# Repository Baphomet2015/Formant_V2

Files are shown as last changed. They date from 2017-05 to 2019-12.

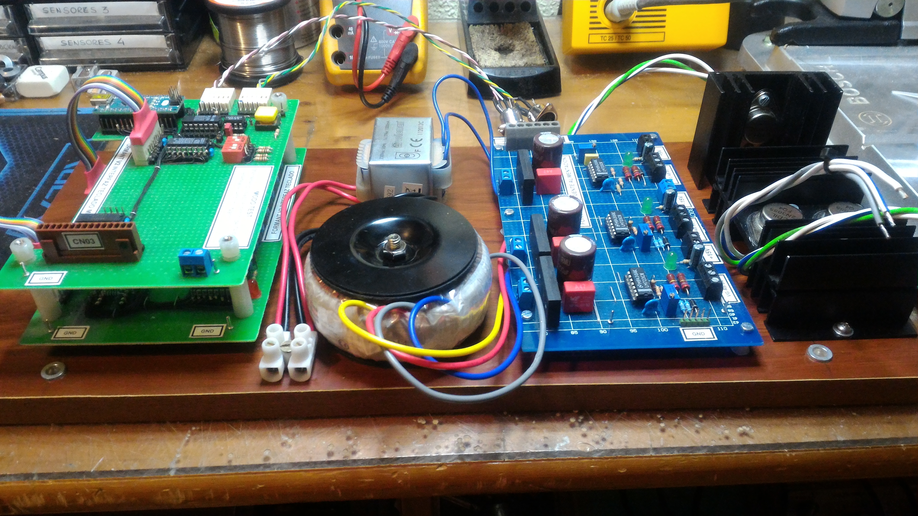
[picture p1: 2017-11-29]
Componentes_Mecanicos/Mueble_Racks/Fotos/P_20171127_214126.jpg

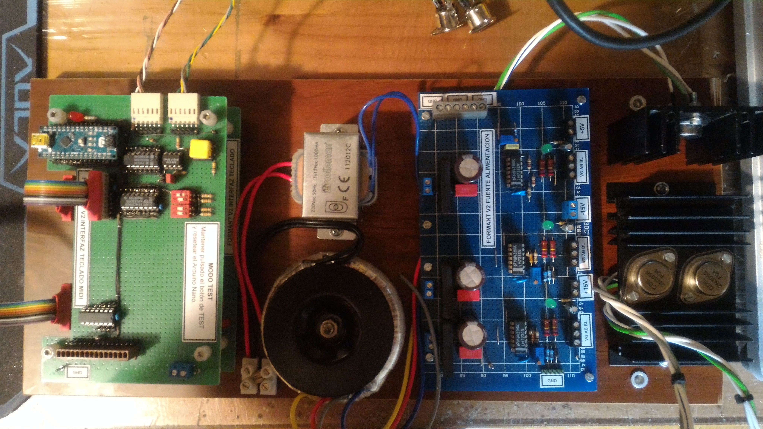
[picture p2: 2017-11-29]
Componentes_Mecanicos/Mueble_Racks/Fotos/P_20171127_214150.jpg

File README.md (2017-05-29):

# FORMANT V2.0
Proyecto de Sintetizador de música analógico.

En la edición de mayo de 1977 de la revista de electrónica **Elektor** se publicó el primero de una serie de artículos dedicados al Formant, un sofisticado sintetizador musical analógico modular con características y sonido profesionales.

En el presente proyecto se ha recopilado toda la documentación disponible en internet del Formant original, asi como de sus extensiones.

El objetivo de este proyecto, denominado **Formant 2.0** es:

 1. Mantener *esctríctamente* el diseño original del Formant de Elektor para obtener la calidad de sonido y prestaciones soportadas en el diseño original.
 
 2. Actualizar la documentación del diseño original del sintetizador Formant de Elektor para que sea posible su construcción hoy en día, con componentes actuales, sustituyendo los componentes obsoletos por otros disponibles actualmente en el mercado.
 
 3. Aportar en el nuevo diseño características de control digitales, basadas en microprocesador utilizando la plataforma **Arduino** y otros.

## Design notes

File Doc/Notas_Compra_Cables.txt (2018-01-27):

Sitio para comprar los cables de conexion entre modulos
https://www.modularsynthesizers.nl/c-2281945/patchcables-midi-cables/

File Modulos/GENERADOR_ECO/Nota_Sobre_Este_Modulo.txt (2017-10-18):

Para crear el generador de eco  se debe utilizar el Arduino DUE

http://www.frenki.net/2013/10/fast-analogread-with-arduino-due/
http://www.djerickson.com/arduino/due_adc.html

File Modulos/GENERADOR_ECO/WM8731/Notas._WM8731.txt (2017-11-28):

https://arduino.stackexchange.com/questions/12689/interfacing-wm8731-code-to-arduino-due

http://www.electan.com/codec-shield-p-4366.html

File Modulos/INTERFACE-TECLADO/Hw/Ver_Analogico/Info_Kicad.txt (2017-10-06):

Los ficheros de extensión,

 .pro
 .sch
 .lib
 .bak
 .kicad-pcb

Han sido realizados con el software Open Source de diseño de circuitos Kicad,

http://kicad-pcb.org/

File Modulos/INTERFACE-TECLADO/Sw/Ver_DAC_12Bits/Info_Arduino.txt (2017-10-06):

Los ficheros de extensión,

 .h
 .ino
 .lib

Ha sido realizados con el software Open Source de desarrollo Software/Hardware de la plataforma Arduino,

https://www.arduino.cc/

Se ha utilizado la versión 1.6.4

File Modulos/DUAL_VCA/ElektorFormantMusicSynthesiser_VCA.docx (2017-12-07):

070— FORMANT

chapter 10

voltage controlled amplifier (VCA)

This chapter continues the discussion of the tone-forming circuits with a description of the Dual VCA module, which can be used in conjunction with the envelope shaper for dynamic control signal amplitude, and
also for • riodic amplitude modulati • n of the signal waveform (tremolo

The voltag' controlled amplifier module is called • 'Dual VCA' because it contains t o cascaded, but independently con rolled, amplifiers. The gain of the first • mplifier is voltage controlled via an expo ential converter, and is used for envelop shaping. The second has a linear gain-c •ntrol input and is used for periodic mollulation of signal amplitude (tremolo). TI e VCA is provided with a modulation ndicator, which allows the best comp omise to be obtained between si nal-t

overload mar

Connection • f the VCA in the synthesiser slam

Figure 1 illustrates how the VCA fits into the synthesiser system. The VCA takes its input from the output of the VCF, which in turn takes its input signal from the VCOs.

The VCF and VCA can both be controlled by the ADS R envelope shapers, so allowing dynamic variation of tone colour and amplitude during the playing of a note. However, the VCF has a KOV input from the keyboard to allow it to function as a tracking filter, but the VCA lacks this, since there is no pitch related control of signal amplitude.

Using the VCA and the VC F

It may be interesting at this point to spend a little time comparing and contrasting the effects produced by the VCA and VCF, and discussing how they are used to complement one another in the synthesiser system. As an example, consider the case where the VCA and VCF are both controlled by the same waveform from the envelope shaper, consisting of a rapid attack and a relatively slow exponential decay, as shown in figure 2a, and are fed with a 440 Hz sawtooth waveform.

If the VCF is used alone in the lowpass
mode and the cutoff frequency of the

filter is initally set very low, the input signal will be completely suppressed. Yiviivem -wring Vitt Wank phase of the envelope control waveform the cutoff frequency of the filter vill rise very rapidly, and the amlitude and harmonic content of the note will both increase as first the fundamental, then the harmonics, are passed. During the slow decay phase the note will die away slowly as the cutoff frequency falls, starting with the higher harmonics, then the lower harmonics, anc finally the fundamental. The variatioi in turnover frequency of the filter is illustrated in figure 2b.

The tone thus produced .s not unlike that of a clavichord, or of a piano which has had drawing pins stuck into the hammers to produce a jaagly, honky-tonk effect.

If the same signal and control waveforms are fed to the VCA, the signal amplitude will rise rapidly as the gain increases during the attack phase, and will fall away slowly during the decay phase. However, the harmonic content of

signal will remain unaltered The sound thus produced is similar to that of percussion instruments stch as the piano and xylophone.

By varying the attack and decay times of the envelope shapers a vide variety of tone colour and amplitude dynamics can be produced using tin VCF and VCA in conjunction.

VCA design considerations

The dual VCA contains two amplifiers whose gains are independently voltage-controllable, and the design 3f the VCA poses certain problems, the principal one being that of obtaining adequate dynamic range, as is illustrated in figures 3a to 3d.

Figure 3a shows a control contour from the envelope shaper. At the peak of the control contour the VCA must have a finite maximum gain, which, for the purposes of the discussion, it will be assumed is unity, or 0 dB. At the beginning and end of the note the signal must be inaudible, which means that the gain of the amplifier should ideally be infinitesimally small at these moments in time. In practice, if the gain is around —70 dB•then this will be adequate.

What happens if the dynamic range is inadequate is shown in figure 3b. Suppose the gain of the amplifier can be varied by a range of only 40 dB or so, and is set to 0 dB on the peak of the control contour. At the start and end of the note the signal will only be 40 dB down, and if the note is being played fortissimo then this residual signal will still be quite audible.

Another fault of badly-designed VCAs is illustrated in figure 3c. In this example, the VCA cuts off completely below a certain level of control voltage, and so misses part of the attack and decay period of the note. This might be said to be the opposite fault to that of

figure 3b, though it is not directly related to dynamic range, but rather to extreme non-linearity of the control characteristic.

Returning to the example of the VCA with only 40 dB dynamic range, if the gain is adjusted so that the signal is inaudible at the beginning and end of the note (i.e. some 70 dB down), it will only be able to increase by 40 dB when the control voltage is applied, instead of the 70 dB required to reach the 0 dB level. The result is an amplitude plateau, as shown in figure 3d.

As mentioned briefly earlier, control of the envelope shaping section of the VCA is carried out exponentially. This is to compensate for the logarithmic loudness response of the human ear. On the other hand control of the periodic amplitude modulation section (tremolo) is linear, since this gives the 'softest' and `sweetest' sound to the tremolo effect.

Principle of the Formant VCA

The VCA in Formant uses the CA3080 OTA as the controllable amplifier, as in the VCF. The principle of the Formant VCA is illustrated in figure 4. The input voltage Ui is converted to a proportional output current Io = gm • 14 However, since we are interested in voltage amplification this output current must be converted into an output voltage, and this is done simply by feeding the current through a load resistor RL to produce an output voltage U0 = gm • Ui • RL.

The transconductance of the amplifier, gm, may of course be varied by a control current IABc, as explained in chapter 6, and the gain of the VCA may thus be controlled — although at this stage of course it is a CCA!

The output of the OTA may not drive any external load in addition to RL, as this would lower the load impedance and alter the gain, so the output of the OTA is connected to a voltage follower/buffer with a high input impedance.

Both sections of the VCA operate on the same principle. However, only the output of the second OTA is buffered, since it is this output that is connected to any external loads. As the output of the first OTA has no external connection it is simply connected to the input of the second OTA.

The OTA has one disadvantage that cannot be ignored. As mentioned in the previous chapter, its linearity is good only for small input signals (typically ± 10 mV) which is why a large degree of input signal attenuation is required. This means that the signal-to-noise ratio is not exceptionally good, and for this reason it is best to use the VCA with the largest possible input signal consistent with low distortion. A modulation indicator is provided, which allows the best compromise to be obtained between excessive noise, at low input levels, and distortion at high input levels.

FORMANT — 071

Figure 1. Block diagram illustrating how the
VCA fits into the Formant synthesiser system.

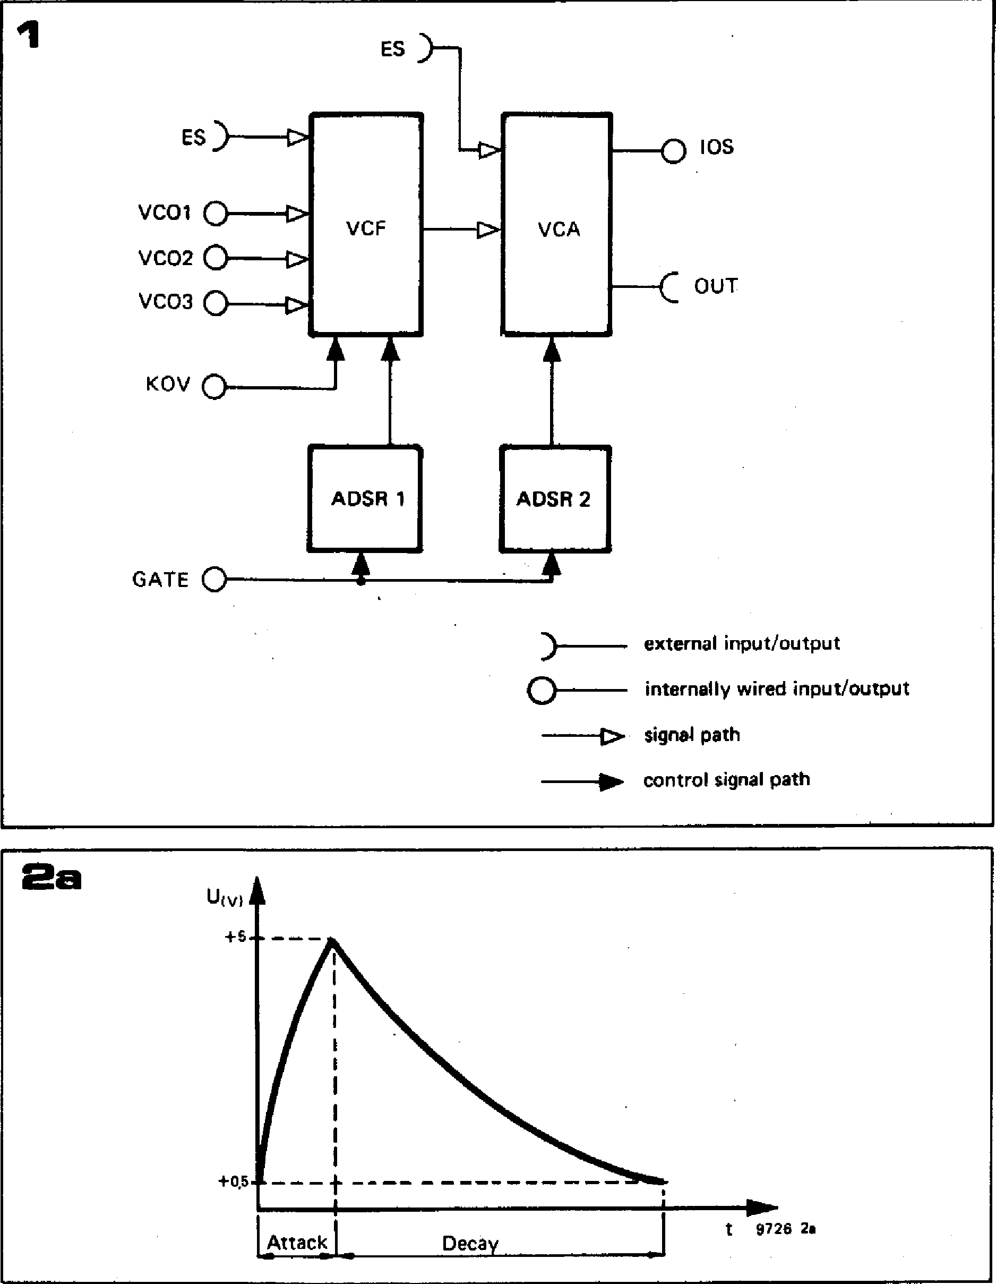
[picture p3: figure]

VCF

VCA

+5

ADSR 1

ADSR 2

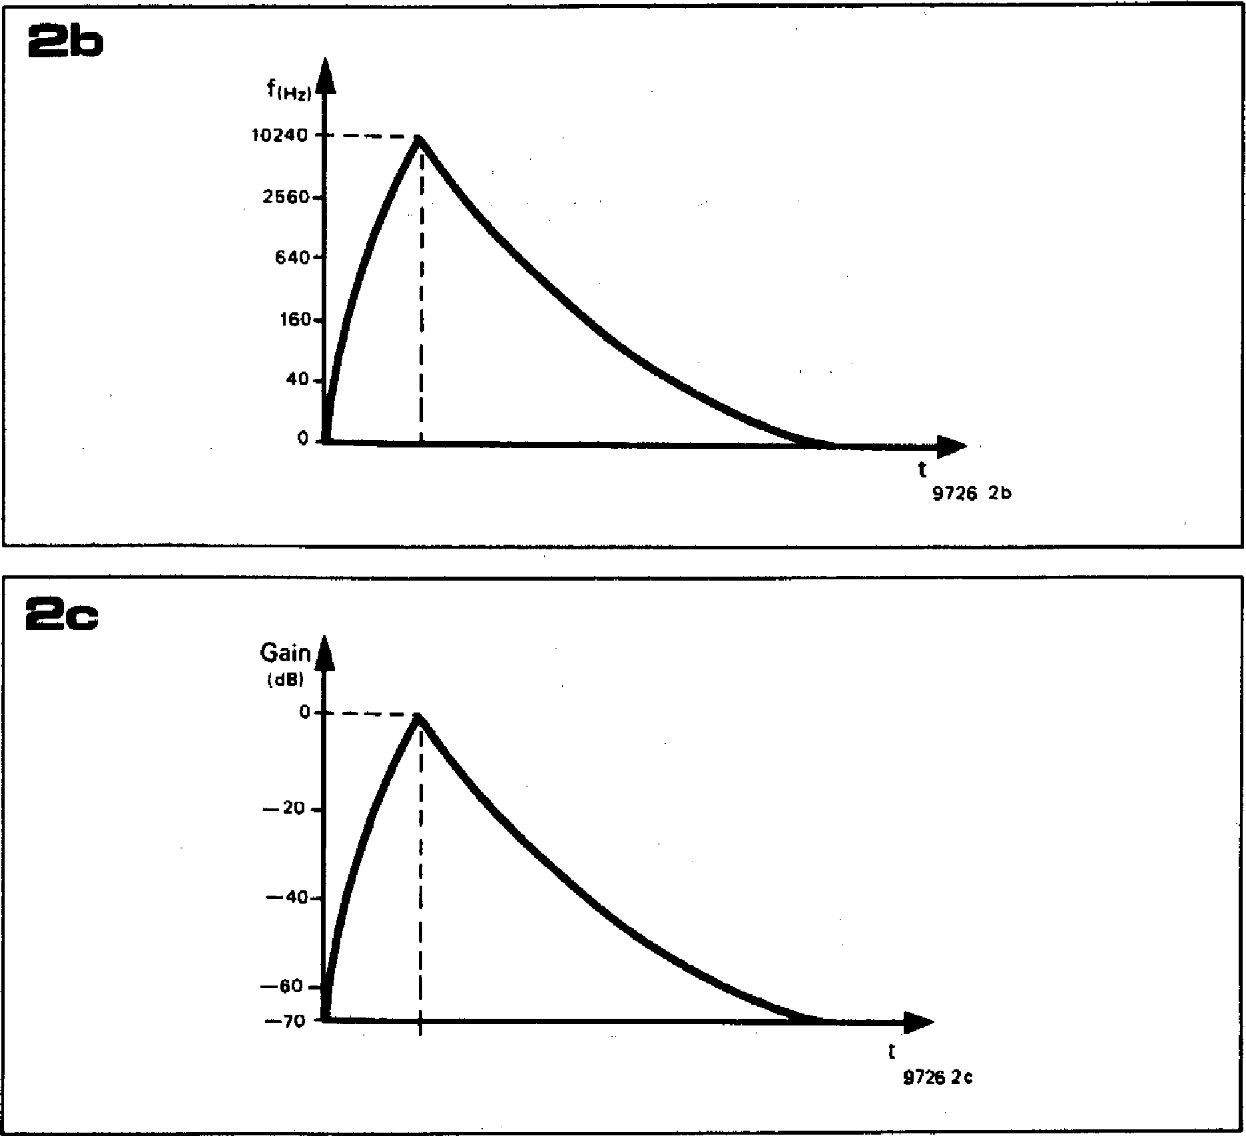
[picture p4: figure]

Figure 2. Envelope control of the VCF and VCA. The attack-decay contour of figure 2a, when applied to the VCF, varies the turnover frequency of the filter, which provides dynamic alteration in the tone colour of the sound (figure 2b). When applied to the VCA, the envelope contour alters the gain of the VCA, and thus the amplitude of the sound (figure 2c).

Circuit of the. VCA

The complete circuit of the VCA is given in figure 5. The exponential converter built around IC1 and 1C3 will immediately be recognised, since it is very similar to that used in the VCF. The input configuration, however, is much simpler, there being but one external input, ENV, from the envelope shaper. If required this can be switched out by setting Si in position 'a', in which case a fixed gain results.

The gain/control voltage characteristic of the VCF is roughly 12 dB/volt, but as the use of the word 'roughly' suggests, the accuracy of this characteristic is relatively unimportant, unlike the octave/volt characteristics of the VCO and VCF. The ear is much less critical of amplitude errors than it is of frequency errors. The dB/volt characteristic of the VCA may be adjusted by P2, whilst P1 is an offset trimmer. The output current of the exponential converter controls the gain of the first OTA, 106.

The linear voltage-current converter is constructed around IC2, which is connected as an inverting, summing amplifier. An input signal may be fed to P4 via the AM input socket, and a DC input voltage is available from P3 (`Gain'). Both these input voltages cause proportional currents to flow through R12 and R 13, and since these currents cannot flow into the inverting input of the op-amp they flow round the feedback loop through T 1, and into the control input of IC7.

The audio signal to the VCA comes either from the permanently wired internal signal input (IS) or from the external signal socket (ES) on the front panel of the VCA module. The amplitude of the external input signal is controlled by P5, whereas the amplitude of the internal signal is controlled at the IOS output of the VCF, by P6 of the VCF module.

IC4 functions as a summing amplifier with a gain of —1, and the signal level at the output of IC4 is monitored by the modulation indicator constructed around IC5. This is a non-inverting amplifier feeding a bridge rectifier D1 to D4, the output of which drives the modulation indicator LED D5. Once the

072 — FORMANT

peak signal level at the output of 105 exceeds the combined knee voltages of 131 plus D5 plus D4 (or D3 plus D5 plus D2) then the LED will start to glow and will glow brighter as the signal level increases. P6 is used to adjust the gain of 105 so that D5 starts to glow at the signal level where overmodulation begins to occur.

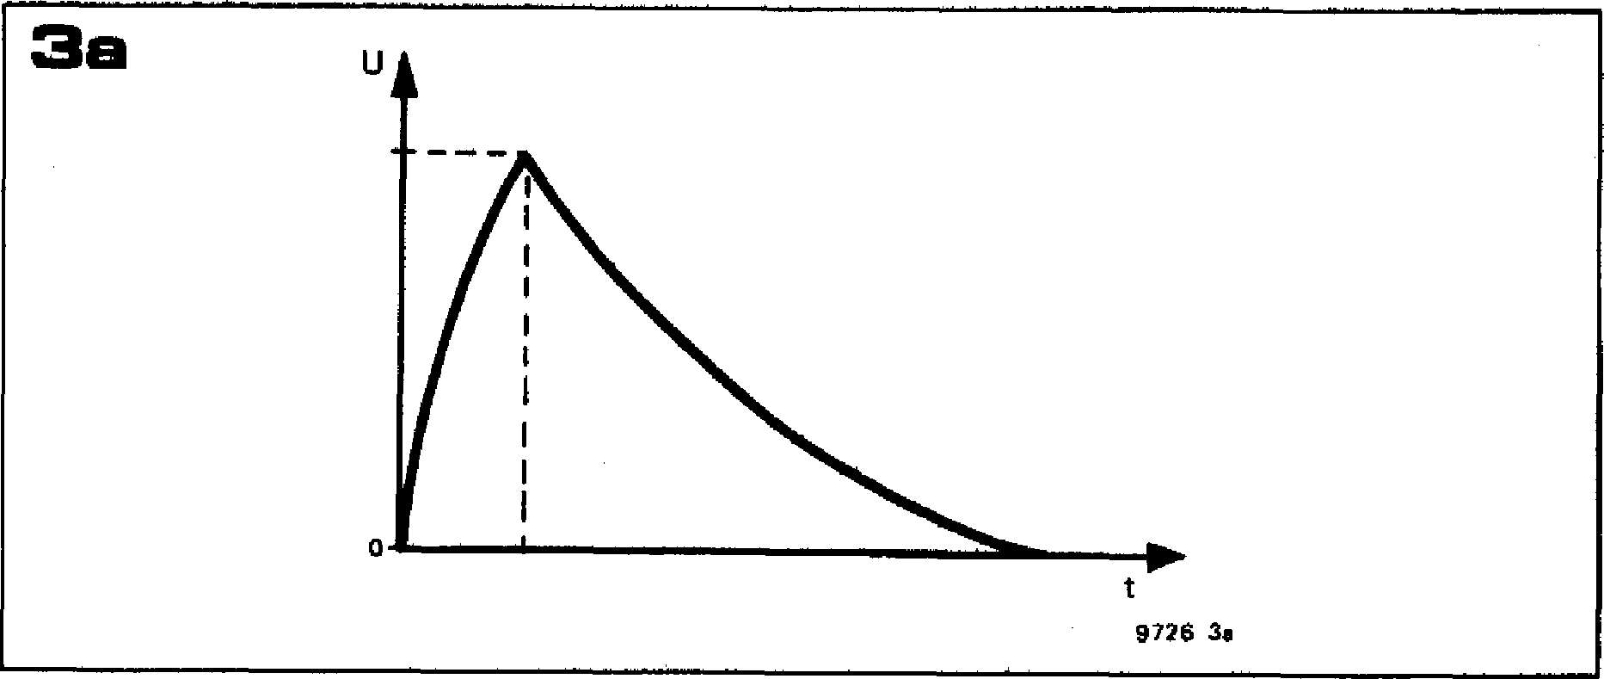
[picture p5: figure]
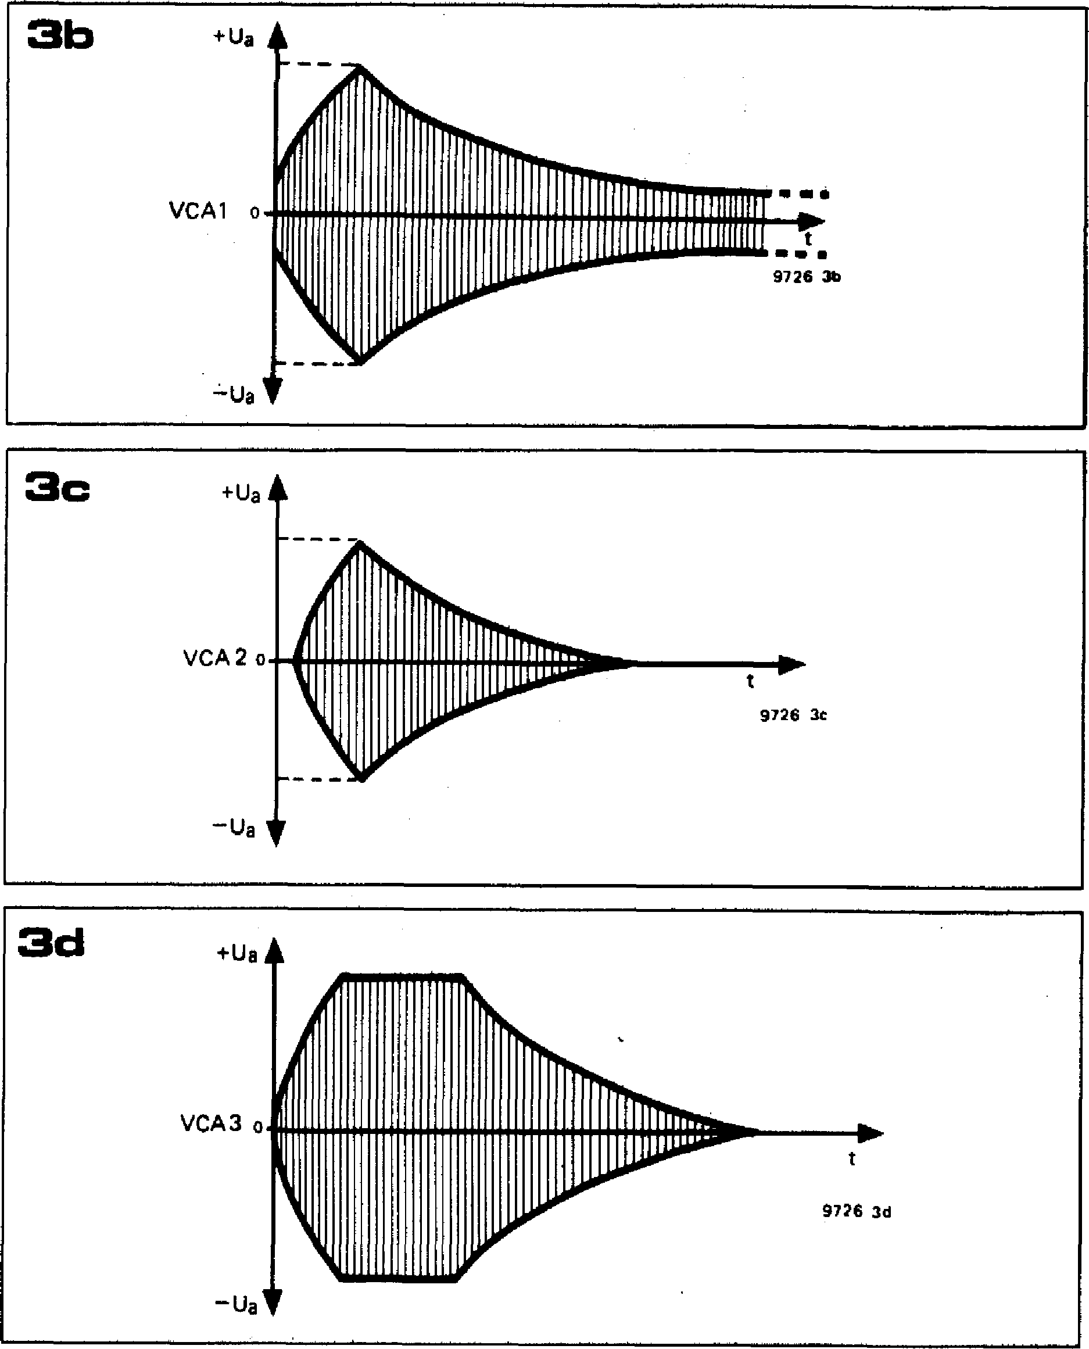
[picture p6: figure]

3b

9726 3e

+Ua

3d

a

9726 3d

VCA 3 0

l• •

3c +ua

VCA 2 0

a

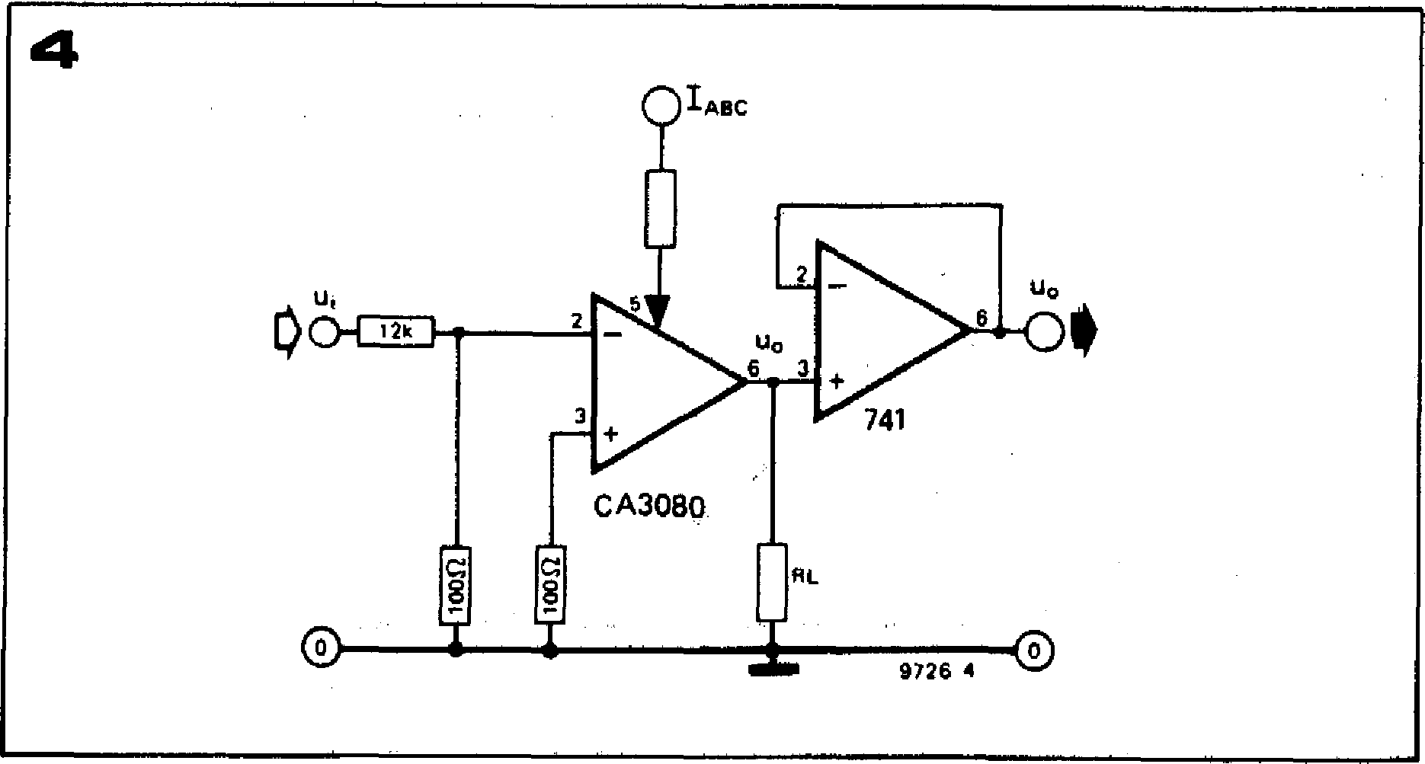
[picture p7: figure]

The output signal from 1C4 is attenuated by R19 and R20 down to a level which the OTA, 106, can handle. The output of the exponentially controlled OTA, 106, is fed via a second attenuator R25/R26, to the input of the linearly-controlled OTA, 1C7. The output of 1C7 is buffered by voltage-follower 1C8 and two outputs from the VCA are provided, an internally wired output, 10S, and an output to a front panel socket, EOS. Potentiometers P7 and P8 are provided for trimming the offset voltages of IC6 and IC7.

Construction

The comments with regard to component quality that have been made in previous chapters apply equally to the construction of the VCA, and will not be repeated. A printed circuit board and component layout for the VCA are

Figures 3a to 3d. Some typical faults of badly-designed or badly-adjusted VCAs are illustrated here. None of the amplitude envelopes in figures 3b to 3d follows the control contour of figure 3a.

In figure 3b there is feedthrough of the signal after the control contour finishes; in figure 3c the signal is still cut off for some time after the control contour starts, and cuts off again before it finishes:. in figure 3d the VCA has insufficent headroom and limits causing a 'plateau' on top of the envelope curve.

Figure 4. The principle of the Formant VCA is illustrated here. The OTA produces an output current proportional to the product of the Input voltage and the control current !Ag• This causes a voltage drop across the load resistor R L, and the output is buffered by an op-amp voltage follower. The input attenuator is necessary to avoid overloading the OTA.

Figure 5. Complete circuit of the Formant Dual VCA. This contains two, cascaded, voltage-controlled amplifiers with independent control inputs; exponential control for envelope shaping and linear control for amplitude modulation (tremolo).

FORMANT — 073

given in figure 6, and a front panel layout is given in figure 7.

Testing and adjustment

For optimum performance the VCA must be matched to a particular envelope shaper, and thereafter the VCA and envelope shaper should be used as a pair. This is not necessary in the case of the VCF, which may be used with any envelope shaper.

To test and adjust the VCA, the completed keyboard and interface receiver must be available, together with VCOs, VCF and the envelope shaper to which the VCA is to be matched. The IOS output of the VCO is connected to one of the VCO inputs of the VCF, and the IOS output of the VCF is connected to the IS input of the VCA. The GATE output of the interface receiver is connected to the GATE input of the envelope shaper and output ENV of the envelope shaper is connected to input ENV of the VCA.

For the initial test, the sawtooth output of the VCO is selected and the output level is set to maximum. The VCF is set to the lowpass mode, but the turnover frequency is set to maximum by turning the octaves control fully clockwise. The

Q control is set to minimum, the KOV input is switched off and the output level is set to maximum.

- At the IOS output of the VCF, the sawtooth signal from the VCO should now be available in phase with, and at the same amplitude as, the VCO output (about 2.5 V p-p).
- At the output of IC4 of the VCA, the signal should be available at the same level, but inverted.
- With S1. of the VCA in position 'a' (ENV input switched off) and P7 and P8 in mid-position, the sawtooth signal should be available at the output of IC6 in phase with the VCO output, and the amplitude should be adjustable by Pl.
- At the output of IC7 the signal should again be in phase, and both PI and P3 should vary the amplitude.
- Finally, the signal should be available at outputs IOS and EOS.

This concludes the basic functional check of the VCA, and the adjustment procedure can now be carried out.

Modulation indicator

Using the same input signal, P6 is adjusted until the modulation indicator D5 just begins to glow. Increase the signal amplitude by switching in the

second and third VCOs, when the LED should glow brighter.

After this test, the second and third VCOs should be switched off again.

Offset adjustment

Turn the output level of the VCF to zero and short the IS input of the VCA to ground. Set SI of the envelope shaper to 'AD' and the A, D, S and R controls to minimum (shortest attack and decay, and 0% sustain). Turn P5 of the VCA fully anticlockwise, set Si of the VCA to position 'b' (ENV) and observe the DC output voltage of IC6 on an oscilloscope.

When a key is depressed, a step output voltage will be observed at the output of IC6. This is the offset voltage of the IC, which is amplified as the gain of IC6 increases under the influence of the envelope control voltage; if it is not nulled out then it will break through to the output as 'cracks' or 'plops'. P7 is adjusted until the step voltage is as small as possible on the most sensitive range of the oscilloscope.

The offset nulling procedure must then be repeated for IC7. Si is switched to the `off position, P3 is turned fully anti-clockwise and the external output of the envelope shaper is connected to

5

R7 2k2

10

ICI

15V

0

T

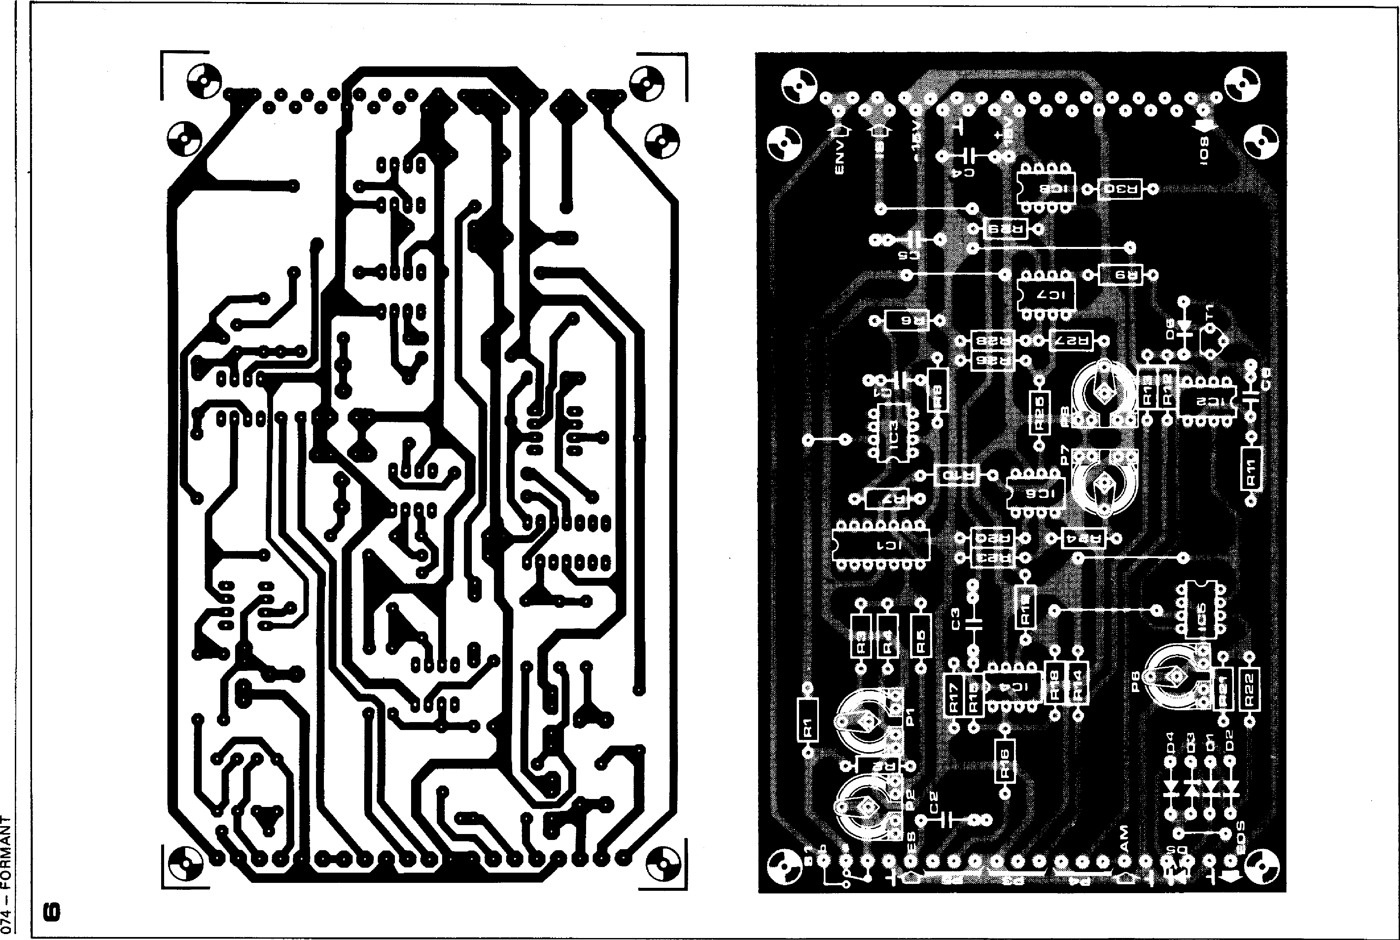
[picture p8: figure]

074 -- FOIRMANT

FORMANT — 075

Parts list for figures 5 and 6 Resistors:

R1 = 6k8

R2 = 3k3 R3,R15,R16,R18 = 100 k

R4 = 4k7

R5 = 47 k R6,R8,R24,R27 = 330 k

R7,R11,R14 = 2k2

R9,R10 = 27 k

R12,R13,R19,R25 = 12 k

R17 = 33 k R20,R23,R26,R28 = 100 St

R21 = 3k9 R22,R30 = 470 St

R29 = 15 k (nominal value,

see text)

Potentiometers:

P1,P2,P7,P8 = 100 k preset

P3 = 1 k lin.

P4 = 10 k lin.

P5 = 100 k log.

P6 = 4k7 (5 k) preset

Capacitors:

C1,C6 = 1 n

C2,C3,C4,C5 = 680 n

Semiconductors:

1C1 = CA 3084 (DI L package)

1C2,1C3,IC4,IC5, IC8 = AA 741C,

MC 1741 CP1 (Mini DIP) IC6,1C7 = CA 3080 (A)

T1 = BC 177B, BC 178C, BC 179C,

BC 5578, BC 558C, BC 559C D1 ... D4 = DUG (0A91,

AA118, AA119)

D5 = LED (TIL 209 or similar)

D6 = 1N4148

Miscellaneous:

31-way Euro connector

(DIN 41617)

S1 = SPST miniature toggle.

switch

3 off, 3.5 mm jack socket

3 off, 13-15 mm collet knobs with pointer

Figure 6 Printed circuit board and component layout for the VCA (EPS 97261 ).

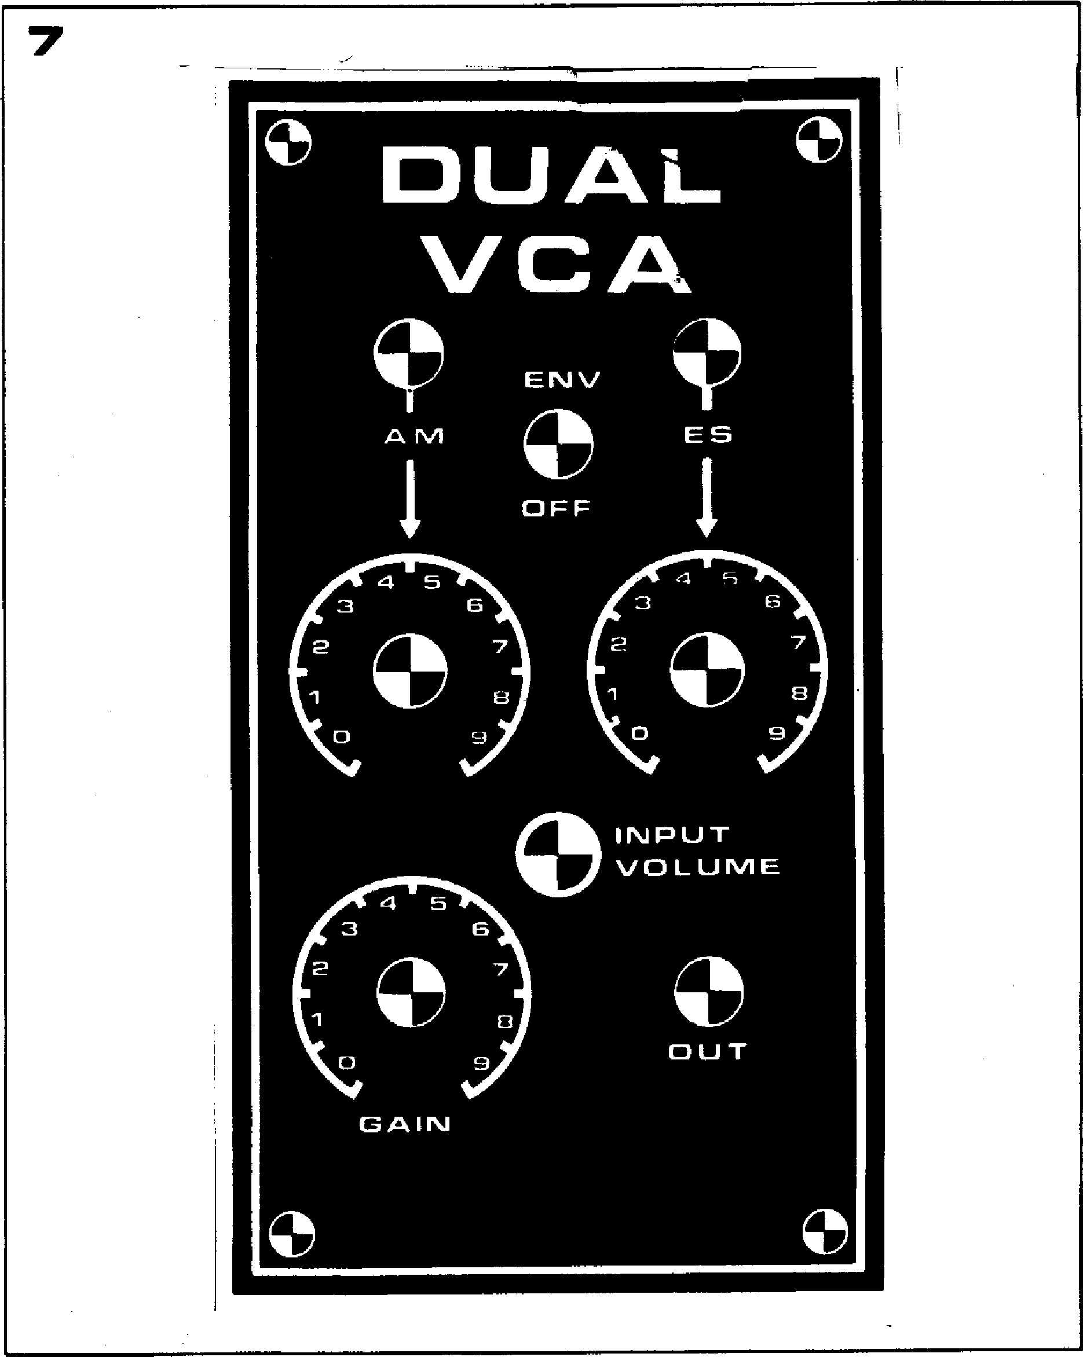
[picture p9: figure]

Figure 7 Front panel layout of the VCA. is located between the AM and ES input sockets. Immediately below these sockets are the respective input level controls: P4 sets the AM modulation depth and P5 is the external input level control Below these again are the modulation indicator (D5), the manual gain control (P3) and the output socket (EOS).

the AM input of the VCA. The IOS output of the VCA is monitored on the oscilloscope and the offset nulling procedure is repeated, this time using P8.

Adjustment of exponential gain control

The exponential converter must be adjusted so that the required gain control range of IC6 is obtained from the +0.5 V to +5 V range of the envelope shaper.

Si of the envelope shaper is set to the `AD' position and fairly short attack and decay times are selected. The short circuit across the VCA input is removed, the VCF level control is turned to maximum and a signal is fed in from one of the VCOs. P2 on the VCA board is initially set to its mid-position.

The output of 106 is now monitored with an oscilloscope and a key is repeatedly depressed, when AD envelope curves should be seen. P1 is then adjusted for minimum feed through when the key is not depressed, less than one or two millivolts will be acceptable. The Y sensitivity of the oscilloscope is now adjusted so that the entire envelope curve can be seen when a key is depressed. P2 should then be adjusted until a good attack/decay curve without limiting (seen as a flat top or plateau as

shown in figure 3d) is just obtained. Since P1 and P2 interact to some extent, it may be necessary to repeat the adjustment procedure several times to obtain the best results.

Adjustment of overall gain

The overall gain of the VCA should be

dB (unity) at maximum modulation of IC6 and 1C7. To achieve this it may be necessary to alter the value of R29, which is nominally 15 k. Set the gain control P3 to maximum, and the envelope shaper to the 'ADSR' mode with 100% sustain. A key is now depressed and held down, and the output level of the VCA (at IOS or EOS) is compared with the input level at IS. These levels should be the same; if the output level is too low, then R29 must be increased in value, and if the output level is too high then R29 must be reduced. A 3 dB difference (x 0.707 or x 1.414) between the input and output levels is acceptable.

This completes the adjustment of the VCA.

Use of the VCA

The input signal level to the internal
input of the VCA is controlled by the
output potentiometer of the VCF. In

076 — FORMANT

normal use this control should be adjusted so that the LED just begins to glow, which occurs at a nominal level of 2.5 V p-p with one VCO input signal, less if more than one VCO is connected. If the LED glows brightly, then the VCA is being overmodulated and distortion may occur. This is not to say that this should never be allowed to happen, since the deliberate introduction of distortion can be used to produce `fuzz' effects. If the LED does not glow, then this indicates under-modulation and the possibility of a poor signal-to-noise ratio.

Tremolo

To produce tremolo effects a low-frequency oscillator signal (LFO) can be fed into the AM input socket. The Formant LFOs, described later in the series, have an output voltage swing of ± 2.5 V, and if the GAIN potentiometer P3 is set in its mid-position this will give a modulation depth of 100%. Reducing the LFO input signal by means of the AM potentiometer P4 allows the modulation depth to be varied down to 0%.

Expression Pedal

An expression pedal may also be connected to the AM input. This can be a pedal fitted with a logarithmic potentiometer and battery, wh varied from zero to about +5 V with the, pedal fully deressed.

Tuning

The ENV /OFF switch SI is Orly useful when tuning JOW⁻ thasiser,
since it allows sign* to coati „ontinuously through the ift A, unaffected by the envelope shaper when in the

position.

Outputs

The external output of the VCA has an impedance of about 500 SZ, and this output may be fed to other equipment such as tape decks and external amplifiers, or to high impedance headphones for monitoring.

The internal output signal (I0S) is taken to the Formant amplifier module, which will be described later, This is fitted with tone and volume controls and a small power amplifier for monitoring purposes. It will drive low impedance headphones and loudspeakers, and can also be used to drive spring line reverberation units or other external equipment.

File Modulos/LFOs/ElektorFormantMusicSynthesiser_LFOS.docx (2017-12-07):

076 — FORMANT

LFOs and noise module

The low frequency oscillators and noise generator are invaluable components in a synthesiser system. The LFOs allow amplitude and frequency modulation of the VCO outputs to provide tremolo, vibrato and other effects. The noise sources can be used for random modulation of the VCO signals, and in addition can be used as signal sources themselves.

Mambos he* already been made of the figt that conventional instruments exhibit more 'life' and variation in tonal emaingir than ntectrosic instruments due hi the way in -which they are played. For example, sal lio instruments and woodwind insteps/lets can exhibit marked .tremolo Tit vibrato due to variations in the *who or blowing. The keyboard of a mgothosiser provides a• relatively inflexile sad expressionless means of playing' that does not allow these nuances to he introduced into the sound, and in order to make the sound more 'lively' ampillaide and frequency modulation must be introduced using the LFOs and noise 110111fCe.

The noise source AID provides the basic material to produce a whole spectrum of sounds that do not have a defined pitch. White no* can be used to produce sounds such as wind, rain and surf. 'Coloured' mein, which is white noise with the low frequency components boosted, is used for sounds having a strong b content, such as the rumbling of thunder.

In addition to modulating the VCO signals, noise can 116P0 be added to these signals to simulate wind noise in organ pipes and woodwind instruments.

The. FO_ „

frequency function produce three diff Each LEO module con tw

basically low

enerators that

nt waveforms.

s three LFOs,

al and produce

square, triangle and sawtooth

waveforms. The third LFO produces a triangular waveform and two sawtooth waveforms in antiphase with each other, i.e. one with a positive-going ramp and the other with a negative-going ramp.

The circuit of LFO1 is shown in figure la; LFO2 is identical. The basic oscillator circuit consists of two op-amps IC1 and A3 connected respectively as an integrator and a Schmitt trigger. When the output of A3 is positive a potential of about +2.5 V (depending on the position of the wiper of P3) is applied to R9. The full positive output voltage of A3 is applied to Pl, so a current (dependent on the wiper position of P1) flows into the integrator through RI . The output of IC1 ramps negative until it reaches about —2.5 V, when the voltage on the non-inverting input of A3 will fall below the voltage on the inverting input (zero volts) and the output of A3 will swing negative. The voltage applied to R9 is now —2.5 V, and the full negative output voltage of A3 is applied to P1. Current will flow out of the integrator through RI, and the integrator output will ramp positive until it reaches about +2.5 V, when the voltage on the non-inverting input of A3 will rise above zero and the output of A3 will swing positive. The whole cycle then repeats.

The output from IC1 is thus a triangular waveform with a peak-to-peak voltage of about 5 V, while at the wiper of P3 a squarewave of the same amplitude and frequency is available. P3 presets the trigger threshold of A3 and hence the signal amplitude. P1 is used to adjust the frequency of the LFO by varying the voltage applied to the integrator input, which alters the integrator input current and hence the rate at which the integrator ramps positive or negative. The triangular wave output is taken direct from IC1 via R13, whilst the squarewave output is buffered by voltage follower A4. The sawtooth waveform is derived from the triangle by A2. When the output of A3 is positive and the triangle output is on its negative-going slope, T1 is turned on, grounding the'non-inverting input of A2. A2 thus functions as a unity-gain inverting amplifier, producing a positive-going ramp. When the output of A3 is negative and the output of IC1 is positive going, Ti is turned off and A2 functions as a unity-gain non-inverting amplifier (voltage follower), again producing a positive-going ramp. The positive- and negative-going ramps of the triangular waveform are thus converted into a series of positive-going ramps. Since every half-cycle of the triangle is converted into a full cycle of the sawtooth, the frequency of the sawtooth is twice that of the triangle and square waveforms, as illustrated in figure 2.

To indicate that the LFO is functioning a LED indicator, constructed around Al , is connected to the triangle output.

FORMANT — 077

Figure la. Circuit of LFO 1, which is identical to LFO 2 and produces triangle, sawtooth and square waveforms.

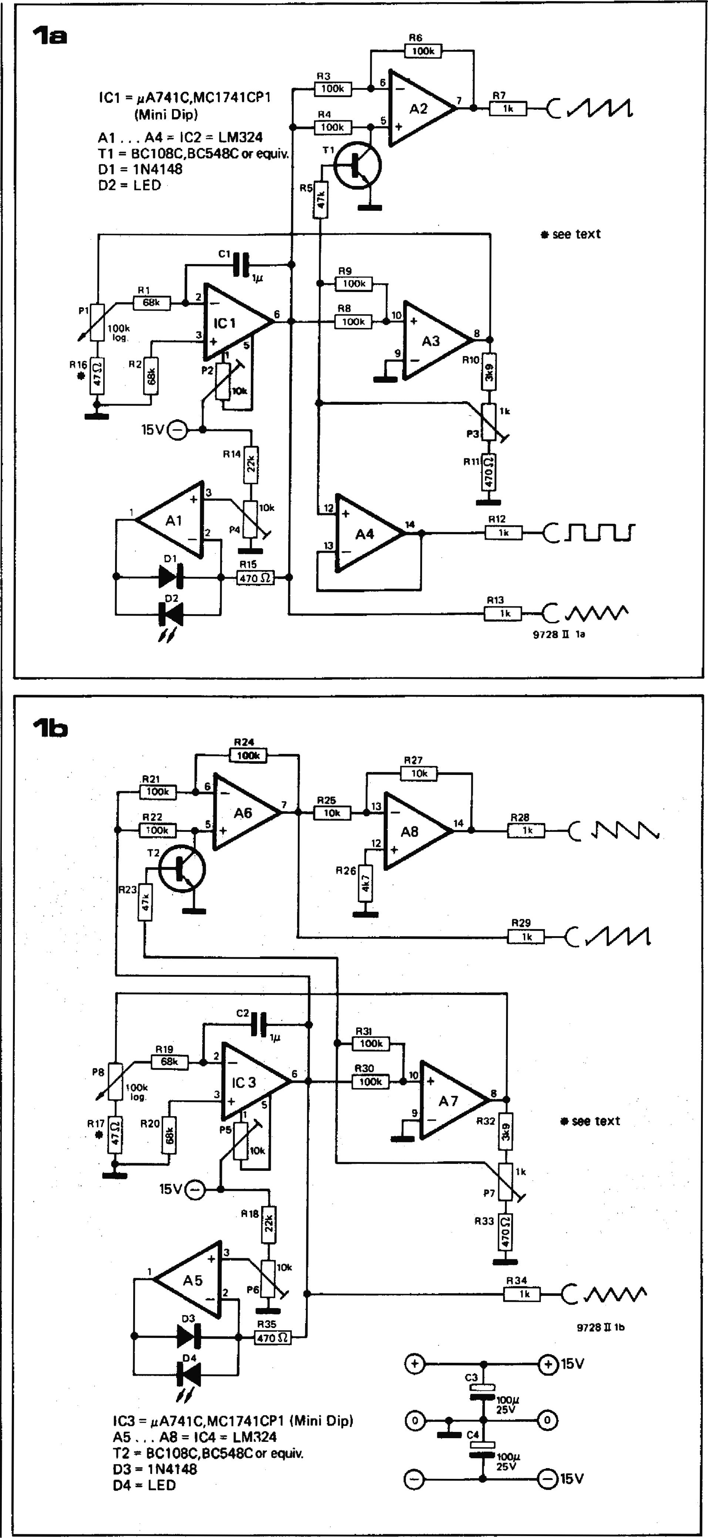
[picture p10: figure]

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
015V

lb

R33

P6

R34

Figure lb. LFO 3 also produces three waveforms, but instead of a squarewave output a negative-going sawtooth is provided.

The third LFO circuit, shown in figure lb, is similar to the first circuit, with two exceptions. Firstly, no squarewave output is provided; secondly, a sawtooth with negative-going slope is provided by A8, which inverts the positive-going sawtooth from A6.

Construction of the LFO module Figure 3 shows the printed circuit board and component layout of the LFO module, which of course contains three LFOs. The components for LFO2 are identical to those for LFO1, being distinguished on the board and in the components list by an apostrophe ('). The board layout is fairly cramped, and care should be taken when soldering components to avoid solder bridges. A front panel layout is given in figure 4.

Adjustment of the LFOs

Each LEO requires four adjustments:
P3, P3' and P7 set the signal amplitude.

- P2, P2' and P5 null the offset of the integrators.
- R16, R16' and R17 must be selected to set the lowest frequency of the LFO.
- P4, P4' and P6 adjust the LED indicators.

The adjustment procedure, which is identical for all three LFOs, will be described for LFO1.

Amplitude adjustment

1. Monitor the triangle output on an oscilloscope; set P2 to its mid-position and P1 for maximum frequency.
2. Adjust P3 to give a peak-to-peak output of 5 V.
3. Check the amplitude and waveform of the other outputs.

Offset adjustment

1. Disconnect RI from the wiper of PI and ground it.
2. Monitor the output voltage of IC1 with a multimeter. It will probably exhibit a tendency to drift positive or negative, and the voltage will settle at +15 V or —15 V. Reset the

0711— FORMANT

output voltage to zero by discharging Cl through a 1 k resistor. Adjust P2 until the voltage remains stable at zero volts for a period of several seconds (without the discharge resistor in circuit). Repeat this adjustment, progressively switching the multimeter to more sensitive ranges until the drift is only a few hundred millivolts in several seconds.

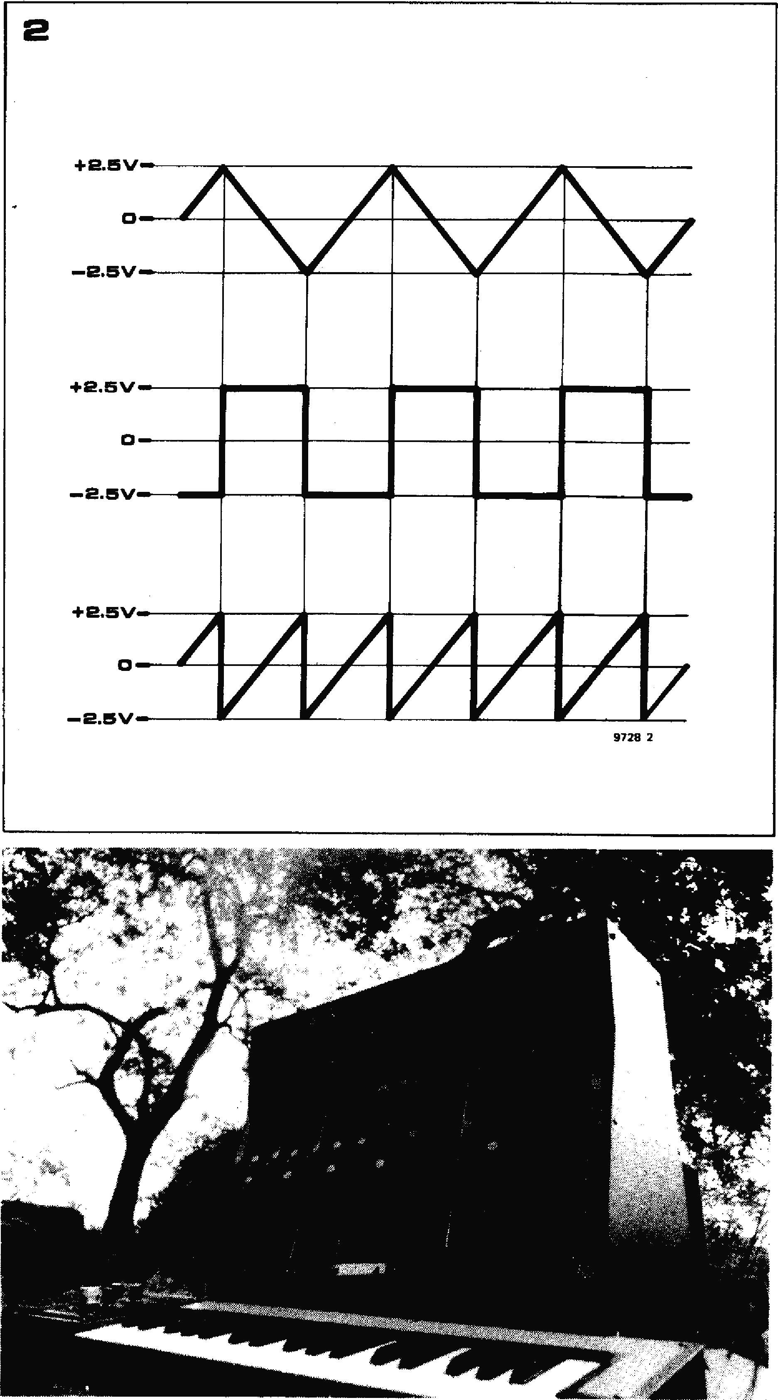
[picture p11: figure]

Careful adjustment of the offset is vital,
as it determines the minimum fre-
quency at which the LFO will operate

reliably and the symmetry. of the waveforms at low frequencies.

Selection of R16

The value of R16 determines the minimum integrator input voltage that can be set by Pl, and hence the minimum frequency of the LFO. The value of R16 must not be chosen too high or the minimum LFO frequency will be too great. On the other hand it should not be chosen too low, or the integrator input current at the minimum

Figure 2. Showing the phase relationship of the triangle, square and sawtooth waveforms. Since the sawtooth is derived by inverting alternate half-cycles of the triangle waveform, its frequency is twice that of the other waveforms.

Figure 3. Printed circuit board and

component layout for the LFO module (EPS 9727-11.

setting of PI will be comparable with the input currents of ICI. This will result in unreliable operation of the oscillator at low frequencies.

R16 should be chosen so that the minimum frequency of the LFO is about one cycle every three minutes, but the value of R16 should not be less than 10 S2. If it is not possible to obtain this low frequency then the input currents of IC1 may be too high, or Cl may be leaky.

The maximum LFO frequency is about 20 Hz.

FORMANT — 079

R10,R10',R32 = 3k9

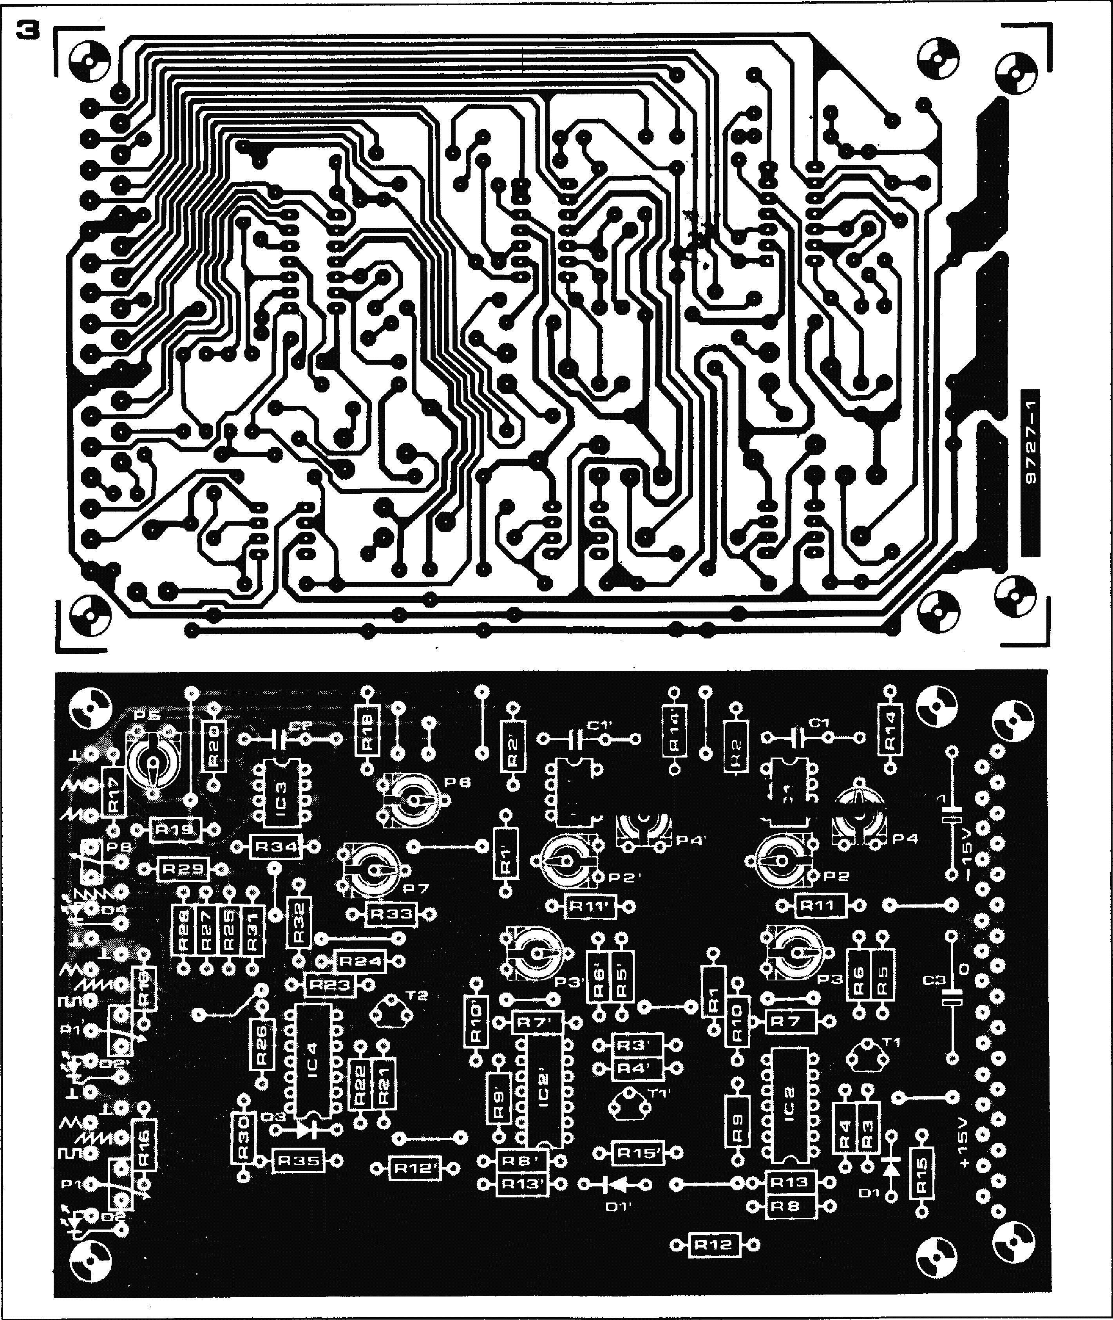
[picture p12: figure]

Parts list for LFO module | R11,R11',R15,R15',R33, R35 = 470 n | Semiconductors: 1C1,IC1',IC3 =ALA 741C, | Capacitors: C1,C1',C2 = 1 g (polyester or
Resistors: | R14,R14',R18 = 22 k | MC 1741CP1 (Mini DIP) | polycarbonate)
R1,R1',R2,R2',R19,R20 = 68 k | R16,R16',R17 = 47 St (see text) | 1C2,1C2',IC4 = LM 324 (DIP) | C3,C4 = 100 )2/25 V
R3,R3',R4,R4',R6,R6',R8,R8', R9,R9',R21,R22,R24,R30, | R26 = 4k7 | T1,T1',T2 = BC 108C, BC 548C or equivalent | Miscellaneous:
R31 = 100 k | Potentiometers: | D1,D1',D3 = 1N4148, 1N914 | 31-way connector (DIN 41617)
R5,R5',R23 = 47 k | P1,P1',P8 = 100 k log | D2,D2',D4 = LED (e.g. TI L209) | 9 x 3.5 mm jack
R7,R7',R12,R12',R13,R13',R28, R29,R34 = 1 k | P2,P2',P4,P4',P5,P6 = 10 k preset P3,P3',P7 = 1 k preset | | 3 x 13 ... 15 mm knobs

080 — FORMANT

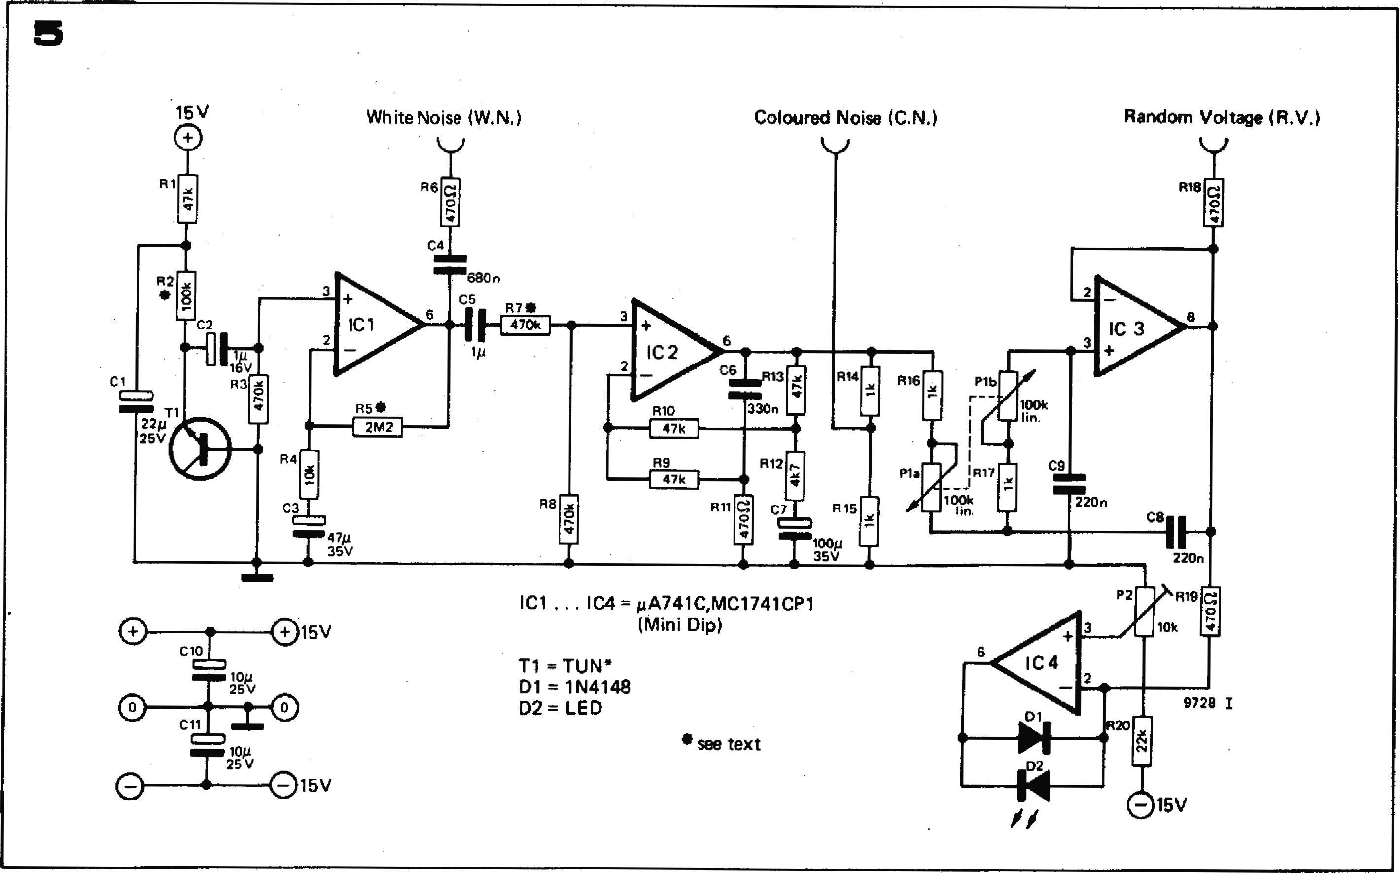
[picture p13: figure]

R8

15V

2

RO

R18

15V

R20

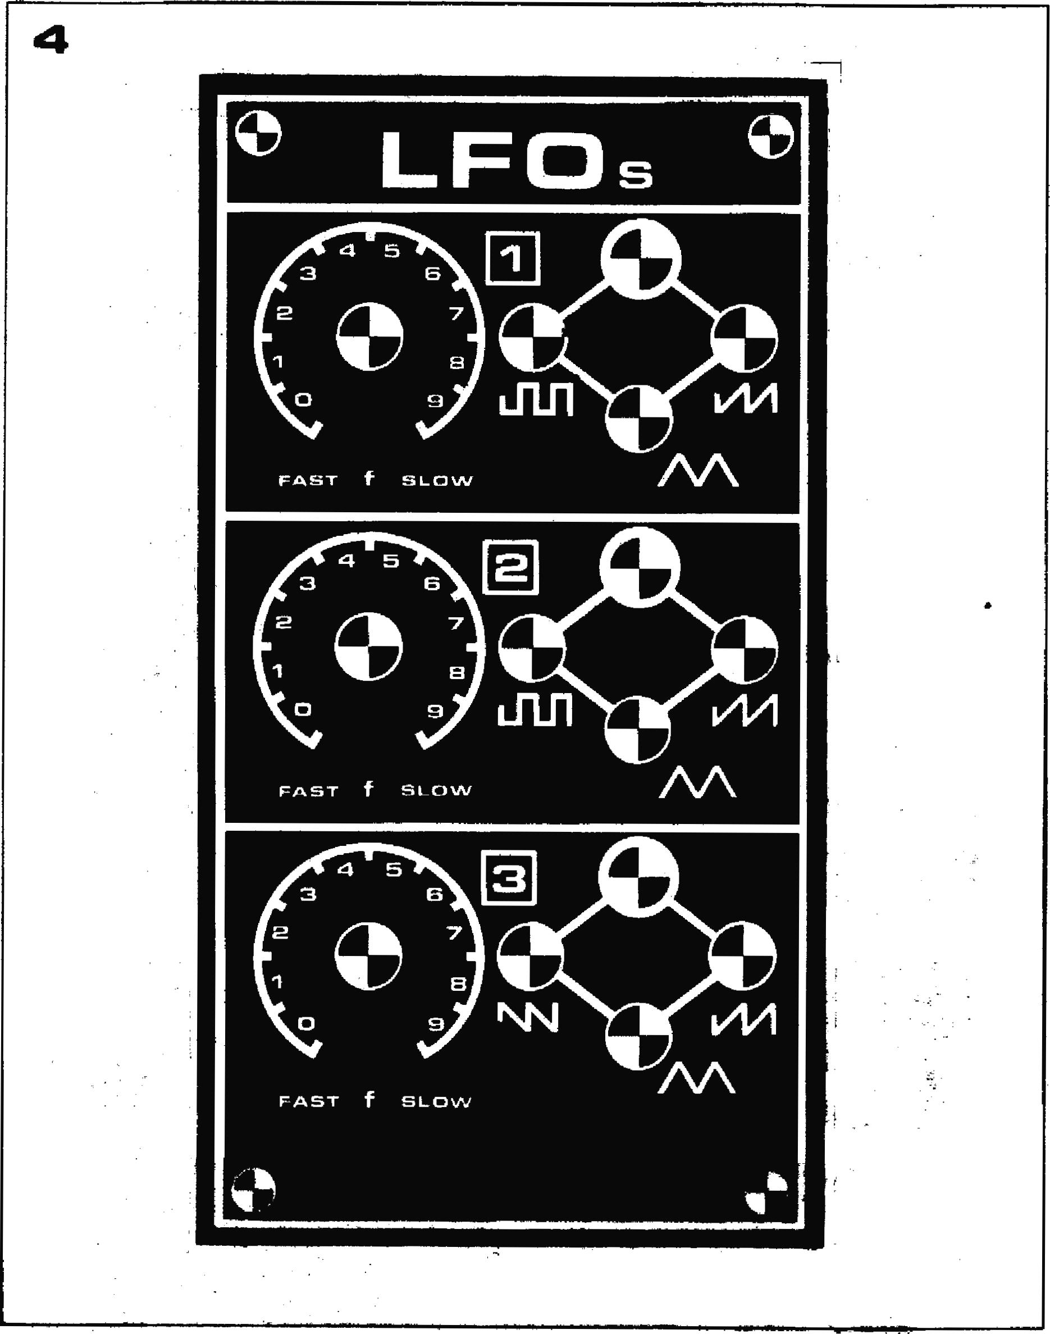
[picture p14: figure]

| Figure 4. Front panel layout of She LFO module. Figure 5. Circuit of the noise module. Figure 6. Printed circuit board and component layout for the noise module (EPS 9728.1).

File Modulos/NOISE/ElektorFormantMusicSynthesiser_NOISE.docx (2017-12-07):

080 — FORMANT

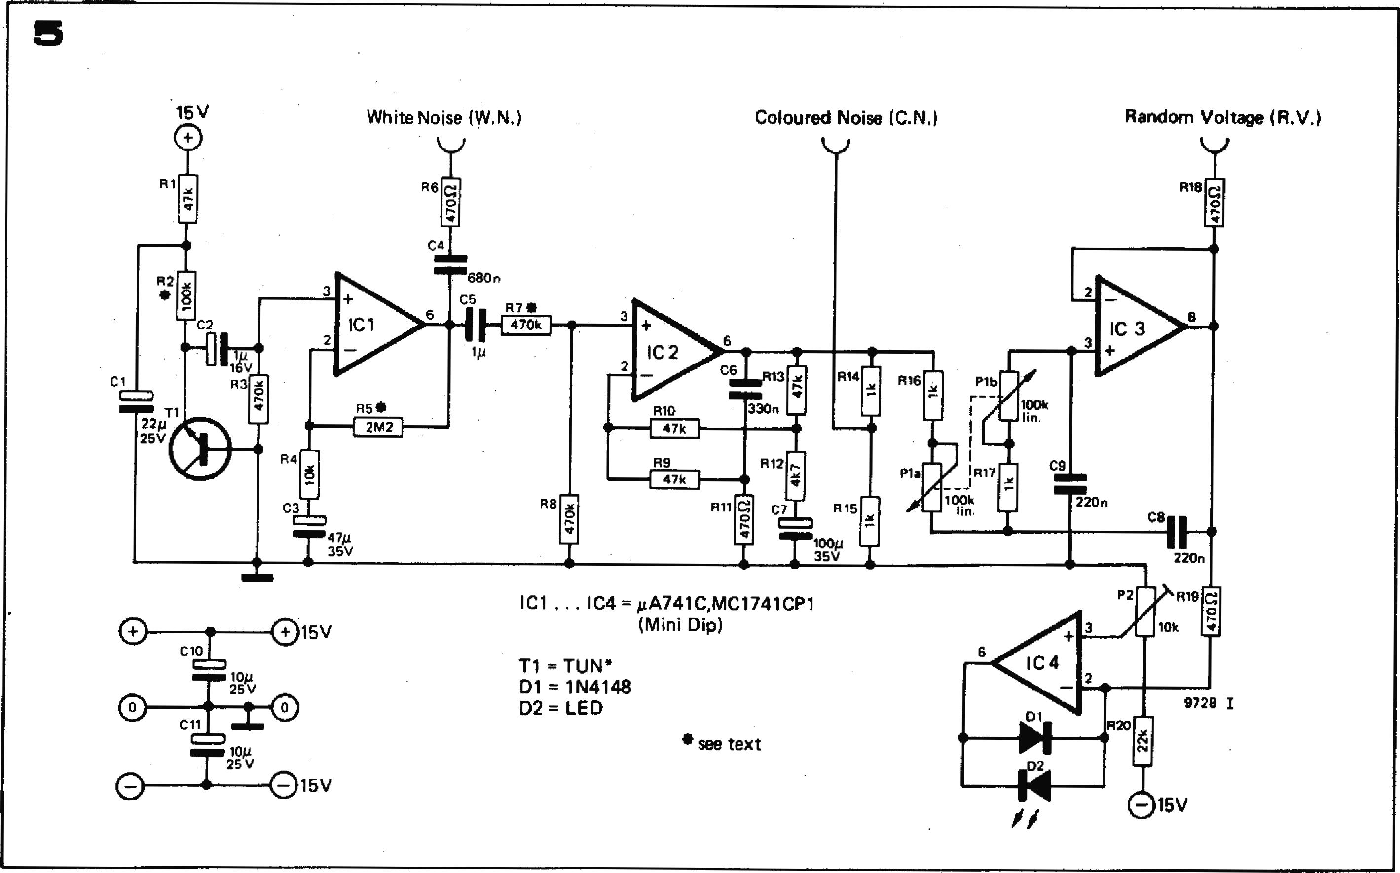
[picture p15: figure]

6

IC 2

1

R8

2

IC 3

100k

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
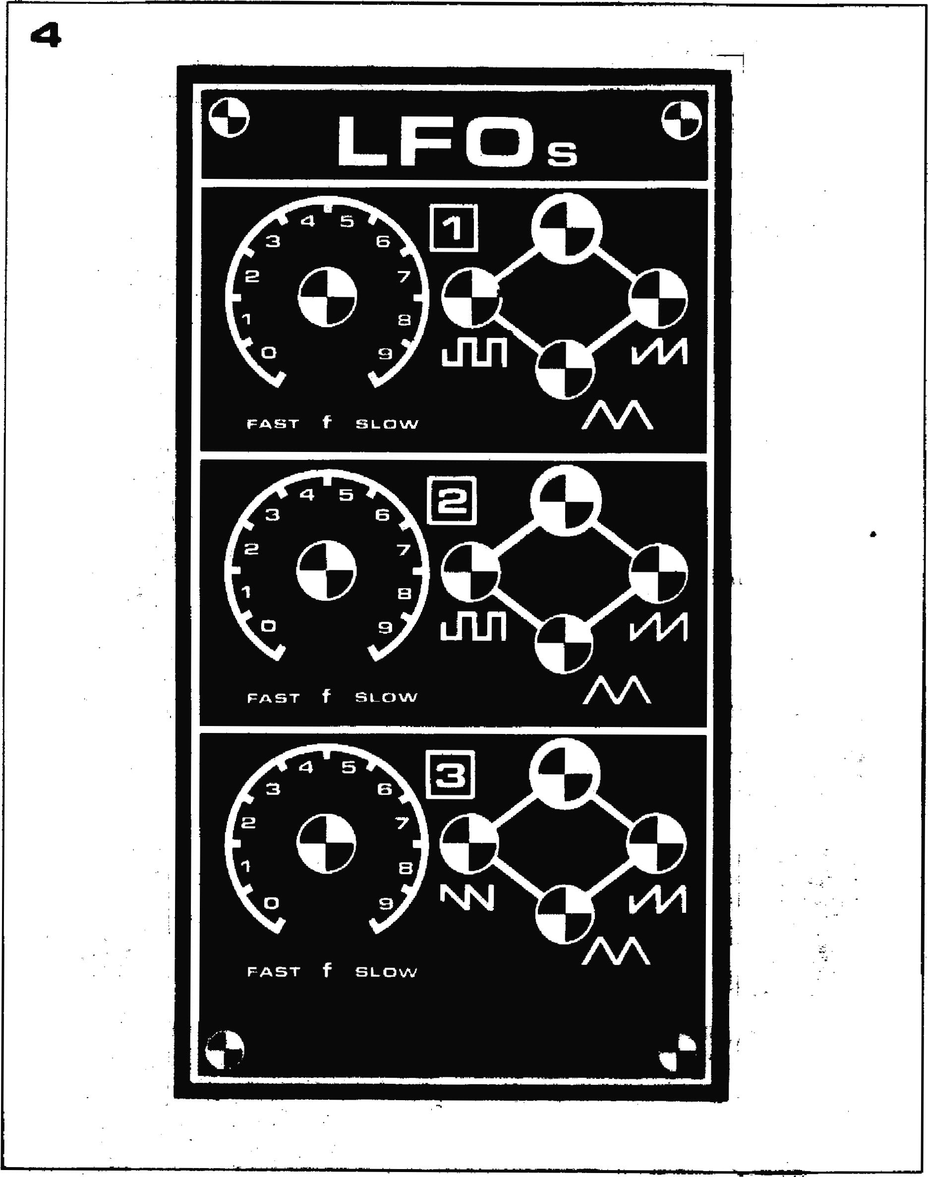
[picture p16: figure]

| Figure 4. Front panel layout of She LFO module. Figure 5. Circuit of the noise module. Figure 6. Printed circuit board and component layout for the noise module (EPS 9728.1).

FORMANT — 081

Ill.t.cl ⁰o0

00

-15k/o0

o

cj 0

o v 0

0

0o

0

00

+⁻isv

0 0o Oa

4!!!

4t1

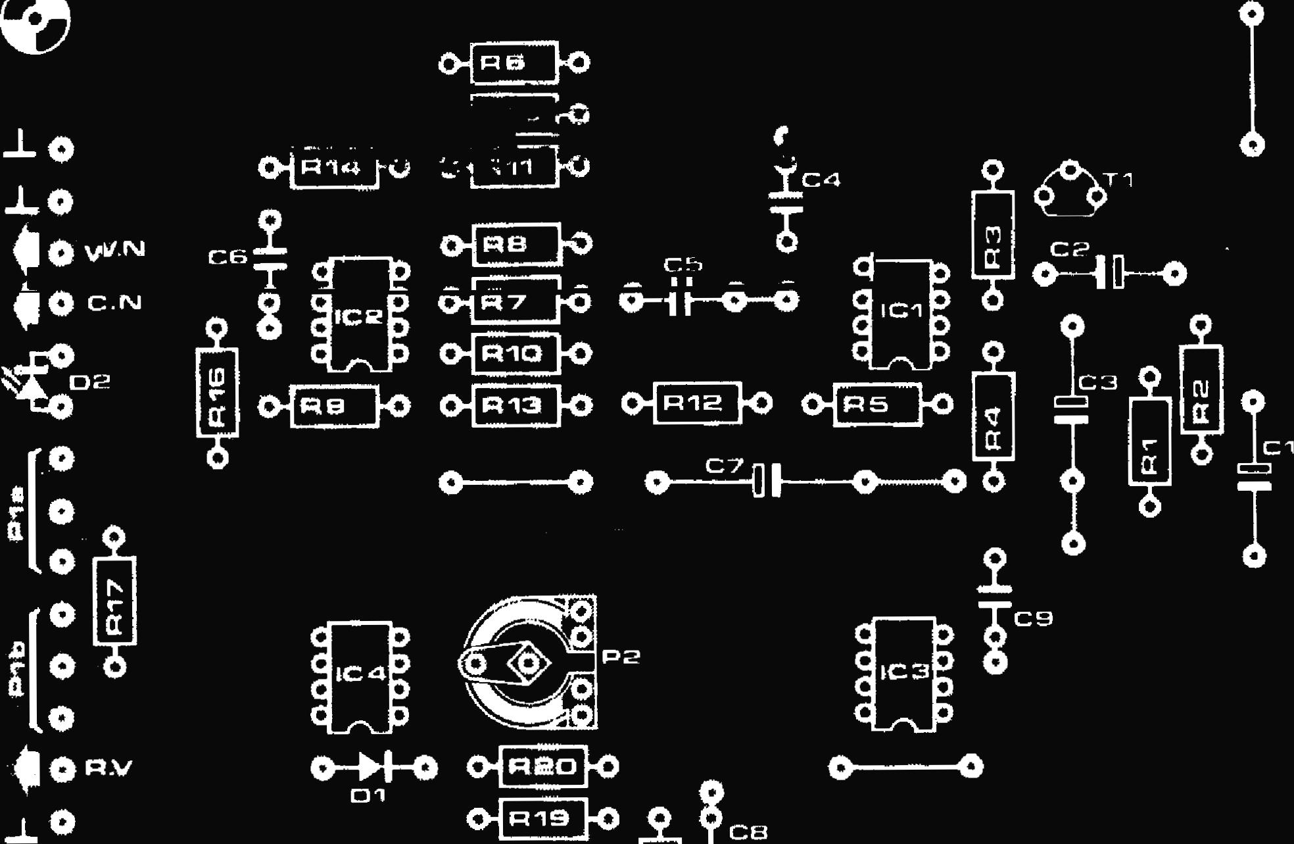
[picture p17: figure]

a

C

C

C

C

1C3

O------O

0-1pri 9 10

C

0⁻01⁻0 04R²⁰

c3-1

P2

iF a

R8

Ft' 11:1 0⁻1

Ft10 •

1.0 Of R13 I-0 0-11R12. 10 0.185 f

0⁻⁵²⁻0 I 0—*0

15 JO

- ri4

AryO i x i

I

C1

I

C D

C IC 4 D

D

Ei

r

a

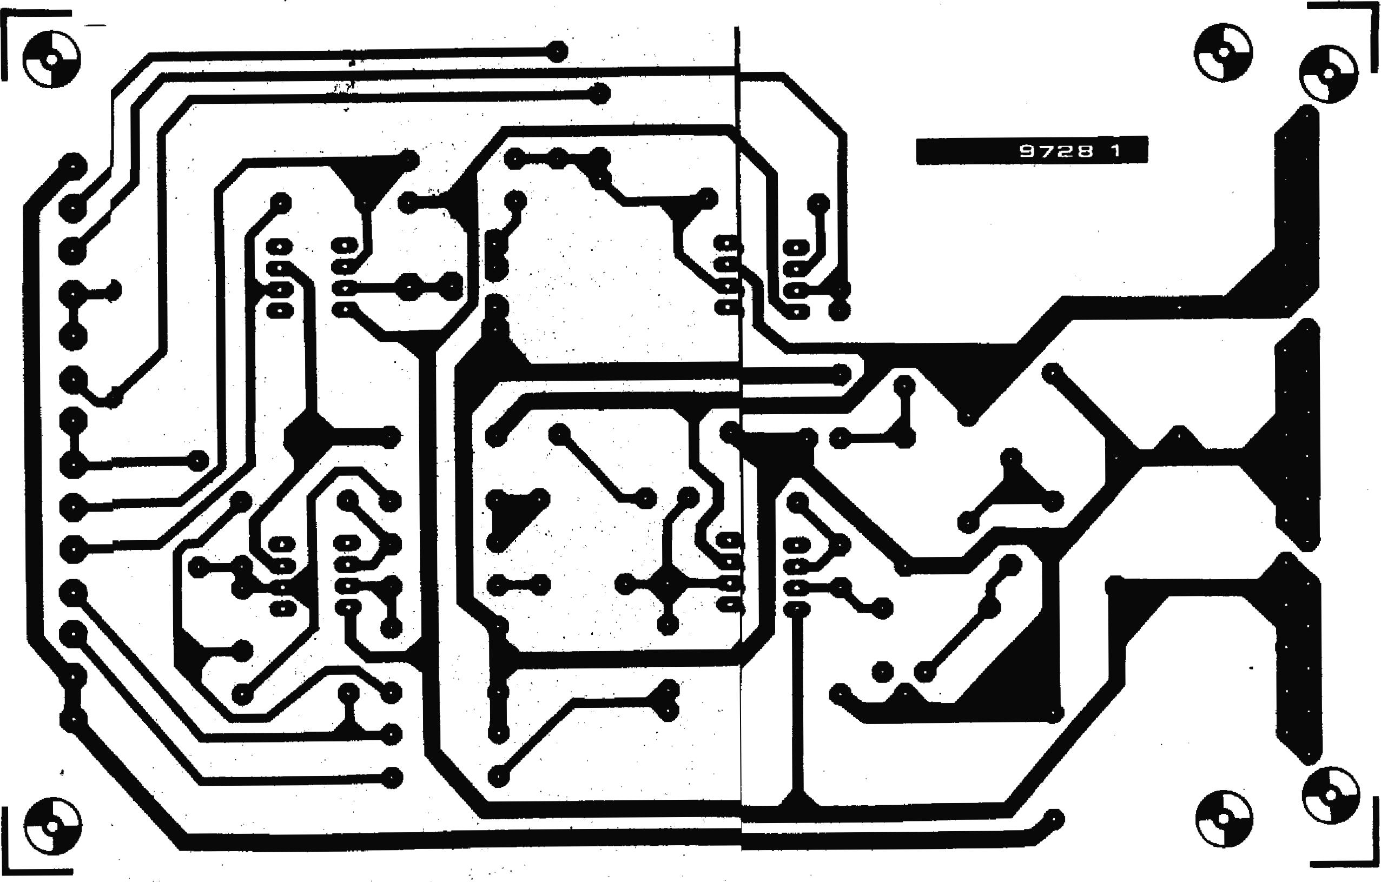
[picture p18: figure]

Parts list for noise module | Capacitors: | Semiconductors: | Potentiometers:
Resistors: | C1 = 2214/25 V C2 = 1 g/16 V | IC1,1C2,1C3,1C4, =14A 741C, MC 1741CP1 (Mini DIP) | P1 = 100 k lin. ganged potentiometer
R1,R9,R10,R13 = 47 k | C3 = 4714/35 V | T1 = TUN (selected) | P2 = 100 k preset
R2 = 100 k (see text) | C4 = 680 n | = 1N4148, 1N914
R3,R7,R8 = 470 k | C5 = 1 1.4 (polyester or | D2 = LED (e.g. TIL 209) | Miscellaneous:
R4 = 10 k | polycarbonate) | | 1 x transistor socket
R5 = 2M2 (see text) | C6 = 330 n | | 1 x 31-way connector (DIN
R6,R11,R18,R19 =470 sz | C7 = 10014/35 V | | 41617)
1312 4k7 | C8,C9 = 220 n | | 3 x 3.5 mm jack sockets
R14,R15,R16,R17 = 1 k | C10,C11 = 1014/25 V | | 1 x 13 ... 15 mm knob
R20 = 22 k

082 — FQRMANT

Adjustment of the LED indicator

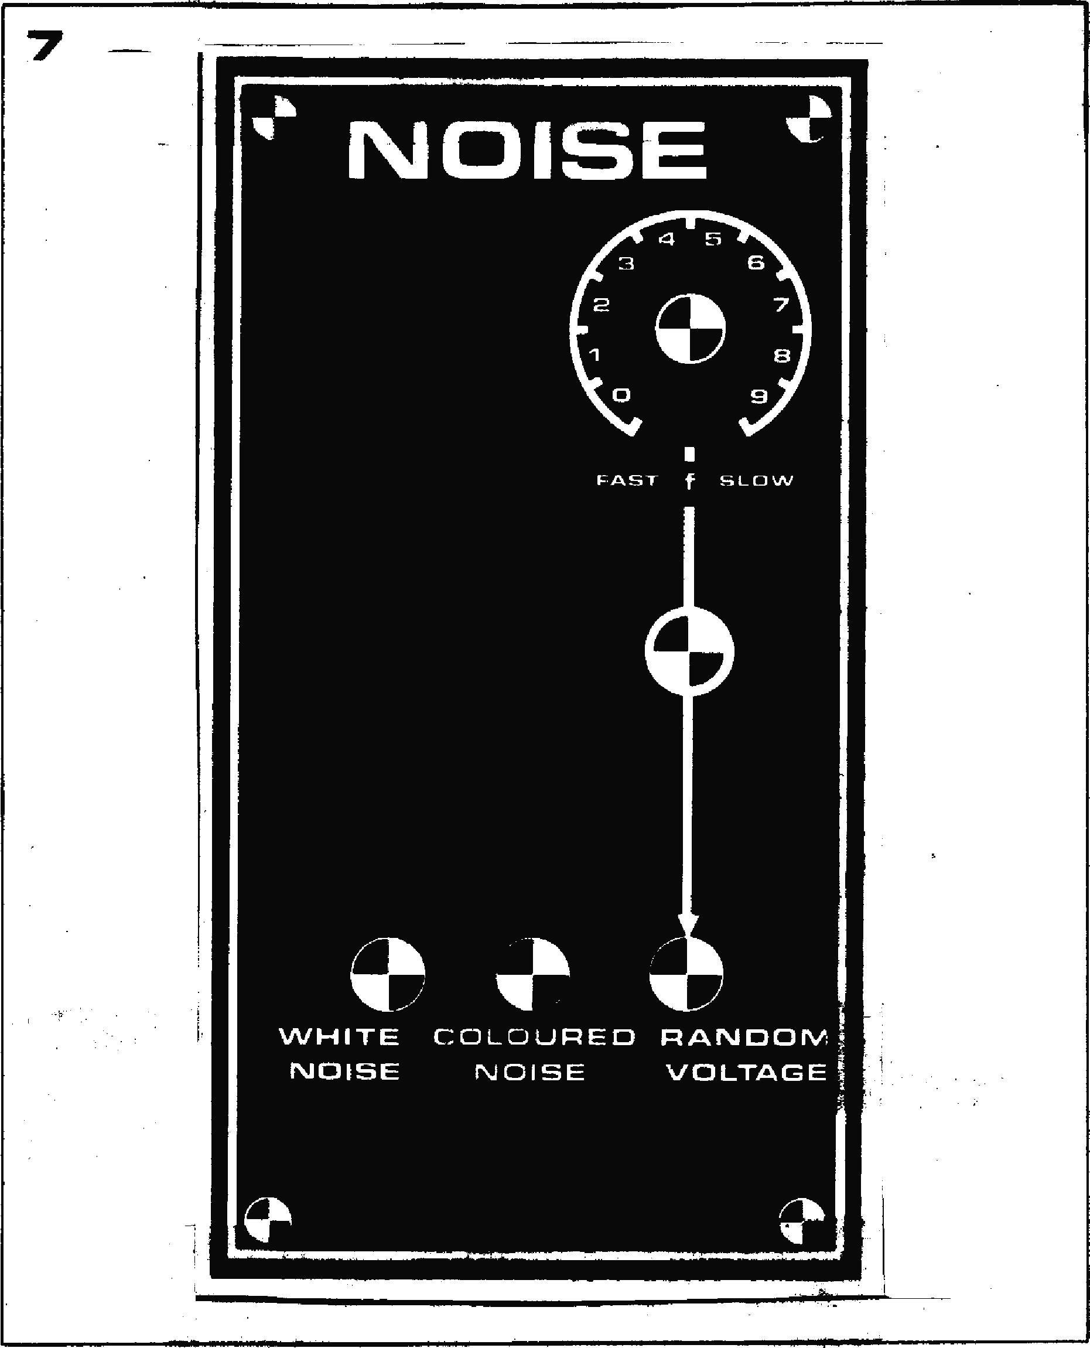
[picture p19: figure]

WHITE COLOURED RANDOM NOISE NOISE VOLTAGE

Figure 7. Front IMAM "Went of Ike min module.

P4 should be adjusted so that the brightness of the LED follows the amplitude of the triangle output, i.e. the LED should be at minimum brightness when the triangle voltage is at its most negative, and at maximum brightness when the triangle is at its most positive. P4 should adjusted so that the LED . brightness does not reach maximum before the peak of the triangle, but on the other hand it should not extinguish completely before the trough of the triangle.

The noise module

The complete circuit of the noise module is shown in figure 5. The noise is produced by the base-emitter junction of an NPN transistor T I, which is reverse-biased. The noise is amplified to a level of about 2.5 V peak-to-peak. This white noise output is fed out via C4 and R6.

The white noise is also fed into a filter constructed around 1C2, which has two frequency dependent elements in the feedback path. These two elements interact as follows. On its own, the feedback network comprising R10, R12, R13 and C7 would produce a 6 dB/octave rise in the gain of 1C2, from 0 dB at zero Hz via 3 dB at 9 Hz to approximately 20 dB at 90 Hz. The feedback network R9, R11, C6, on its own would produce a 6 dB/octave fall in gain from 0 Hz to 1 kHz, above which the gain would remain constant at 0 dB.

The combined effect of these feedback networks is that below 90 Hz the 6 dB/octave rise and 6 dB/octave fall cancel out, giving a gain of 20 dB. Above 90 Hz the gain falls at 6 dB/octave to 0 dB at 1 kHz, above which it remains constant. The reset is that the bass end of the noise spectrum is boosted, and 'coloured' noise is available at the output of IC2. The coloured noise output is taken from the junction of R14 and R15.

The coloured noise output is also fed to a second filter built around IC3. This is a 12 dB/octave lowpass filter with variable turnover frequency, which passes only the very low frequency components to produce an extremely low frequency 'random voltage'. The fluctuation rate of this random voltage is adjusted by means of P1, which varies the turnover frequency of the filter. Fluctuations of the random voltage are displayed on a LED indicator, which is identical to those used in the LFOs.

Construction and adjustment of the noise module

A printed circuit board and component layout for the noise module are given in figure 6, and the front panel layout is given in figure 7.

As not all transistors are suitable noise
generators, a socket should be fitted in

the TI position on the board so that different transistors may be tried. Measuring with a multimeter on a suitable AC voltage range at the white -noise output,----a—voltage of 0.5 V to 0.8 V should be present. Alternatively, if an oscilloscope is used to monitor the output, a noise signal of about 2 V to 2.8 V peak-to-peak should be obtained. It may be necessary to try several transistors before a suitable one is found. Varying the value of R2 between 33 k and 150 k may also help.

If the transistor produces too high a noise level this can be reduced by making R5 smaller, thus reducing the gain of IC1.

The amplitude of the coloured noise output should also lie in the same range as the amplitude of the white noise output. If it is too small then R7 should be reduped and if it is too large R7 should be increased.

The random voltage output should vary between about +2.5 V and —2.5 V with P1 in the 'fast' position.

The final adjustment to the noise module is to set P2 so that the LED brightness indicates the amplitude of the random voltage output in a linear manner. This adjustment is carried out in exactly the same way as the adjustment of the LFO indicators.

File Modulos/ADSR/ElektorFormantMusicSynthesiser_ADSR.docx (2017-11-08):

064 — FORMANT

chapter 9

ADSR

The ADSR (Attack-Decay-SustainRelease) shaper is used to control the VCF and VCA modules and thereby determine the dynamic harmonic structure and dynamic amplitude characteristic of the VCO signals.

It is often not realised, even by musicians, how much the character of an instrument is determined by the dynamic amplitude and harmonic behaviour, rather than by the steady-state harmonic content of the instrument. If the attack and decay periods of a note are artificially modified, then the whole character of the sound is altered. An interesting and amusing experiment is to record the sounds of several musical instruments, but to remove the attack and decay periods by bringing up the recording level after the note starts and fading it down before the note ends. Then ask some musical friends to identify the instruments. They will no doubt be amazed how characterless the sound of an instrument becomes when robbed of its particular amplitude envelope.

On the other hand, starting with a single basic waveform such as the triangle output of the Formant VCO, a whole range of instrument sounds can be produced simply by varying the amplitude envelope, ranging from 'soft' sounds such as flute and some organ voices, to 'hard', percussive sounds such as piano and xylophone.

Envelope control of the harmonic content using the VCF allows even greater variation in the character of the sound.

Types of envelope curves

The envelope shaper of the synthesiser must be able to simulate the envelope contour of conventional musical instruments when the synthesiser is used in an imitative capacity, and also to produce envelopes that are purely synthetic in character (i.e. not found in sounds produced by normal acoustic methods). Fortunately, there are relatively few types of envelope contour that are musically important, and these are all fairly easy to generate electronically.

1. Attadc/decay contour

The simplest type of envelope curve is that consisting only of attack and decay periods. The envelope contour rises to a peak when the note is played, and begins to decay immediately the peak is

passed (see figure 1). By varying the attack and decay times a wide variety of sounds can be produced.

For example, if a rapid attack and slow decay is applied to the VCA control, then a percussive sound like a piano results. Applied to the VCF in the low-pass mode, the same envelope contour can produce very bright, metallic sounds, depending on the input waveform.

If the attack period is made long and the decay period short, then applying this to the VCA will produce completely synthetic 'fantasy' sounds similar to those obtained by playing a recording backwards. Applying this type of envelope contour to the VCF can produce sounds similar to those of a brass instrument played staccato.

However, the main use of this type of envelope curve is for the production of percussive sounds such as xylophone, marimba, glockenspiel, bells and gongs, cymbals, and struck or plucked strings such as guitar, banjo, harp, other string instruments played pizzicato, harpsichord, and of course, piano.

2. Attack-sustain-release contour

The attack/decay characteristic previously described is typical of instruments where the sound is initiated by a short pulse of energy (e.g. by striking or plucking a string), after which the sound dies away since there is no further excitation to sustain it. The envelope contour shown in figure 2 is typical of instruments in which a note is sounded and sustained, such as a pipe organ, woodwind instruments, and bowed string instruments. In a pipe organ the note builds up fairly rapidly after a key is depressed as standing wave modes are established in the pipe, and the note is sustained by virtue of the fact that air is continuously blown into the pipe. When the supply of air stops on releasing the key the note terminates more or less rapidly.

The same basic contour applies to woodwind instruments and to string instruments played with a bow, since the note is here again sustained by blowing or bowing. However, with such instruments much greater expression can be obtained by modulation of the

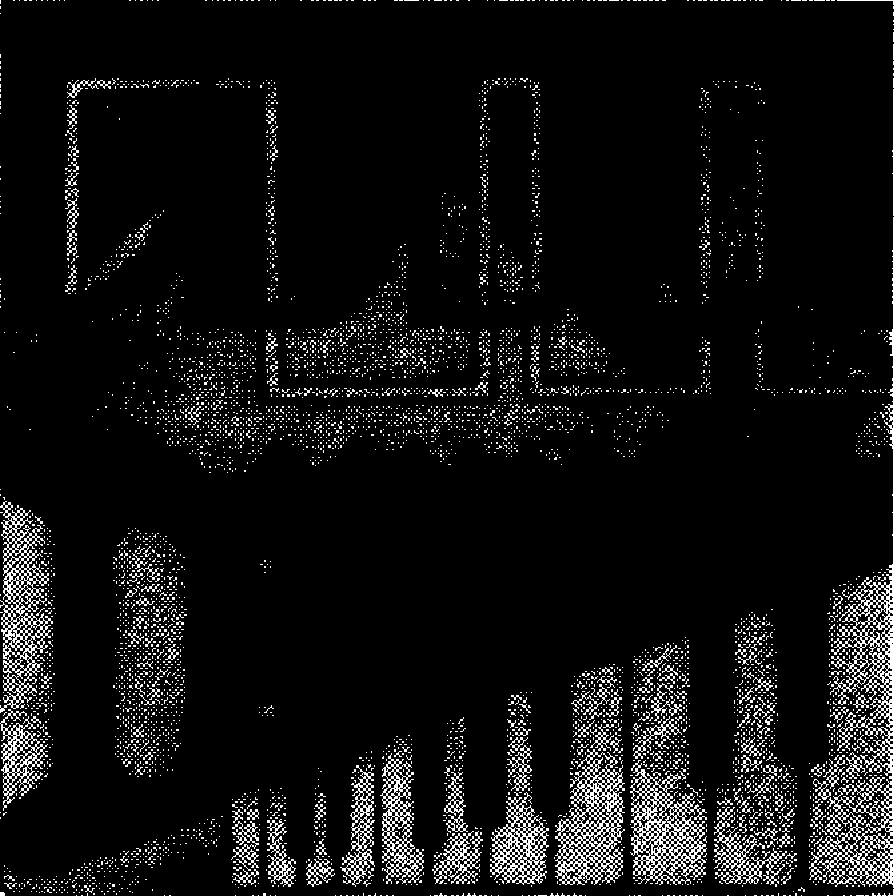
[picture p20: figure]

FORMANT — 065

steady-state level, since this is determined by the player, and not by a mechanical blower as is the case with a pipe organ.

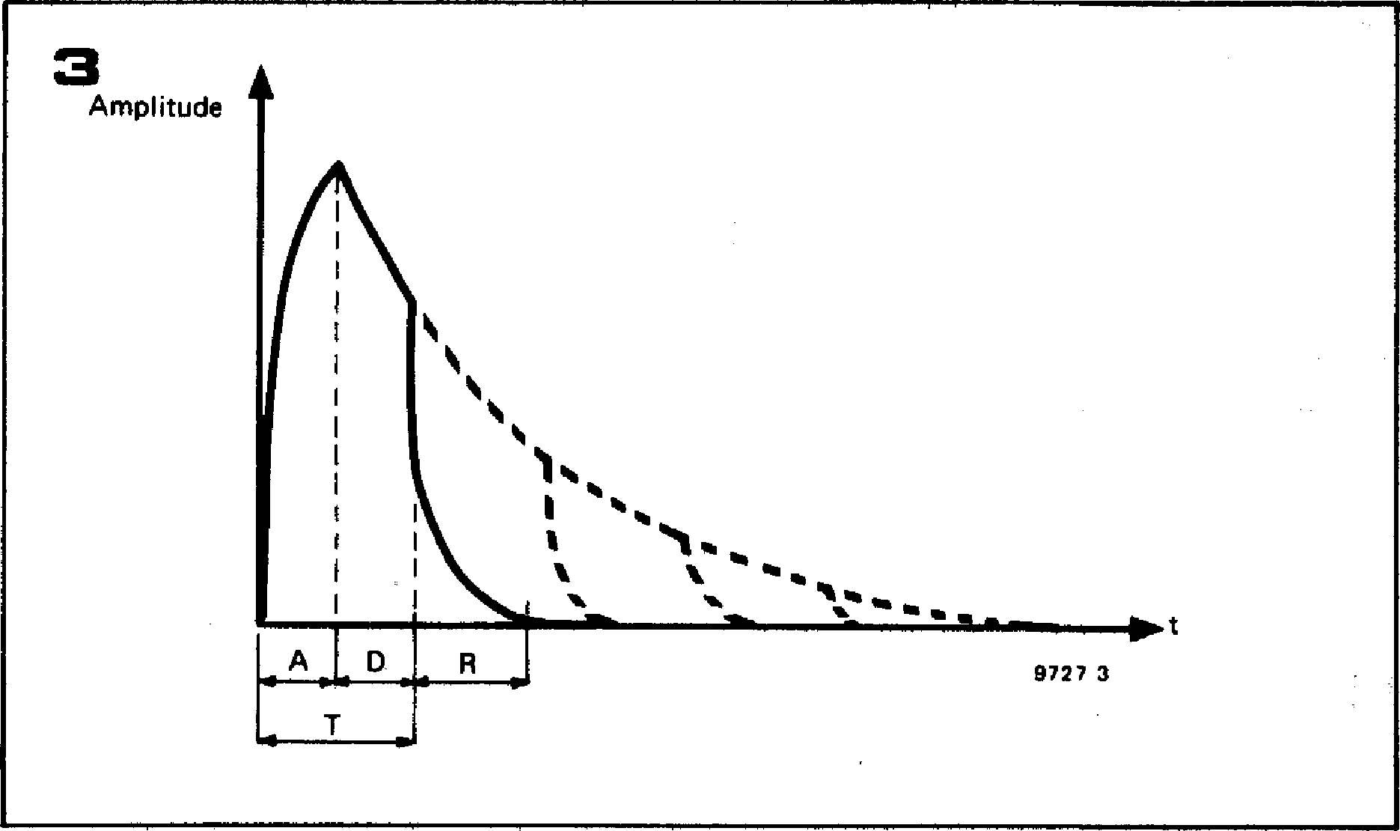
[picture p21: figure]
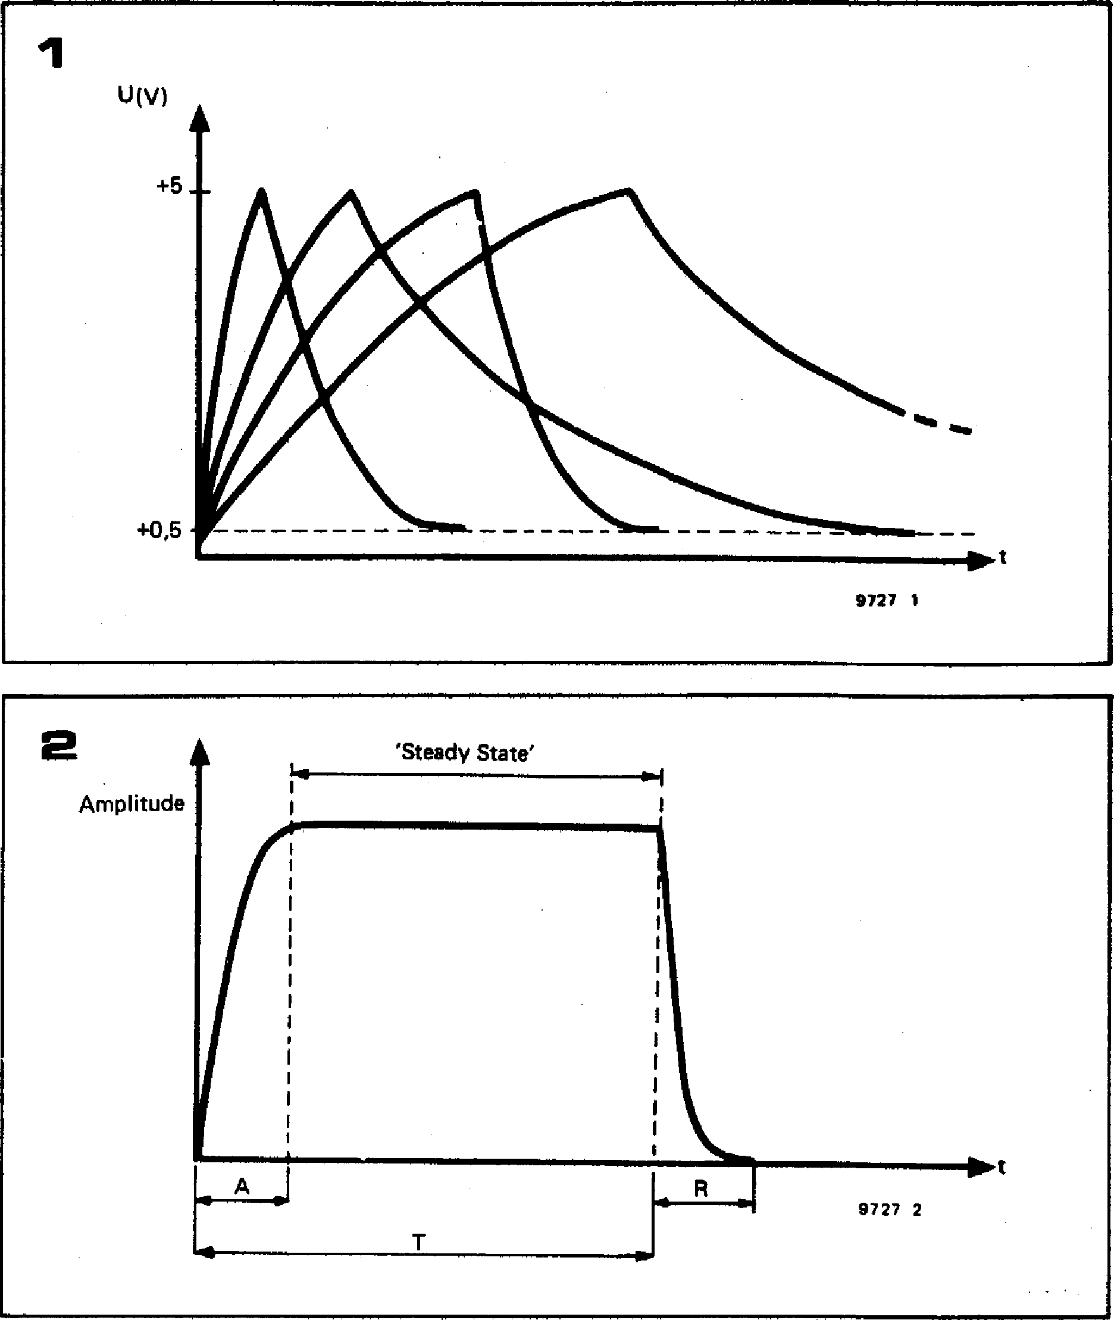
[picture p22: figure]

With a synthesiser, a degree of expression can be obtained by modulating the VCA using the low-frequency oscillators or noise source.

3. Attack-decay-release contour

A variation on the attack-decay contour
is shown in figure 3. Here the slow

Figure 1. The attack-decay envelope contour is the simplest contour found in music.

Figure 2. The attack-sustain-release contour is used to simulate instruments where the note can be sustained at a constant level, such as organ, woodwind, and bowed string instruments.

Figure 3. Instruments such as the piano can be simulated using the attack-decay-release contour. As long as the key remains depressed the decay path is followed, but once the key is released the note is ended more abruptly, following the release contour.

decay is allowed to continue for only a certain time, and the note is then terminated by a more rapid release. The most common example of this type of contour is provided by our old friend, the piano. When a note is sounded and the key remains depressed, then the damper is held off the string and the note decays over a period of a few seconds. If, however, the key is released after playing a note, the felt damper contacts the string and the note terminates after about 500 ms.

4. Attack-decay-sustain-release contour

Most of the examples given so far relate to envelope control of the VCA, since the amplitude contour of a sound is somewhat easier to visualise than its dynamic tone colour behaviour. However, the most complex envelope contour, shown in figure 4, is a good illustration of envelope control of the VCF.

Many brass instruments, such as the trumpet, are characterised by a rapid build-up of harmonics during the attack period of the note, which gives the instrument a very strident sound. Once the note is established, however, the harmonics die away somewhat, and the tone is much more mellow during the steady state period. Finally, during the release period at the end of the note, the note dies away fairly rapidly.

This type of characteristic can be obtained by using the VCF in the low-pass mode and controlling it with an envelope contour similar to that shown in figure 4. As the control voltage rises during the attack period, so the turnover frequency of the VCF increases, passing more harmonics. During the decay period the VCF turnover frequency falls until the steady-state value is reached, and finally, during the release period the VCF turnover frequency drops very rapidly.

Envelope shaper requirements

It is apparent from figure 5 that the envelope contours shown in figures I to 3 are merely special cases of the more general attack-decay-sustain-release contour illustrated in figure 4. Any of the four contours can be generated by an envelope shaper having the following four functions:

- variable attack time (A)
- variable decay time (D)
- variable sustain level (S)
- variable release time (R)

These four parameters can be preset manually using the ADSR controls of the envelope shaper. The envelope shaper is controlled by the gate pulse output of the keyboard. When a key is depressed the gate output goes high and this initiates the attack-decay sequence. The output of the envelope shaper then remains at the sustain level until the key is released, when the release period begins.

066 — FORMANT

Block diagram

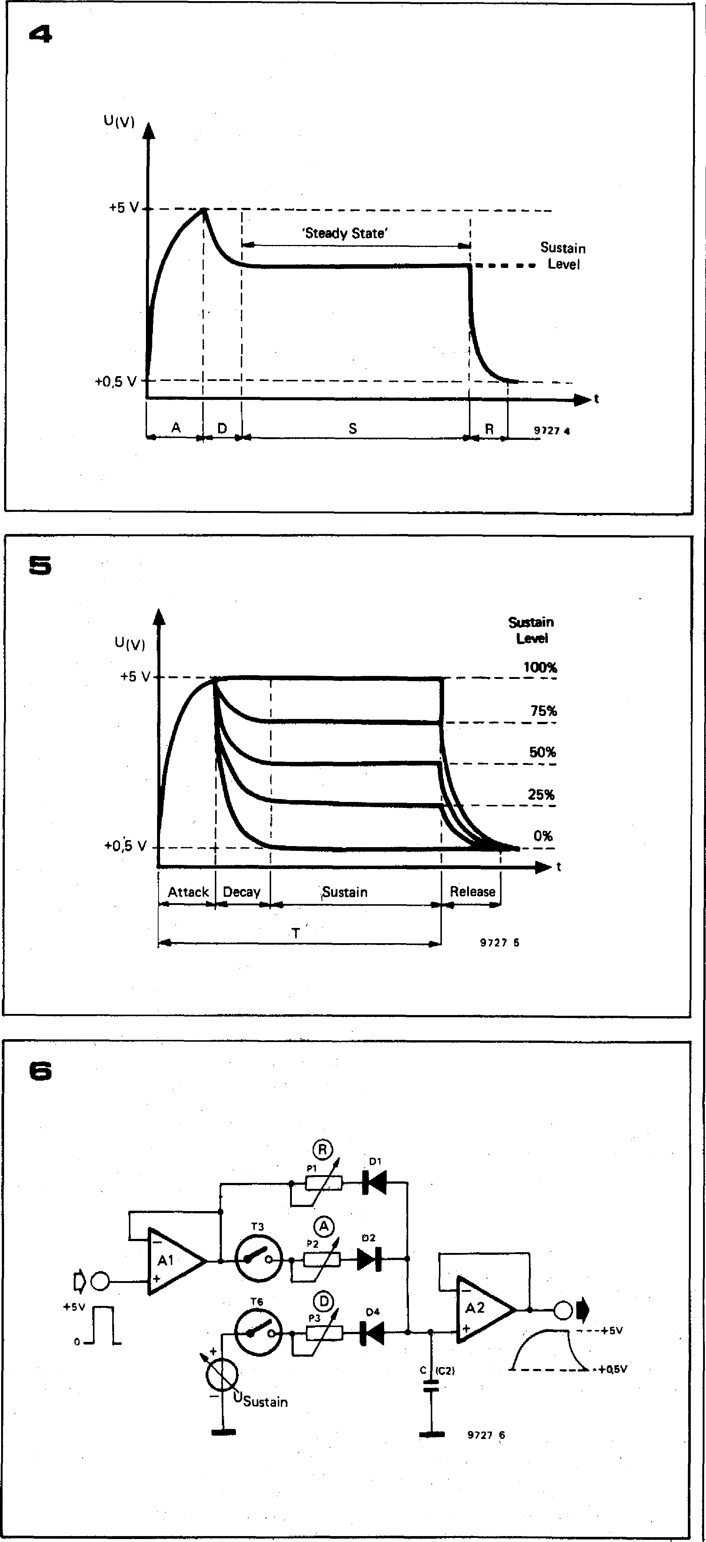
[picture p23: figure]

The required exponential attack, decay and release characteristics are easily obtained by charging and discharging a capacitor through resistors, and the sustain level by clamping the capacitor voltage to a preset D.C. level during the sustain period. The basic principle of the envelope shaper is illustrated in figure 6. The gate pulse is fed to a voltage follower Al , and when the gate pulse is high C charges exponentially through P2 and D2 (and T3).

At the end of the Attack period, `switch' T3 is opened and T6 is closed. Capacitor C now discharges through D4 and P3 (Decay), until the Sustain level is reached. This level is maintained until the gate pulse finishes, either when the key is released or when a preset time has elapsed.

When the gate pulse finishes, the output of Al goes to zero volts, and C discharges through DI and P1 (Release). The capacitor cannot discharge fully,

ADSR adjustment ranges:

Attack period (Al 10 ms...20s

Decay period (D) 10ms...20s

Sustain level IS ) 0.5 V . .. 5V

Release period (R) 10ms...20s

since DI ceases to conduct once the voltage on C has fallen to about 0.5 V, but this is not important as it merely constitutes a D.C. offset which can be compensated for. The attack, decay and release times may be adjusted by means of P2, P3 and Pl.

Complete circuit

The complete circuit, which is shown in figure 7, is, of course, more complicated. The envelope shaper has two modes of operation, ADSR and AD, which are selected by means of Si,With S 1 in position 'b' (ADSR) the circuit operates as follows:

When a key is depressed the gate pulse output goes to +5 V. ICI has a gain slightly greater than unity, so about +6 V appears at its output.

The leading edge of the gate pulse also
triggers moaostable TI /T2, which pro-

FORMANT — 067

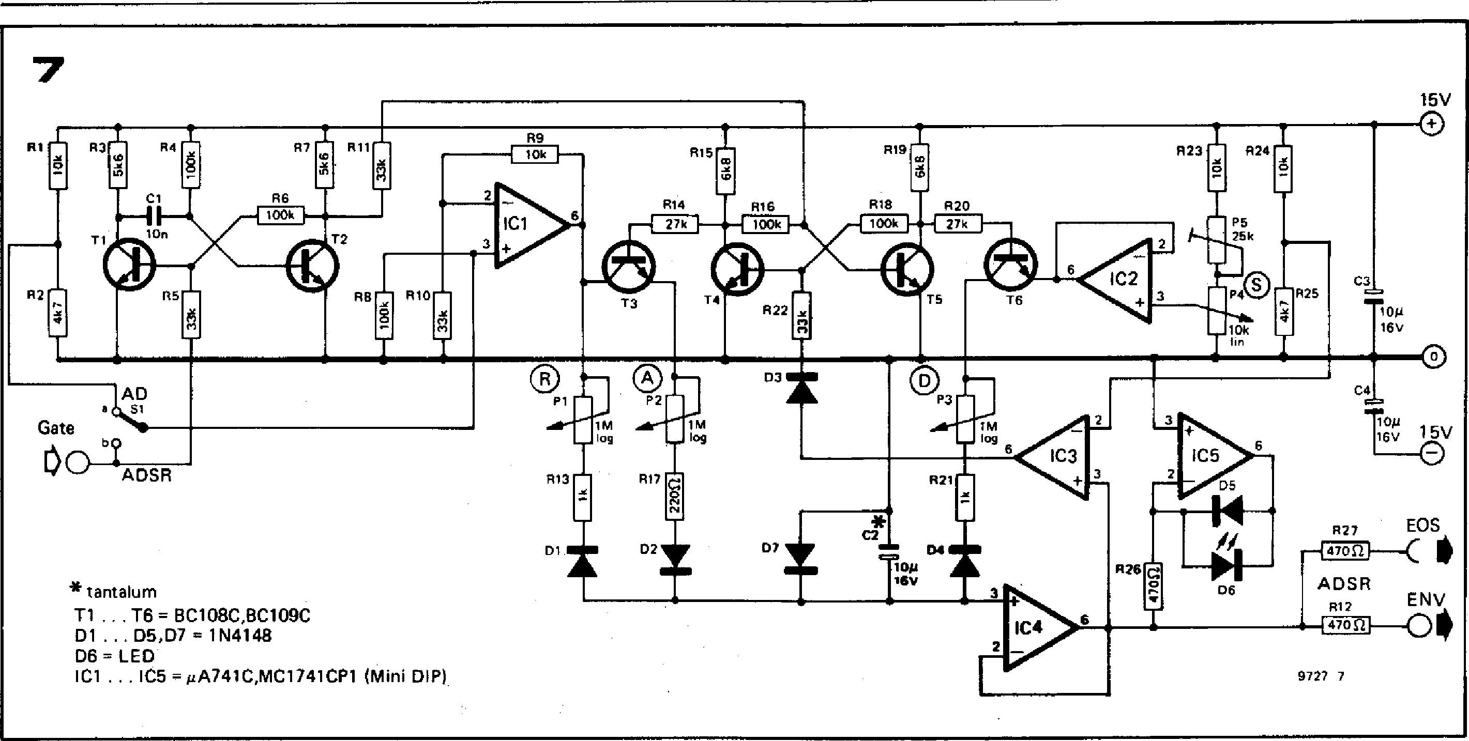
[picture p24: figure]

duces a short pulse to set flip-flop T4/ 15 (T5 turned on and T4 turned off). The collector voltage of T4 thus rises, turning on T3 and allowing C2 to charge from the output of IC I through T3, P2, R17 and D2. This is the attack period.

The voltage on C2 is fed to voltage-follower buffer IC4, which is connected to the outputs EOS and ENV and also to the non-inverting input of IC3. This IC functions as a comparator, with its inverting input held at about 4.7 V by R24 and R25. When the voltage on C2, and hence at the output of IC4, exceeds this value, the output of IC3 swings positive, resetting flip-flop T4/T5, turning off T3 and terminating the attack period. T6 is turned on, initiating the decay period when C2 discharges through D4, R21, P3 and T6 into the output of IC2 until the sustain level, set at the output of voltage follower IC2 by P4, is reached.

The output of the envelope shaper then remains at the sustain level until the key is released, when the output of ICI goes to zero volts and C2 discharges through DI , R13 and PI (release period).

Diode D7 protects C2 in the event of the output of ICI going negative for any reason, when the voltage across C2 is clamped to a maximum of —0.7 V.

A LED indicator constructed around IC5 allows visual monitoring of the envelope contour. The brightness of the LED follows the envelope voltage.

Two outputs are provided from the envelope shaper; an external output to a front panel socket (EOS), and an internally wired output (ENV).

The full ADSR envelope contour is, of course, produced only if the key is depressed for a period longer than the attack plus decay time, and if the sustain level is greater than 0%. If the key is released before the sustain level is reached then the release period is initiated prematurely, and either AR or ADR curves may be produced. If the

Figure 4. The attack-decay-sustain-relesse contour is the most complex envelope ships provided by the Formant envelope shaper. When applied to the VCF it is useful for imitating brass instruments, where the harmonic content of the note rises initially to a large value, then reduces to a tower level during the steady-state part of the note.

Figure 5. By varying the sustain level the envelope contour can be changed from an AD contour at 0% sustain, through various ADSR contours to an ASR contour at 100% sustain. T is the time for which the key remains depressed.

Figure 6. This simplified diagram illustrates the basic principle of the envelope shaper. C charges through D2 and P2 during the attack period. It then discharges through. D4 and P3 to the (adjustable) sustain level; finally, it discharges through D1 and P1 during the release period. P1, P2 and P3 can be used to vary the release, attack and decay times.

Figure 7. Complete circuit of the Formant envelope shaper.

sustain level is 0% then only AD or ADR curves may be produced, depending on when the key is released. If the sustain level is 100% then, of course, only AR or ASR curves may be produced, depending on when the key is released, since the decay period is inhibited.

Triggered AD mode

It is sometimes useful to be able to produce AD envelope contours that are unaffected be releasing the key, that is to say, once the key is depressed, a fixed attack-decay sequence is initiated, which is completed whether the key is released or not. This triggered AD contour is obtained by setting Si to position 'a' and selecting 0% sustain level. The input of IC1 is now connected to the junction of RI and R2, so its output is permanently at about +6 V, irrespective of the gate input.

When a key is depressed, the gate signal triggers the monostable, setting the flip-flop and turning on. T3. At the end of the attack period, comparator IC3 resets the flip-flop, turning on T6 and initiating the decay period. C2 will now discharge through D4, R21, P3 and T6 to the 0% level (sustain is set at 0%). Even if the key is released before this sequence is complete, the release period is inhibited since the output of IC1 is permanently at +6 V, so C2 cannot discharge through D1, R13 and Pl.

Construction

There are no special requirements with regard to resistor tolerances in the envelope shaper circuit, and ordinary, good-quality 5% carbon film components are quite adequate; C2 should be a tantalum electrolytic capacitor for low leakage, and C 1 the usual

068 - FORMANT

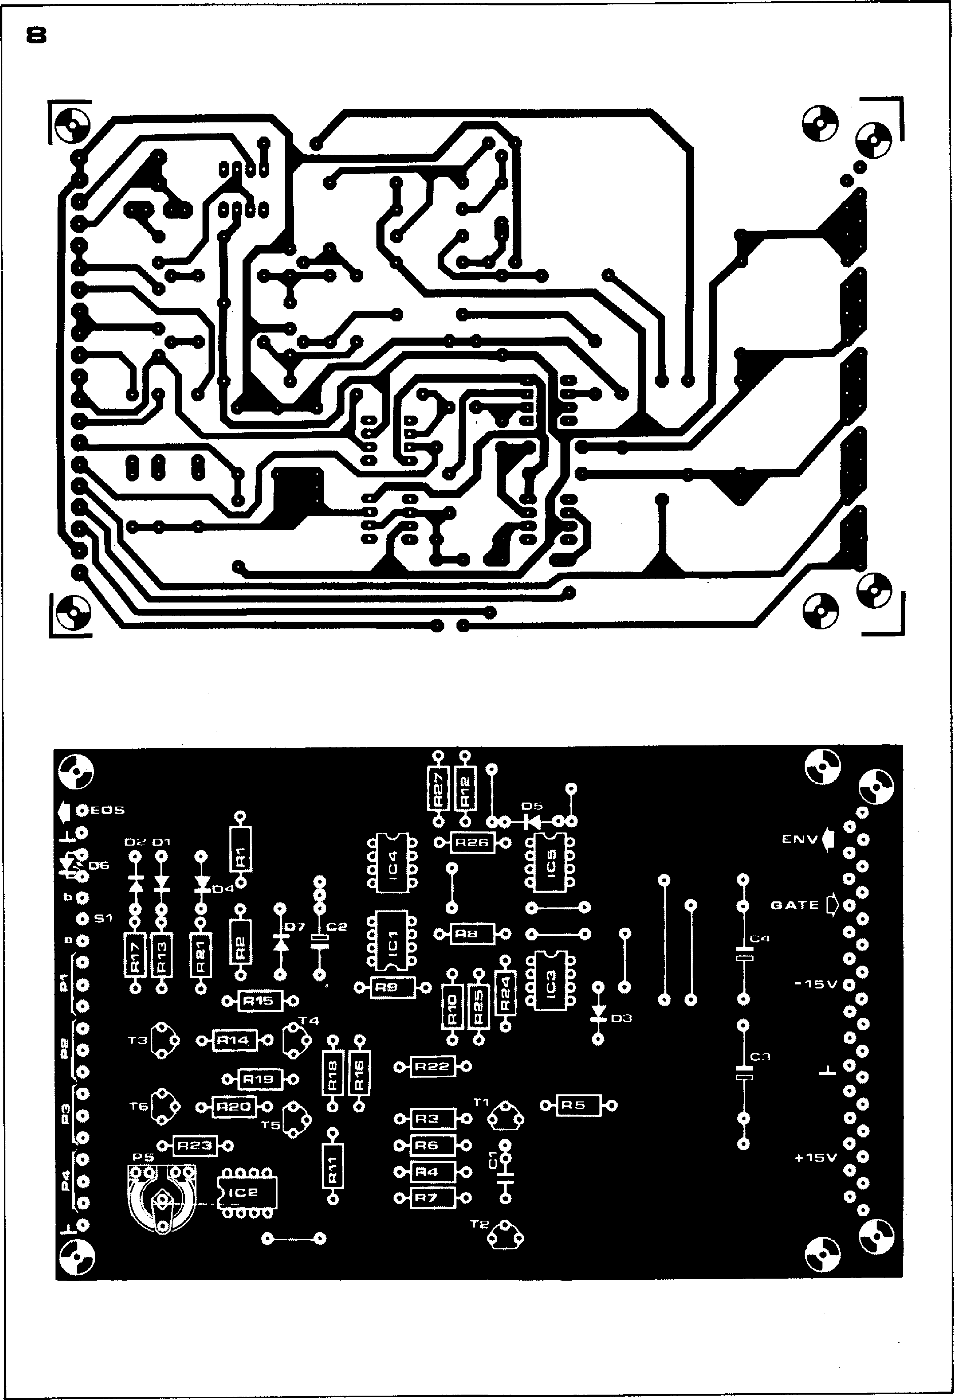
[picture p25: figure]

FORMANT — 069

E N V
INDICATOR

OUT

Parts list for figures 7 and 8

Resistors:

R1,R9,R23 = 10 k

R2,R25 = 4k7 R3,R7 = 5k6

R4,R6,R8,R16,R18 = 10.0 k R5,R10,R11,1122 = 33 k R12,R26,R27 = 470 1 R13,R21 = 1 k

R14,R20 = 27 k R15,R19 = 6k8 R17 = 220 11

Potentiometers:

P1,P2,P3 = 1 M log.

P4 = 10 k lin.

P5 = 25 k preset

Semiconductors:

T1 .. T6 = BC 108C, BC 109C or
equivalent

D1 D5,D7 = 1N4148, 1 N914

D6 = LED (TI L 209 or similar) IC1 . IC5 = AA 741C, MC 1741

CP1 (MINI DIP)

Capacitors:

Cl = 10 n

C2 = 10 i/16 V tantalum C3,C4 = 10 A/16 V

Miscellaneous:

31-way Euro connector

( D IN 41617)

1 x 3.5 mm jack socket

4 x 13 15 mm collet knobs

with pointer

polyester or polycarbonate type. It is a good idea to test T3 and T6 for leakage, using the method detailed in chapter 5. A printed circuit board and component layout for the envelope shaper are given in figure 8, and a front panel layout is shown in figure 9. Connections to the front panel are fairly simple, the only front panel-mounted components being the four potentiometers for attack time, decay time, release time and sustain level, switch S 1, the external output socket and the envelope indicator LED.

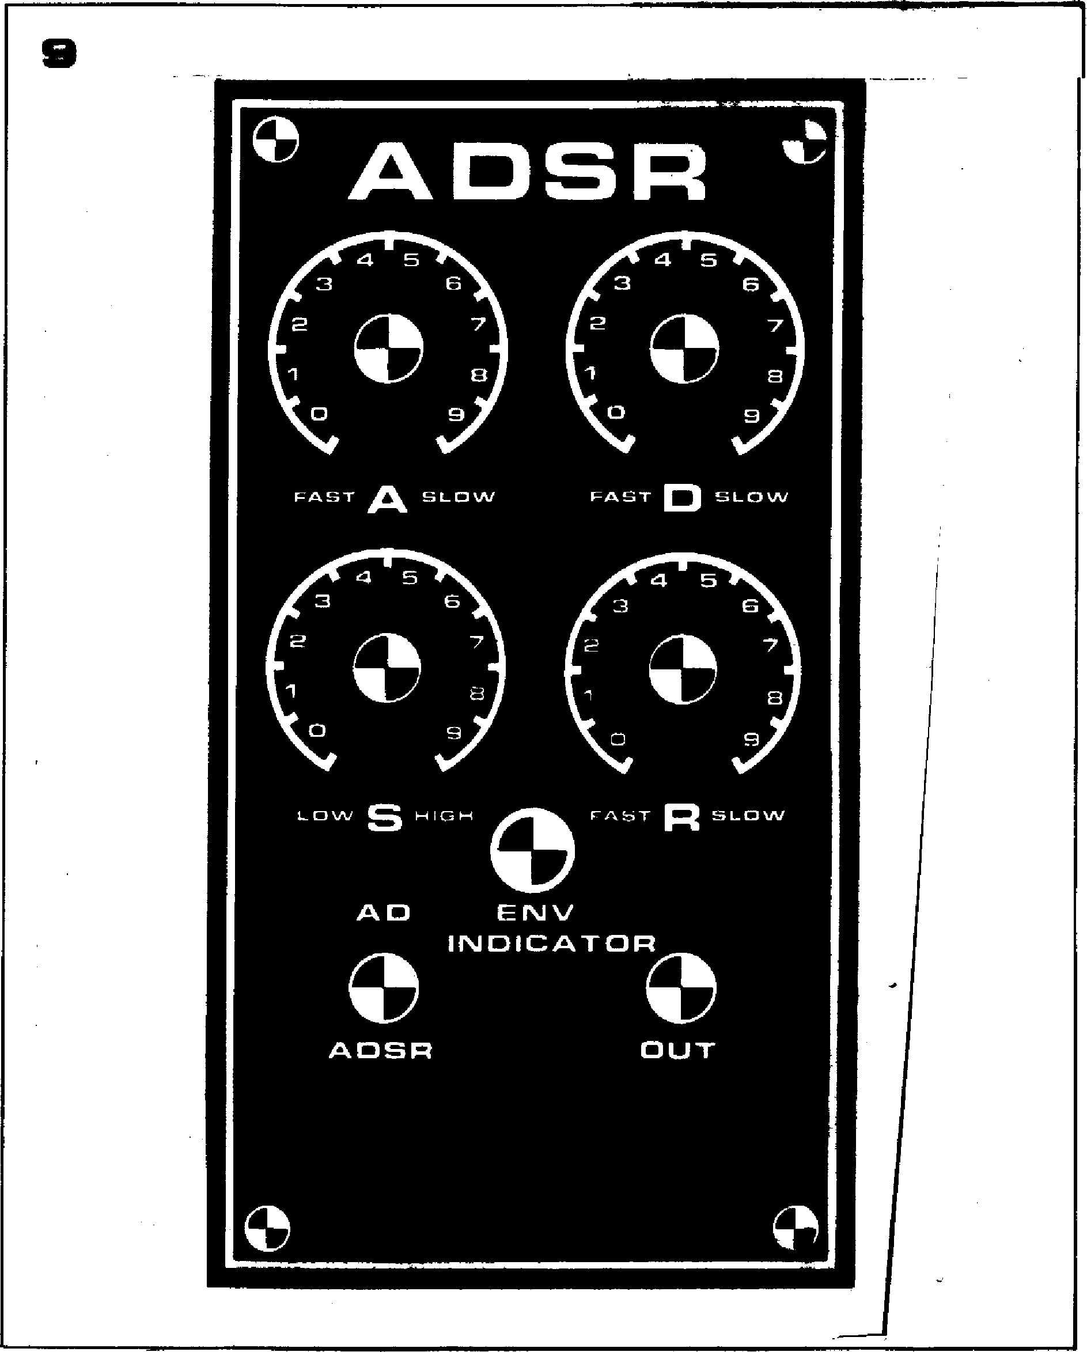
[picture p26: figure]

Figure 8. Printed cheek bawd and otOMponent layout for the eneekspe shaper (EPS 9725-1).

Figure 9. Front panel layout for the envelope shaper module.

Testing and adjustment

To test the envelope shaper a gate pulse must be available from the 'GATE' output of the interface receiver board. The EOS output of the envelope shaper is monitored on an oscilloscope with the Y sensitivity set to about 1 V/div and the timebase set to about 10 ms/div. For the first test, the sustain level is set to zero, SI is set to the `AD' position and the attack and decay potentiometers are set to `fast'. The release potentiometer has no effect during this test. If a key is depressed at short intervals then a short AD envelope curve will be seen, which rises and falls between about 0.5 V and 5 V. The out-

put of IC3 can also be monitored, to check that it swings briefly between —15 V and +15 V when the peak of the attack curve is reached.

The only adjustment required to the envelope shaper is to set the 100% sustain level, using P5, to correspond with the voltage on C2 at the end of the attack period. If it is too low, then there will always be a decay, even at 100% sustain level; if it is too high then the calibration of P4 will be inaccurate, since 100% sustain will be reached before maximum rotation of the potentiometer.

To make the adjustment, the sustain level is set to 100% and medium attack and decay times are selected. Preset P5 is then adjusted until there is just no decay after the attack period (i.e. the attack period blends into the sustain level with no dip). The adjustment can be checked by turning P4 slightly to the left, when a slight dip after the peak of the attack period should be noted. As P4 is turned further anticlockwise then the decay down to the sustain level will become greater and greater, until finally, at 0% sustain level, pure AD curves will be produced. The envelope shaper is now ready for use.

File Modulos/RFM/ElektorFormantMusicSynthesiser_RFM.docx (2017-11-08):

058— FORMANT

procedure given in the previous chapter. The offset and octaves per volt adjustments can also be carried out using the procedure given there. During the offset adjustment P4 should be set to minimum and S3 should be set to the 24 dB position. During the octaves/volt adjustment of P8 the Q control, P4, should be set to maximum, as with the 12 dB VCF.


Using the 24 dB VCF

As can be seen from figure 12, the 24 dB VCF is connected between the 12 dB VCF and the VCA, so that the IOS output of the 12 dB VCF goes to the IC input of the 24 dB VCF instead of to the VCA, whilst the VCA receives its input from the IOS output of the 24 dB VCF. The 24 dB VCF also has inputs from the three VCOs.

In addition to the signal connections the 24 dB VCF must also be provided with supply to the VCF module in accordance with the standard practice for Formant. Provision of control voltage inputs from the ADSR envelope shapers will be discussed later.

For satisfactory operation of the 24 dB VCF the correct setting of the input level is important, even more than in the case of the 12 dB VCF. On the one hand, the input level should not be so large that distortion occurs, but on the other hand it should not be so small that the signal-to-noise ratio is degraded. The 24 dB VCF is designed so that the optimum input level is obtained using three VCOs set to maximum output, with one waveform selected per VCO. If more than three VCOs are in use or more than one output waveform is selected from each VCO then the VCO output levels must be reduced. On the other hand, if only one VCO is used then the signal level may be too low. In

this case it is best to patch the EOS socket of the VCO to the ES input of the VCF, since this input has approximately three times the sensitivity of the hardwired VCO inputs.

The 24 dB VCF is capable of the same basic functions as the 12 dB VCF; driven by the KOV control voltage it will operate as a tracking filter, whilst the ENV and TM inputs allow dynamic modulation of the harmonic content of the VCF output. Due to the greater slope of the 24 dB VCF the setting of the ENV level control is more critical than with the 12 dB VCF, but if correctly adjusted then subtle nuances in the tonal character of the output signal are possible.

The question arises as to which ADSR envelope shaper should be used to control the 24 dB VCF, since only two are built into the basic Formant system, and control the VCA and 12 dB VCF respectively. Because of the modular construction of Formant it is, of course, perfectly feasible to build a third envelope shaper, which is the most versatile arrangement. The alternatives are to patch one of the other ADSR outputs to the TM input of the 24 dB VCF, or to hardwire the ENV input of the 24 dB VCF to the output of the envelope shaper that controls the 12 dB VCF. This latter arrangement is probably preferable, as it allows the ADSR signal to be fed to one or both VCFs by suitable adjustment of their ENV controls and also allows the possibility of patching the output of the other envelope shaper into the TM input of either VCF.

Figure 13. Test circuit for the selection of. OTAs.

OTA selection procedure

Although not absolutely essential, it is well worth selecting OTAs with closely matched transconductance characteristics to ensure that the four filter sections track accurately.

A test circuit for the OTAs is given in figure 13. This should be fed with a sinewave signal of about 2 V peak-topeak (or 0.7 V measured on an AC voltmeter) from a signal generator or from one of the VCOs. The output should be monitored on a 'scope or AC voltmeter. With a control current of 100 ,uA, measured on the multimeter in series with R5, the output voltage should be between 0.7 V and 1.3 V peak-to-peak. Without changing the input level or control current the OTAs to be tested should be plugged into the circuit one at a time and the output level for each OTA noted. The four OTAs whose output levels are most similar should be used in the VCF. The circuit can also be used to check the linearity of the transconductance v. control current characteristic of the OTAs, e.g. doubling the control current should double the output of the test circuit and halving the control current should halve the output.

chapter 8

resonance filter module

In addition to an almost limitless variety of non-natural, wholly 'electronic' sounds, the Formant music synthesiser can, of course, be used to imitate the voicing of conventional (mechanical) musical instruments. The filter module described in this article is designed to allow more realistic simulation of natural musical instruments by providing the fixed bandpass resonances which are an important determining factor in the timbre of mechanical tone generators.

Although music synthesisers are capable of producing the most `wierd and wonderful' electronic effects, it is a fact that they are frequently employed to imitate the sound of traditional acoustic instruments. Many commercially available synthesisers, for example, are provided with preset facilities for various common instrumental voices, whilst special units such as `string-synthesisers', which are designed solely to reproduce the sound of a string section, are becoming increasingly popular.

FORMANT — 059

As has already been explained, basic factors influencing the characteristics of a muscial note are pitch, dynamic amplitude, and dynamic harmonic content. As the reader will be aware, pitch and dynamic amplitude characteristics are controlled by the VCO (Voltage Controlled Oscillator) and VCA + ADSR (Voltage Controlled Amplifier and Attack - Decay - Sustain -Release) modules in the Formant synthesiser, whilst the VCF (Voltage Controlled Filter) is used to vary the harmonic content of the signal.

However, in the case of mechanical tone generators, for example brass and woodwind instruments, an additional consideration is the existence of resonant areas in the instrument which possess free vibration periods of their own. These resonances, which are known as formants (whence the name for the Elektor music synthesiser!) are determined by the shape and mechanical construction of the particular instrument (the wooden back and belly of a violin, the pipes of an organ etc.). Unlike the variable pitch of, say, a violin string, they tend to reinforce the same harmonics, whatever the pitch of the note being played. The nature of the formants in an instrument is in fact one of the factors which govern its quality. It should thus be apparent that, in order

to realistically simulate the tonal characteristics of traditional instruments, one must be able to tailor the static harmonic content of the note accordingly. What is required is a number of resonant filters with independently variable centre frequency, gain and Q-factor. These features are present already in the state variable VCF of the Formant; however, that is only one filter, and more to the point, in this particular application there is no need for the filters to be voltage-controlled, since the filter parameters will be preset to suit whatever musical instrument is being imitated. This explains the reason for the separate manually-controlled resonance filter module described in this article.

Figure 1. The fundamental frequency range of a number of traditional musical instruments, with reference to that of a grand piano. (From: Elektronik Taschenbuch, Band 1 Ferd. Thimmlers Verlag, Bonn; with kind permission from the publishers.)

The uses of resonance filters

The effect of resonance filters can best be heard on 'bright' sharp VCO waveforms which have a high proportion of fairly intense upper harmonics. The effect on vocal sounds can be illustrated by taking a suitable signal with a frequency of around 200 Hz, setting the Q of the filter to a mid-value, and varying the centre frequency from minimum to maximum. At first 'dark' sounding tones, largely devoid of higher harmonics will be obtained; as the centre frequency is increased however, one by one the various vowel sounds can be distinguished until, at high centre frequencies, reedy flute-like sounds are produced. The higher the Q of the filter, the more pronounced the above effects — and vice versa.

All bandpass resonances of musical importance lie between roughly 100 and 2000 Hz. Table 1 lists the main fixed resonances of a number of common musical instruments and also indicates which VCO waveform is best suited to imitate the instrument in question. This table is, of course, merely intended as a rough guide, in the final instance the decision should rest with one's own ears. Unless otherwise indicated, the Q-control should be set to the mid-position. As a further aid, figure 1 shows the fundamental frequency ranges of vari-

percussion | | | I.-- kettle drum
| | | —.--.04 I
plucked string instruments | | | I 1•II
| | | 1 guitar 1 la : ' ¹
| | | bass guitar i i
woodwind instruments | | | 1 I piccolo
| | | I I 1 I nuts
| | | I I 1 I I I I S soprano saxophone
| | | I e I 1 I I clarinet
| | | I I . i I I 0 ¹ 1 1
| | | bass saxophone hone M I I 1
| | | 1¹ 1 bassoon : 1 1 t
brass instruments | | | I 1 i trumpet 1 I
| | | I ¹ I 1 it I i . , I
| | | 1 It horn firt I i ' I+ trombone
| | | I i i i 1 ' I le 1. tuba I -1
| | | 1 I . I I I
bowed string instruments | | | 1 I I I I
| | | violin r • I i I I i I i iri violin cello
| | | I 1 i , 1 . 1 : i i double bass ' i
| | | 1.1 Is! i I I 1 i . . I
vocal | | | ¹ I I ¹ I I I I I a: I
| | | soprano 1 1 i I i I 1 I! 1
| | | I 1 1 i alto ri i 1 1 11 1 I I I I I I 1 I I I
| | | 14-1--r—,— i tenor ---1.--••••11.1 I i I 1 ¹1 I I I 1 I

bass —1-¹¹,-1----Isi

1 I 11 r4-1-1---1 . o ¹ i , II 1 I i

1 I I .
| | | | 1 1 t | II ! | ..I II 1-¹! | iliii | I! Ill III | 111 | 111 | ll I! Ill | 111 111 | lli _ | 111 | MI | II! | 11111 !

I c1 A2 27.5 Hz | Al 55.0 Hz | A 110.0 Hz | C1 dl f1 g1b1 c2 d2 a 220.0 Hz F.-- octave _1440.0 Hz | C³ a2 880.0 Hz | I c4 a³ 1760 Hz | c^s 84 3520 Hz

9951 -1


060— FORMANT

IS

nSi

ICI = LF 356 MINI DIP

Al . A4 = IC2 = TL 074, TL 084 A5 .. AS = IC3 = TL 074, TL 084 A9 . Al2 = 1C4 = TL 074, TL 084 IC5 = LF 357 MINI DIP

C10 C19 100 n P111,113?2,P4a,P46, P5,P7a,P713,P8,P10 =

47 k 50 ki log. P3s,P3b,P6a,P6b,P9a,P9b =

10 k log.

106.

SOS

9561 4


(I.P1ab) A II I :P4ob)

(111:P7861

(1.1¹2) 0 (11:P51

IIII:P81

.s----- to

I I :P3ab) (II:P6ab) (111:P9ab)

9951 - 3

[dB]

20 log (1 + —1

Flo


(IC51

EOS

a'

'OS

9951 - 2

(IC1)

)

IS

0

1IC2,R3 R16,C2,C3,P1 ... P3)

I

R

lily

ON

1IC3,R18 , 1131,C4,C5,P4. P6)

¹ SI

BYPASS/.

11C4,R33 R46,C6,C7,P7 ... P9)

LIM

2

ES

Figure 2. Block diagram of the resonant filter module. As can be seen, it possesses three independently variable filter sections.

instrument main resonance at

flute approx. 800 Hz

clarinet 1 . . 2 kHz*

oboe 1300 1700 Hz*

trumpet approx. 1500 Hz

bugle approx. 1000 Hz*

trombone approx. 600 Hz

French horn approx. 400 Hz*

tuba approx. 250 Hz

violin approx. 4000 Hz**

cello approx. 200 Hz**

double bass approx. 100 Hz**

NB:

VCO signal

fairly asym. squarewave sym. squarewave

heavily asym. squarewave (pulse)

heavily asym. squarewave (pulse)

'spaced' sawtooth sawtooth

'spaced' sawtooth sawtooth

sawtooth

'spaced' sawtooth, sawtooth or heavily asym. squarewave (pulse)

bassoon approx. 440 Hz*

* with, increased Q

** if possible, use several resonant filters (or a comb filter)

Figure 3. The frequency response of one of the three filter sections contained in the resonant filter module. The figure illustrates how the filter parameters can be independently varied by means of the control potentiometers.

Figure 4. Detailed circuit diagram of the filter module.

Figure 5. Track pattern and component layout of the filter module p.c.b. (EPS 99511 ).


FORMANT - 061

062 — FORMANT


Parts list to figure 4 and 5. Resistors: R1,R2,R48,R49,R51,R52 = 100 k R3,R8,R12,R15,R18,R23, R27,R30,R38,R42,R45 = 10 k R4,R6,R17,R19,R21, R32,R34,R36,R47 = 22 k R5, R9,1110,R20,R24, R25,R35,R39,R40 = 15 k R7,R22,R37 = 1 k (see text) R11,R14,R26,R29, R41, R44 = 220 S2 (see text) R13,816,R28,R31,R43,R46 = 12 k R50 = 470 sz, Potentiometers: P1,P4,P7 = 47 k (50 k) logarithmic, stereo, dia 4 mm P2,P5,P8,P10 = 47 k (50 k) logarithmic; dia 4 mm P3,P6,P9 = 10 k logarithmic, stereo; dia 4 mm
Capacitors (all Siemens MKM, MKH or other polycarbonate/polyester type) Cl = 680 n C2,C3,C4,C5,C6,C7 = 6n8 (see text) C8,C9 = 10.L C10 ... C19 = 100n Semiconductors: IC1 = LF 356 (National Semiconductors), Mini DIP 1C2,1C3,IC4 TL 084, TL 074 (Texas Instruments) IC5 = LF 357 (National Semiconductors) Mini DIP Miscellaneous: 31-way DIN 41617 edge connector or terminal pins Si = miniature SPDT 2 miniature sockets 3.5 mm dia. 10 x 10 mm collet knobs (with pointer) 1 front panel

ous traditional instruments, with reference to a piano keyboard.

Circuit

The basic requirements of the filter circuit are, independently variable centre frequency, Q and gain. Since the function of the filter is essentially to enhance a particular band of frequencies (corresponding to the formants of the instrument in question), the circuit is of the boost-only type, i.e. provides selective gain. Without the need to provide a selective cut (below the 0 dB line) the circuit design is considerably simplified. A total of three resonant filters forms an acceptable compromise between the number of settings required for reasonEbly realistic imitation and the constraints of space and economy. Of course, it is quite possible to double the rang of control facilities by connecting a second filter module in cascade with the first.
Block diagram The block diagram of the resonant filter module is shown in figure 2. The figures

FORMANT — 063

in brackets indicate which components in the final circuit are associated with the different sections of the circuit. Signals can be fed in via the panel-mounted socket (ES) or via the hardwired input (IS). A portion of the signal is fed direct to the output summing amplifier via R (R51 in the complete circuit) and the input signal is also fed to three bandpass filters whose gain, centre-frequency and Q can all be varied. The outputs of these filters are also summed in 105 via resistors Ro. The output of the filter module will thus consist of a portion of the original input signal plus signals boosted around the centre frequencies of the three filter stages. Two outputs are provided from the filter module, an internal hardwired output (I0S) and an output to a front panel socket (EOS). A bypass switch is provided, which allows the three filter sections to be switched out, in which case only the original signal appears at the output, and the gain is frequency independent, being unity.

EOS ES

ES

P10

BYPASS

7

"rimy =

1 t:m1

..... .iii."1•119.11 ,,,

1

41 c..:mir

111111EM

0 .....‘

LIZ INN - Ai :LIMN

El 4:

Mr

:;11 ■

ve fs

cosb

71¹. Win MO =mei 11 41 Aim | | | b

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

- =3•
- =
- = •
- =I •

•

= = •

- •

•

= •

- =I •
- = •
- Mal
- =I •

D.

1:13 •

I:=1 •

- =11 •

P1 | 9951.7

Figure 6. Because of the large number of controls, the front-panel for the resonant filter module is clearly different from the other Formant front-panels (EPS 9951-2).

Figure 7. Wiring diagram for the components mounted on the front-panel.

The amount of boost that can be provided by a filter section relative to the gain obtained in the 'bypass' condition is determined by the gain of the filter sections and the ratio R/Ro. If it is assumed that the filter gain can be varied between zero and one then the maximum amount of boost (in dB) is 20 log (1 + RE—).

The frequency response of a filter section is shown in figure 3. The figures in parentheses indicate which controls in the complete circuit vary the different parameters of the filter.

The complete circuit of the • filter module is shown in figure 4. IC1 sums and inverts the two input signals, whilst the three filter sections are of the state-variable type. The resonant gain of the filters is set by means of P1, P4 and P7 respectively. One gang of the pots is connected at the input, the other at the output of the filter. This has the effect of improving the dynamic range, since it means reduced noise and less chance of overloading. Finally, there is the inverting summing amplifier round IC5, which also cancels the phase shift introduced by ICI.

With the values for R and Ro given in the circuit diagram, the maximum gain of the filter is approx. +15 dB. The quality factor, Q, can be varied by P2 (P5, P8) between roughly 0.8 and 5. The centre frequency can be varied between approx. 50 and 2300 Hz, which is more than sufficient for normal use. The frequency range can, however, be modified by altering the value of a number of components; the necessary changes are detailed in the appendix. Maximum Q is obtained for the minimum resistance of the Q-potentiometer. The maximum Q can therefore be increased by reducing the value of R7 (R22, R37); in this way a Q of between 20 and 30 can easily be obtained. A high Q is useful when processing waveforms such as squarewaves, which have

very steep edges. These tend to set the filters 'ringing' at their resonant frequencies, and produce percussive effects. For R7 (R22, R37) = 470

a Q of 11.3 is obtained; R7 = 330 n gives a Q of 15.8, and R7 = 220 12 a Q of 23.4. The higher the Q, the more pronounced the percussive effect.

Construction

The printed circuit board for the resonant filter module is shown in figure S.

As far as the selection of components is concerned, the usual criteria apply. The only difference is that in view of the large number of front-panel controls (10 potentiometers) it is strongly recommended that miniature components (miniature pots with 4 mm diameter spindles) be used. In this way the controls can be arranged in functional groups of three to a row.

The front panel for the filter module is shown in figure 6, and the details of the wiring for the front-panel controls are illustrated in figure 7. In contrast to the

064 — FORMANT

other Formant modules, the resonant filter module requires no calibration or adjustment procedure. The operation of the circuit can be checked by feeding in a white noise input from the noise module. Varying the three filter parameters should produce clearly audible changes in the resulting sound. It will also be apparent that rapid variation of the Q- and fo controls produces effects similar to phasing, thus the filter module can be used to provide manual phasing.

The scale on each of the fo potentiometers on the front panel is calibrated with five nominal frequencies. The three middle settings in particular should be viewed as rough guidelines, since the resistance curve of logarithmic potentiometers can exhibit fairly wide tolerances.

The filter module should be placed between the COM-module and the power amp. However, if one wishes to use the headphone output on the COMmodule, the resonant filter module can be connected directly before the latter. Appendix

With the component values given in the circuit diagram, the centre frequency of the filters can be varied between roughly 50 and 2300 Hz. To calculate the correct values for higher frequencies than this, the procedure is as follows:

Firstly, the desired maximum frequency of fo can be used to calculate the value of C2 = C3 = C4 = C5 = C6 = C7 = C from the following equation:

16

C —

fo max

where C is in nanofarads and fo in kHz. Secondly the value of resistor R (see figure 2) can be determined on the basis of the desired minimum centre frequency fo

16

R — C • fo min

where C is in nanofarads, R is in kR, and fo in kHz

The value of Ro = R11 = R14 = R26 = R29 = R41 = R44 can be calculated from:

10

Ro —

R— 2

where R and Ro are in kfl. These equations can be used to check the values of figure 4.

chapter 9

ADSR

The ADSR (Attack-Decay-SustainRelease) shaper is used to control the VCF and VCA modules and thereby determine the dynamic harmonic structure and dynamic amplitude characteristic of the VCO signals.

It is often not realised, even by musicians, how much the character of an instrument is determined by the dynamic amplitude and harmonic behaviour, rather than by the steady-state harmonic content of the instrument. If the attack and decay periods of a note are artificially modified, then the whole character of the sound is altered. An interesting and amusing experiment is to record the sounds of several musical instruments, but to remove the attack and decay periods by bringing up the recording level after the note starts and fading it down before the note ends. Then ask some musical friends to identify the instruments. They will no doubt be amazed how characterless the sound of an instrument becomes when robbed of its particular amplitude envelope.

On the other hand, starting with a single basic waveform such as the triangle output of the Formant VCO, a whole range of instrument sounds can be produced simply by varying the amplitude envelope, ranging from 'soft' sounds such as flute and some organ voices, to 'hard', percussive sounds such as piano and xylophone.

Envelope control of the harmonic content using the VCF allows even greater variation in the character of the sound.

Types of envelope curves

The envelope shaper of the synthesiser must be able to simulate the envelope contour of conventional musical instruments when the synthesiser is used in an imitative capacity, and also to produce envelopes that are purely synthetic in character (i.e. not found in sounds produced by normal acoustic methods). Fortunately, there are relatively few types of envelope contour that are musically important, and these are all fairly easy to generate electronically.

1. Attadchlecay contour

The simplest type of envelope curve is that consisting only of attack and decay periods. The envelope contour rises to a peak when the note is played, and begins to decay immediately the peak is

passed (see figure 1). By varying the attack and decay times a wide variety of sounds can be produced.

For example, if a rapid attack and slow decay is applied to the VCA control, then a percussive sound like a piano results. Applied to the VCF in the low-pass mode, the same envelope contour can produce very bright, metallic sounds, depending on the input waveform.

If the attack period is made long and the decay period short, then applying this to the VCA will produce completely synthetic 'fantasy' sounds similar to those obtained by playing a recording backwards. Applying this type of envelope contour to the VCF can produce sounds similar to those of a brass instrument played staccato.

However, the main use of this type of envelope curve is for the production of percussive sounds such as xylophone, marimba, glockenspiel, bells and gongs, cymbals, and struck or plucked strings such as guitar, banjo, harp, other string instruments played pizzicato, harpsichord, and of course, piano.

2. Attack-sustain-release contour

The attack/decay characteristic previously described is typical of instruments where the sound is initiated by a short pulse of energy (e.g. by striking or plucking a string), after which the sound dies away since there is no further excitation to sustain it. The envelope contour shown in figure 2 is typical of instruments in which a note is sounded and sustained, such as a pipe organ, woodwind instruments, and bowed string instruments. In a pipe organ the note builds up fairly rapidly after a key is depressed as standing wave modes are established in the pipe, and the note is sustained by virtue of the fact that air is continuously blown into the pipe. When the supply of air stops on releasing the key the note terminates more or less rapidly.

The same basic contour applies to woodwind instruments and to string instruments played with a bow, since the note is here again sustained by blowing or bowing. However, with such instruments much greater expression can be obtained by modulation of the


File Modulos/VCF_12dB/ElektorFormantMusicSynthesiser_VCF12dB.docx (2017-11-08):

044 — FORMANT

chapter 6

12 dB VCF

This chapter introduces the first of the tone-shaping modules which process the 'raw' output of the VCOs to provide a wide variety of different tone colours and amplitude dynamics. The module presented here is a 12 dB per octave voltage-controlled filter (VCF) which is used to tailor the frequency spectrum of the VCO signal.

Before looking at the VCF circuit in detail, it is worth examining the ways in which the VCF is used. Four filter functions are available. A lowpass filter with a rolloff of —12 dB per octave above the turnover point, a highpass filter with a rolloff of —12 dB per octave below the turnover point, a band-pass filter with variable Q and minimum slope of —60 dB per octave on either side of the centre frequency, and a notch filter. The turnover point — or centre frequency in the case of the band filters — is the same for all four filter functions, and can be varied by the application of a control voltage.

Lowpass filter

The simplest use of the VCF is what might be called static tailoring of a VCO output using the KOV output of the keyboard to control the VCF. Suppose (to give a simple example), it is required to filter out a large proportion of the harmonics of the squarewave signal to produce a flutelike tone. The lowpass function of the VCF would be used and the turnover point would be set so that when a particular key was depressed the desired tone colour was obtained. If a higher note is depressed then the VCO pitch will increase. However, since the KQV output is also applied to the VCF the turnover point of the VCF will increase with the VCO frequency, so that it always remains in the same octave relationship to the VCO frequency. The same harmonic structure of the output waveform is thus maintained, — i.e. the VCF is being used as a tracking filter.

If the VCF is used simply as a tracking filter then the harmonic content of the output remains fixed for the duration of each note. However, dynamic variation of harmonic content during a note is also possible by controlling the VCF from the envelope shaper.

For example, to provide a good imitation of a trombone sound the note should initially start off with only a weak harmonic content. As the loudness of the note builds up the harmonic

content also increases, i.e. the note becomes 'brighter'. Similarly, at the end of the note it is the harmonics which die away first.

This is achieved by using the VCF in the lowpass mode as a tracking filter with ADSR control, i.e. with inputs from KOV and from the envelope shaper. When a key is depressed the turnover point is initially determined by the KOV input, and is set so that the harmonics are filtered out. As the envelope shaper output voltage rises (attack) the turnover frequency of the VCF is increased to pass more of the harmonic content. At the end of the note (decay) the envelope shaper output falls and the turnover frequency of the VCF is reduced to filter out the harmonics once more.

These two simple examples relate to the imitative capability of the synthesiser, since most people will have a `feel' for the sound of conventional musical instruments. However, it must once again be stressed that the synthesiser is not limited merely to an imitative role. It can also produce sounds that are unique to itself, that do not occur naturally and are totally `electronic'.

Highpass filter

So far only the use of the lowpass filter has been discussed. The highpass filter has the opposite effect to the lowpass filter, i.e. itcan be used to attenuate the fundamentals of notes while retaining the harmonics. This is obviously useful for sounds which have only a weakly developed fundamental or a bright tonal character, such as harpsichord and spinet type sounds, and certain string and brass instruments. When controlled by the envelope shaper the highpass filter can also give an 'ethereal' character to a sound.

Bandpass filter

In addition to the fundamental and harmonic series produced when a particular note of the instrument is sounded, brass and many woodwind instruments exhibit a number of fixed bandpass resonances, which are determined by the particular mechanical construction of the instrument. Use of the VCF as a bandpass filter with fixed centre frequency (KOV input switched off), together with a second VCF as lowpass tracking filter, allows these instruments to be more accurately imitated.

Pedal controlled Wa-Wa

Using the VCF in the bandpass mode with a fairly high Q-factor, A Wa-Wa effect can be obtained by controlling the VCF with a 0 to 5 V DC supply from a pedal-controlled potentiometer (such Wa-Wa pedals are available commercially or are easily home-made).

Notch filter

By sweeping the centre frequency of the

notch filter up and down the spectrum, either manually using a potentiometer or automatically using a low-frequency oscillator, phaser-type sounds can be produced. If this is done using a white noise input instead of a VCO then interesting `jet-aircraft' noises can be obtained.

Design of the VCF

As far back as 1965, R.A. Moog designed 24 dB/octave lowpass and highpass filters, and no satisfactory alternative to these was found for several years, although they were periodically 'reinvented' by others. It was not until the introduction of a specific type of integrated circuit, the operational trans-conductance amplifier (OTA), that a viable alternative became possible.

The Formant VCF is developed from the two-integrator loop shown in figure L Although a complete mathematical analysis of this circuit is beyond the scope of this book (those interested are referred to the bibliography), the basic concept is fairly simple to grasp.

The two-integrator loop can be considered as an analogue computer for the solution of a second-order differential equation. If the input resistor R1 and potentiometer PQ are removed, it can be seen that the circuit bears a remarkable resemblance to a quadrature oscillator. In fact, if the loop gain of the circuit is sufficient then it will function as an oscillator — at the frequency for which the differential equation solution holds.

PQ provides damping so that the circuit does not oscillate, but merely acts as a filter. Highpass, bandpass, and lowpass filter functions are available simultaneously at outputs (1), (2) and (3) respectively. At the turnover or centre frequency of the filters there is 90° phase shift between the integrator inputs and outputs. Thus between point (1) and point (3) there is 180° phase shift in all. By combining outputs (1) and (3) using a voltage follower A4 a notch function can be obtained. Since the two inputs are 180° out of phase at the centre frequency there is a null at the junction of the voltage follower's two input resistors at this frequency. Of course the centre/turnover of this filter is not voltage-controlled, but is fixed by the integrator constants R and C, so to achieve voltage control one of these elements must itself be voltage-controlled. Voltage control of capacitance is impractical in this application. Voltage controlled resistors are possible in the form of LED/LDR combinations or FETs, but unfortunately both these methods suffer from disadvantages such as unpredictable performance due to wide tolerances, small control range, poor linearity, and breakthrough of the control signal.

An alternative solution can be found by
re-thinking the basic integrator design.
The classic op-amp integrator consists

FORMANT — 045

Figure 1. The two-integrator loop used in the Formant VCF provides 12dB/octave highpass, bandpass and with the addition of A4, a notch filter.


Hardwired inputs:

KOV = Keyboard Output Voltage (from interface receiver).

ENV = Envelope shaper control voltage (from ADSR unit).

VCO 1, 2, 3 = From VCOs 1, 2 and 3.

Front-panel inputs:

ECV = External Control Voltage.

TM = Tone colour ('Timbre') Modulation input.

ES = External Signal, e.g. noise, input.

Outputs:

VCF/IOS = Internal Output Signal from VCF, (will be hardwired to a VCA).

EOS = External Output Signal from VCF (front panel output).

Front-panel controls:

OCTAVES ENV

TM ES

OUT ECV/KOV HP

BP LP N

= P1, coarse frequency adjustment.
= P2, sets envelope shaper control voltage.
= P3, sets tone colour modulation level.
= P4, sets external signal level.
= P5, 0-factor adjustment.
= P6, sets VCF/IOS output level (not EOS1).

= S1, selects external or internal control voltage input. = 52, selects high-pass output.

= S3, selects bandpass output.
= S4, selects low-pass output. = S2 + S4, selects notch (band-stop) output.

Figure 2. Instead of normal op-amps, OTAs are used in the Formant VCF. The output current change is gm times the input voltage change, but gm can be varied by feeding in a control current IABC-

Figure 3. The OTA integrator used in the Formant VCF. The integrator time constant is controlled by the current !ABC. A high impedance buffer ensures that all the output current of the OTA flows into the integrator capacitor.


of a differential-input voltage amplifier with the non-inverting input grounded. An input resistor connected to the inverting input (which is a virtual earth point) converts the input voltage into a proportional current. Since this current cannot flow into the inverting input it must flow into the feedback capacitor, and a voltage appears across the capacitor (and hence at the op-amp output).

It is fairly obvious that the op-amp is functioning simply as a voltage-tocurrent converter, and an equivalent circuit for an integrator would be an amplifier with a voltage-controlled current output, with a capacitor connected, not in a feedback loop, but between the output and ground. Varying the voltage-current transconductanbe of the amplifier would then effectively vary the 'resistance' constant of the integrator.

A suitable device exists ready-made in
the shape of the operational trans-
condunctance amplifier or OTA. This is

046 — FORMANT


R33

R10

47k

lin

7k

15V

C3

680n

CI MO

680n

15V

IC1" = CA3084 (DIL)

IC2,1C3,IC8 =pA741C, MC1741 CP1 (MINI DIP)

I C4,I C5 = CA3080, CA3080A*

T1,T2 = BF245A, B

⁴¹ see text

R3

100k

R4
33k

R5 47k

KOV

_b9

ECV

ENV

P2

33p

Rt5

p...1 39k I.—

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
47k log

R18

VC01

VCO2

VCO3

R12

R13

R14

R17

R19

R21 CR22

8

b

52

R28

100k l'n

P5

9725 4

an amplifier that produces an output current which is proprotional to the input voltage, i.e. i = gm • ui, where i is the output current, ui is the input voltage and gm is the transconductance. The feature of the OTA which makes it ideal for the VCF is that the trans-conductance gm is determined by a control current ImEtc, thus gm = k • 'ABC, where k is a constant. This is illustrated in figure 2.

For the CA 3080 OTA used in the Formant VCF the constant k is 19.2 V⁻¹ at an ambient temperature of 25° C, and so gm = 19.2 x 'ABC mS (milliSiemens = milliamps/volt). This IC is particularly suitable because of the outstanding linearity of its transconductance characteristic over three decades of control current, and because of its relatively small tolerance in the value of 'k' (2:1 for the 3080 and 1.6:1 for the 3080A). However good linearity is achieved only for small input signals, and the input voltage must be attenuated to about ± 10 mV when used in the

VCF.

Figure 3 shows the circuit of the integrator used in the Formant VCF. The input voltage is attenuated by the potential divider connected to the inverting input, and across the output is connected the 180 p integrating capacitor.

To maintain correct operation of the integrator the total output current of the OTA must flow into the integrator capacitor, which means that a buffer stage with a very high input impedance is required on the OTA output to avoid `current-robbing'. A FET connected as a source-follower is used for this purpose. The control current IABC is fed in through a 27 k resistor. The integrator time constant is inversely proprotional to the control current, so the VCF centre/turnover frequency is directly proportional to the control current.

Complete circuit of the VCF

Figure 4 shows the complete circuit of

the VCF. The actual filter circuit has a linear frequency characteristic and is current controlled. It must therefore be preceded by an exponential converter that converts the input control voltage into an exponentially related control current, so that the VCF tracks with the same 1 octave/V characteristic as the VCOs.

The exponential converter occupies the upper portion of the circuit, and is essentially similar to that of the VCOs. However, the control characteristic of the VCF does not need to be so accurate as that of the VCO, since a small error will only introduce minor, unnoticeable errors in amplitude response, whereas the same error in the VCO characteristic would cause unacceptable tuning errors.

For this reason the VCF exponential converter is provided only with a passive input adder (cf. figure 2a of the last chapter), and temperature stabilisation of the exponentiator is dispensed with, thus saving the cost of a not in-

FORMANT — 047


Figure 4. Complete circuit of the Formant VCF, which consists of a voltage-current exponential converter and a linear current-controlled filter.

Figure 5a. Two well-matched PNP transistors may be used in place of IC1 for greater economy. The pin numbers shown correspond to the pinout of IC1.

Figure 5b. The CA 3080 is available in two packages. If the TO- package is used the leads must be bent to fit the DIP layout on the p.c.b.

expensive AtA726 IC. However, temperature compensation is retained in the form of a matched transistor pair. The circuit differs here from the VCO since the exponentiator must source current into the OTAs rather than sinking it as in the VCO, so PNP transistors are used.

Since temperature stabilisation is not used, a number of options are open for the choice of the matched transistor pair. Those who have access to a good transistor tester or curve tracer can select a matched pair of any small signal medium gain (`B' spec) transistors such as the BC 179B, BC 159B, BC 557B etc. These are then glued together with epoxy adhesive for good thermal tracking as shown in figure 5a, taking care that there is no electrical contact between the cases if metal-can types are used. (Note that the pin numbers given in figure 5a correspond to the IC pinning in figure 4).

The preferred solution is to use a
CA 3084 transistor array, which is what

was used in the prototype, but if this is difficult to obtain then almost any dual PNP transistor, such as the Analog Devices AD 820 . . . AD 822, Motorola 2N3808 ... 2N3811 or SGS-ATES BFX 11, BFX 36, will do.

Note that the value shown for R6 ( 1k8) is correct when using the CA 3084. If a dual transistor is used, it is advisable to reduce the value of R6 to 1k5.

The current-controlled filter consists of IC3, 1C4 and IC5. It will be noted that the integrators 1C4 and IC5. are non-inverting. This does not affect the operation of the circuit, since non-inversion has the same effect as the double inversion that takes place in figure 1. However, it does ensure that the three outputs of the filter are in the same sense, whereas in figure 1 the bandpass output is inverted with respect to the other two outputs.

IC6 functions as an output buffer, and also as a summing amplifier for the high-pass outputs to provide the notch function. By setting S2, S3 or S4 in position `a', highpass, lowpass or bandpass functions respectively may be selected. By setting both S2 and S4 in position 'a' the notch function is obtained. Since IC3 is connected as an inverting amplifier and IC6 also inverts, this double inversion means that the output signal is non-inverted with respect to the input signals. The overall gain of the VCF (in the passband) is x 1 (OdB).

Inputs, controls and outputs

The exponential converter section is equipped with a coarse octave tuning control P1 (note the absence of a fine control as compared with the VCO) and two presets P7 and P8 to adjust the offset and octave/V characteristic.

KOV and ECV control inputs are provided, as for the VCO. The input for envelope shaper control (ENV) is adjustable by means of P2. The tone colour modulation input controlled by P3/(TM) is analogous to the FM input of the VCO, i.e. it allows the centre/turnover frequency of the VCF to be modulated. There are four signal inputs, three internally-wired VCO inputs and one external

signal (ES) input, whose amplitude can be controlled by P4. The Q-factor of the filter is controlled by P5.

Switches S2 to S4 select the desired filter type, as has already been described. Two outputs are provided, an uncontrolled output EOS which is brought out to a front-panel socket, and an internal output 10S, which is controlled by P6.

Construction

A printed circuit board and component layout for the VCF are given in figure 6. The same considerations of component quality apply to the VCF that apply to all parts of the synthesiser. As mentioned earlier, two basic versions of the CA 3080 are available. The CA 3080A has better specifications as regards tolerance, and extended temperature range, but the basic CA 3080 is quite adequate (assuming that the synthesiser is not to be used in Antarctic blizzards).

The CA 3080 is available in two packages, TO- can and mini-DIP, both of which are shown in figure 51). The p.c. board is laid out for the mini-DIP version, but the TO- version can easily be accomodated by splaying out the leads to conform with the mini-DIP pinning (in fact some TO- package 3080s are supplied with this already done).

The FETs T1 and T2 must be tested as detailed in chapter 3 and their source resistors R23 and R27 selected in accordance with Table 1 of that chapter. A front panel layout for the VCF is given in figure 7, and a wiring diagram for the front-panel mounted components is shown in figure 8.

Testing and adjustment

During assembly, it is convenient to use IC sockets so that the current-controlled fiter section of the circuit can be tested independently of the exponential converter. To test the CCF, IC1 is removed and a 100k log potentiometer is connected `back-to-front' between ground and -15V (i.e. so that the end of the track approached by clockwise rotation of the wiper is connected to ground).

A multimeter set to the 100 ALA range is

'MI.- MAMA Pi T


7116 )•(7310

rk''°° L

•


51

a C°

41 OP 3

roo RO tilt"

¹¹6 -4 0114510

0920-{Frallo E co-1142810

1210

01R3,40

a10⁴¹

A.,40°.1 to

ea s

ti 0

Ytp

0⁻i

a [0

041 FV0

Pc•fm⁻10

o

0

4:042

0

lisvoo
0
mow

vco 0

3⁰0

2 0o

0

0

0

L

Q!! I CJSQ

0

0

0

li [

0 ⁴ ,.. I CH R8 fo

.0 40.111%6

0 0 os301R301.0

C94

T2 c

ciec#9 C

C

S a

K CIV
ENV


U D

⁻t.r'sfi 0

04 R 473j0 C7

0

tr

Parts List

Resistors:

R1, R2, R28, R29,

R30, R34 = 100 k

R3 = 100 k (1% metal oxide)

R4 = 33 k

R5 = 47 k

R6 = 1k8 (see text)

R7, R9 = 330 k

R8 = 2k2

R10, R33 = 27 k
R11, R12, R13, R14,

R15, R16, R20, R24 = 39 k

R17 8k2

R18 = 22 k

R19 = 1 k

R21, R22, R25, R26 = 100 SZ
R23, R27 = 12 k (nominal value,
see text)

R31 = 33 k

R32 = 470 SZ

Potentiometers:

P1, P5 = 100 k lin
P2, P3 = 47 k (50 k) lin P4 = 47 k (50 k) log

P6 = 4k7 (5 k) log

Presets:

P7 = 100 k

P8 = 470 SI (500 SZ)

Capacitors:

Cl, C3, C4, C5, C10 = 680 n C2 = 1 n

C6, C7 = 33 p

C8, C9 =180 p

Semiconductors:

IC1 = CA3084 (DI L) see text.

1C2, IC3, IC6 = AA 741 C (Mini DIP),

MC1741 CP1 (Mini DIP). IC4, 105 = CA 3080 (A)

T1, T2 = BF 245a, b.

Miscellaneous:

31-way plug (DIN 41617)

S1 - S4 = miniature SPDT toggle switch

| | | | | FORMANT — 049


| Figure 6. Printed circuit board and component layout for the VCF. (EPS 9724-1).

connected between the wiper of the potentiometer and the junction of R10 and R33, an input signal is provided to the VCF from a sinewave generator or from the VCO, and the Bandpass output is monitored on an oscilloscope. The test then proceeds as follows:

1. Set the Q-factor of the filter to maximum (wiper of P5 turned towards R19).
2. By means of the 100k log potentiometer set the control current to 50 ;IA on the meter.
3. Slowly increase the generator frequency from about 300 Hz to 1500 Hz; somewhere in this range the VCF output should peak as its resonant frequency is reached (i.e. there will be a sharp increase in output at a particular frequency with a fall-off on each side). Note the frequency at which resonance occurs,
4. Increase the control current to 100 ttA and check that resonance now occurs at twice the previously noted frequency.

Note. Tests 2 to 4 are intended to check the linearity of the filter frequency v. control current characteristic. The tolerance in the absolute value of filter frequency for a given control current is due to OTA tolerances and is unimportant provided linearity is maintained i.e. the filter frequency doubles for each doubling of control current.

5. Set the generator to about 50 Hz and check that it is possible to obtain resonance at this frequency by varying the control current with the 100 k potentiometer. Repeat this test at 15 kHz.

The exponential converter can now be tested after inserting IC1 and removing IC4 and IC5. A multimeter set to the 100 /IA range is connected from the bottom end of RIO to -15V and the wiper voltage of P1 is monitored with a voltmeter.

The test and adjustment now proceed as follows:

I. Set P8 to its mid-position, and turn P1 fully anticlockwise so that its wiper voltage is zero. Adjust P7 until the mircroammeter reading is 50 ttA.

2. Turn PI clockwise until its wiper voltage is 1V, then adjust P8 until the microammeter reads 100
3. Repeat the procedure for 2V, 3V, 4V etc. on the wiper of P1 , checking that the exponentiator output current doubles for every 1V increase.

Offset adjustment

Now that the two sections of the VCF have been checked, IC4 and IC5 can be re-inserted so that the entire VCF can be checked as a functional unit, as follows:

I. A squarewave with 50% duty-cycle at a frequency of about 500 Hz is fed to one of the filter inputs. P1 is turned fully clockwise and P7 is turned anticlockwise. 1 The lowpass output of the VCF is
| | | Figure 7. Front panel *out for ins Val.

monitored on an oscilloscope, and at this stage should appear at the output without degradation.


ECV

i⁾

TM

ECV/KOV •

060=CONWIPMIT

T

nn

ICI

VV

•

Os 4 n...1 ala

9 •40 —

283

9

%%HP 0

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
Figure 8. Wiring diagram for the

mounted components.

ms •

tput peaks.

o further read-the output to one note to

may have been nd if necessary in the offset

til no further fined.

uctance mmable active *gn, September

ontrolled
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

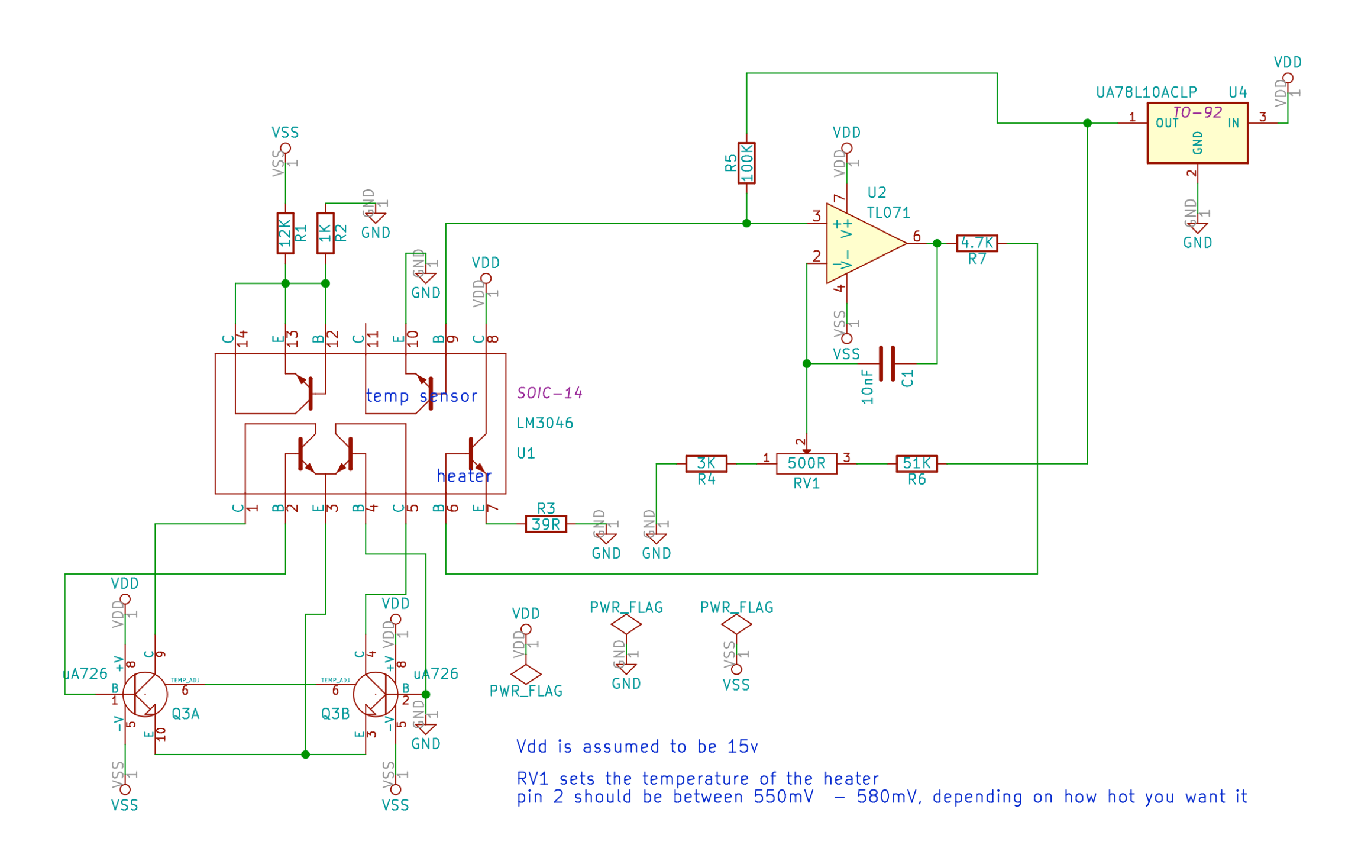
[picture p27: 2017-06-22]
Componentes_Electronicos/Formant_V2_Reemplazados/Reemplazo_UA726/ua726replacer-schematic.png

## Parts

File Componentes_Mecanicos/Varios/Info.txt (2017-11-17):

Los ficheros de extensión .FCStd son ficheros CAD realizados con FreeCad:

https://www.freecadweb.org

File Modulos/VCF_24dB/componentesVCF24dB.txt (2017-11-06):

https://www.amazon.es/CONMUTADOR-ROTATIVO-3CIRCUITOS-POSCIONES-SOLDAR/dp/B01M06IH2Q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
https://www.amazon.es/Interruptor-Miniatura-Posiciones-Terminales-Conector/dp/B01JA45CXG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
https://www.amazon.es/SODIAL-Interruptor-Palanca-Posicion-Bipolar/dp/B00H3CVMTQ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

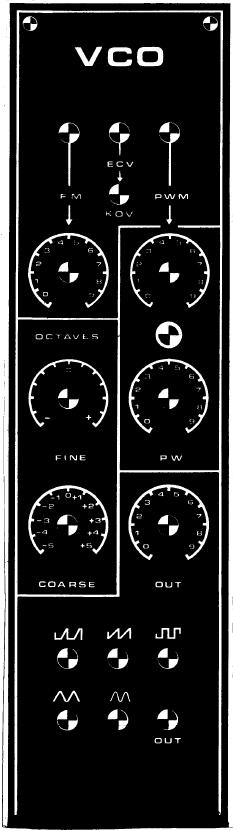
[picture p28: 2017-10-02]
Componentes_Mecanicos/Caratulas/Varios/Caratula_Demo.jpg

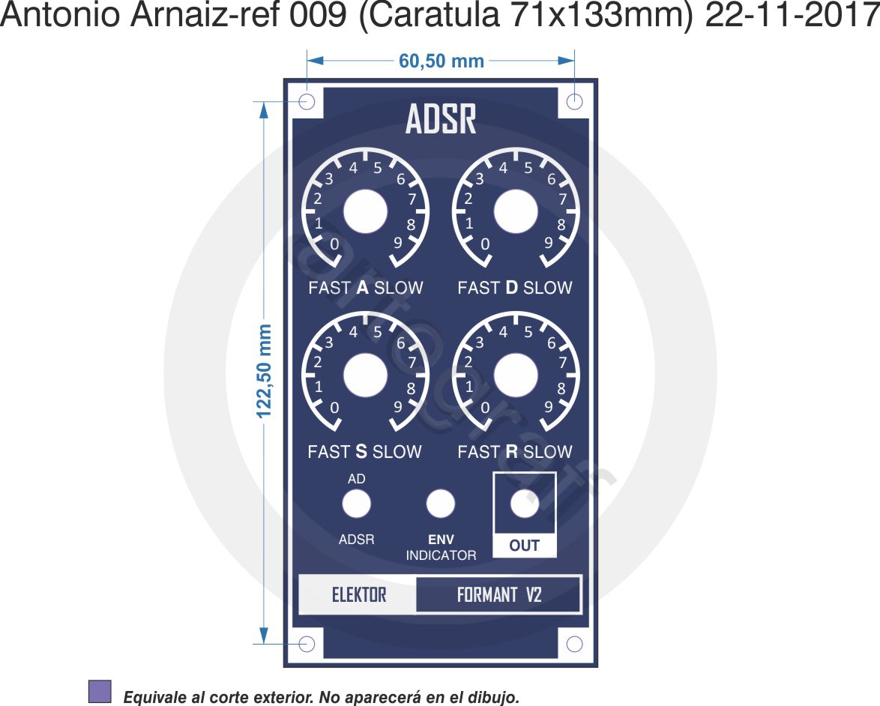
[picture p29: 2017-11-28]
Componentes_Mecanicos/Caratulas/Presupuestos_171028/Antonio Arnaiz-ref 009 (Caratula 71x133mm) 22-11-2017.jpg

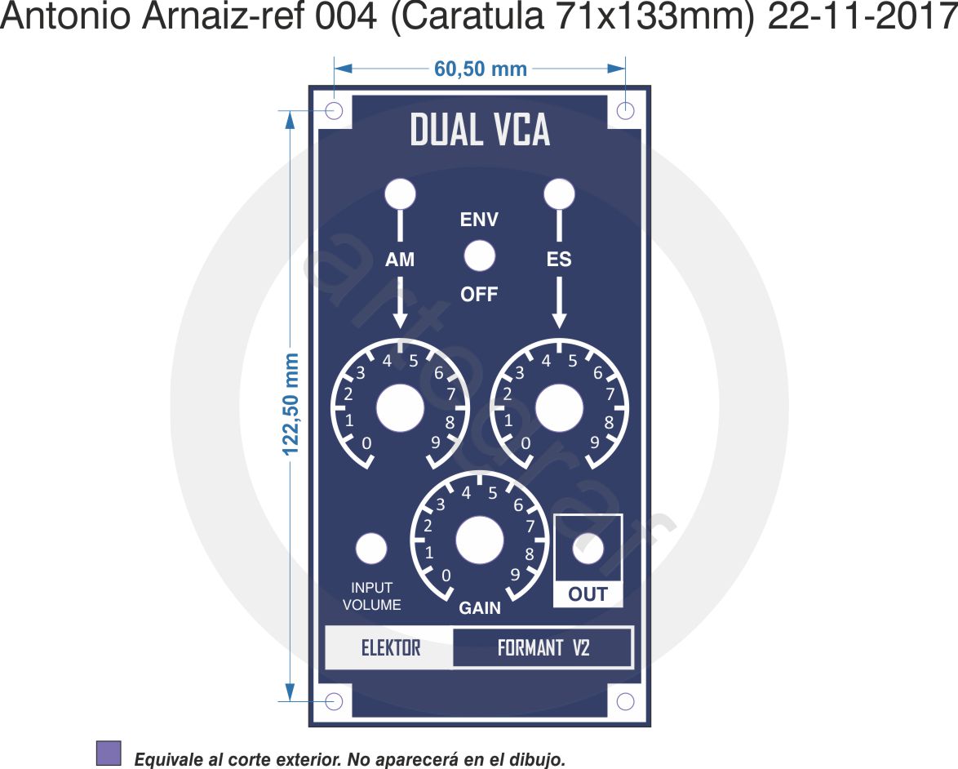
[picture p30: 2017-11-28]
Componentes_Mecanicos/Caratulas/Presupuestos_171028/Antonio Arnaiz-ref 004 (Caratula 71x133mm) 22-11-2017.jpg

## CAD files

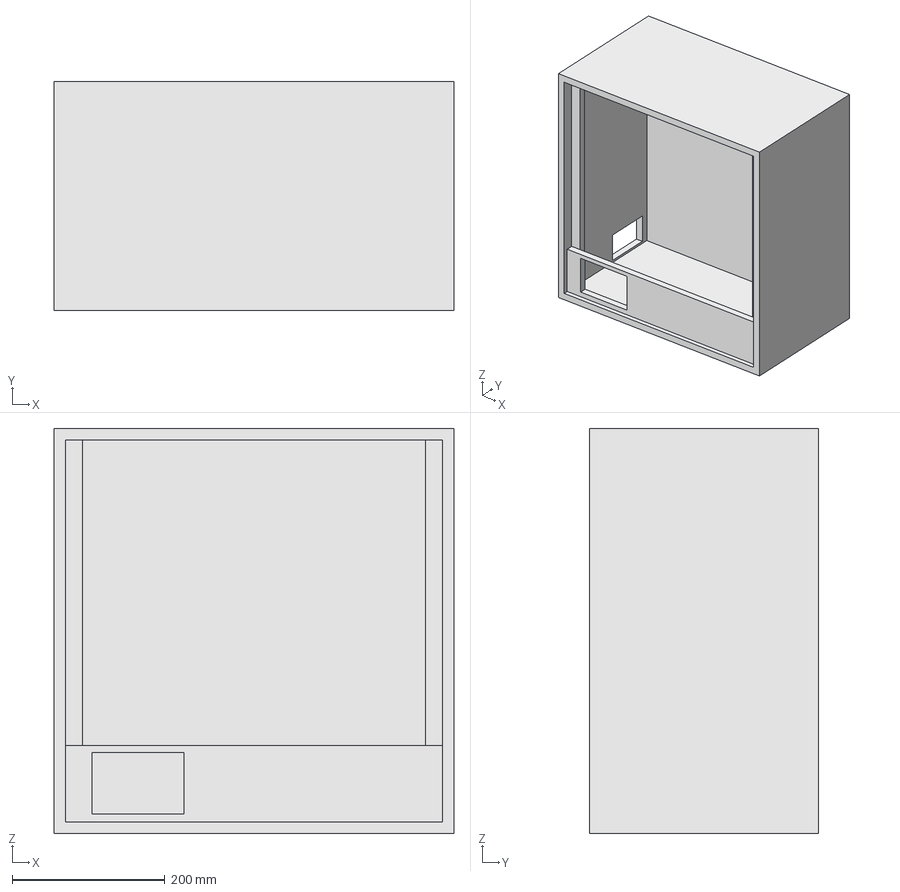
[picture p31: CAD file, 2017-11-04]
Componentes_Mecanicos/Mueble_Racks/Formant_V2_Mueble.FCStd
523.0 x 300.0 x 530.0 mm

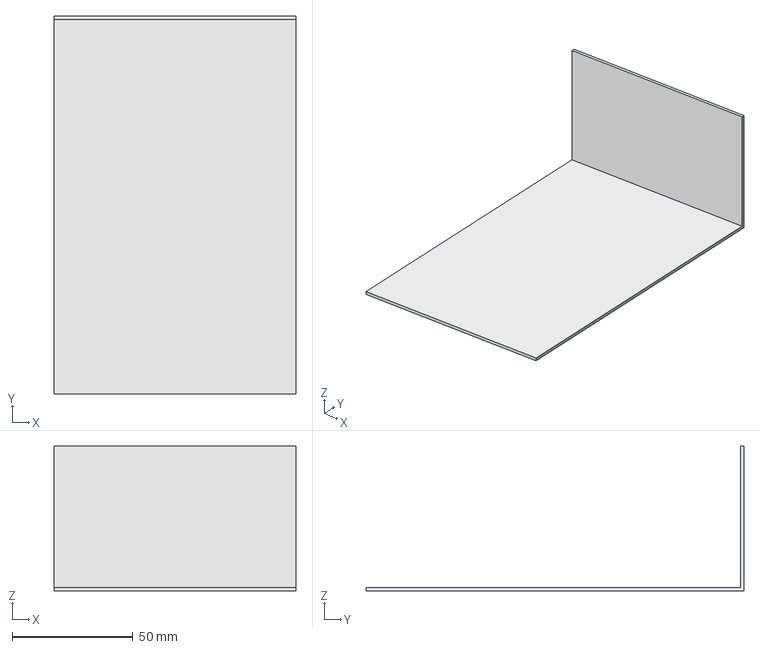
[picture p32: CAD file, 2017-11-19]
Componentes_Mecanicos/Varios/Formant_V2_Guia_3U.FCStd
100.0 x 156.5 x 60.0 mm

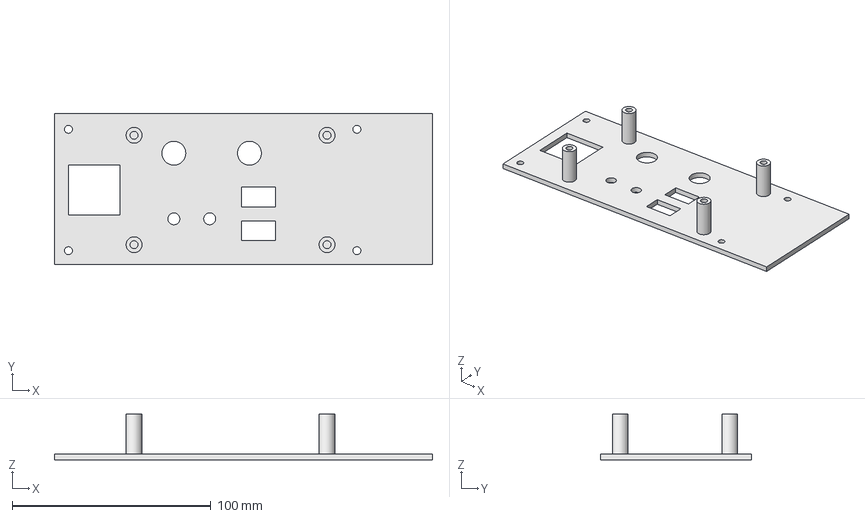
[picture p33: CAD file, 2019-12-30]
Modulos/GENERADOR_ECO/PT2399/Caratula_Eco.FCStd
190.0 x 76.0 x 23.0 mm

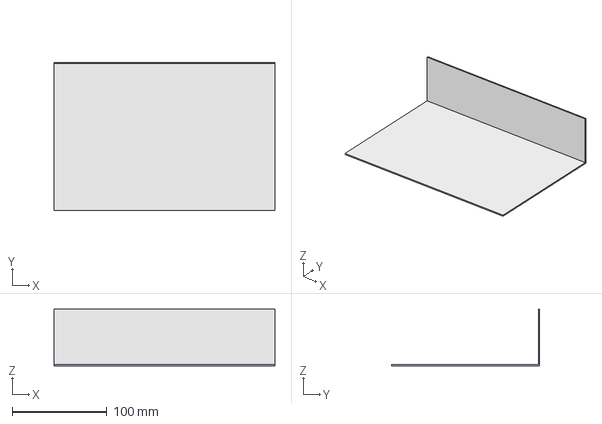
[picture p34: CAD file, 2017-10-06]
Componentes_Mecanicos/Varios/Formant_V2_Guia_6U.FCStd
233.0 x 156.5 x 60.0 mm

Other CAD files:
Modulos/GENERADOR_ECO/PT2399/Caratula_Eco.stl

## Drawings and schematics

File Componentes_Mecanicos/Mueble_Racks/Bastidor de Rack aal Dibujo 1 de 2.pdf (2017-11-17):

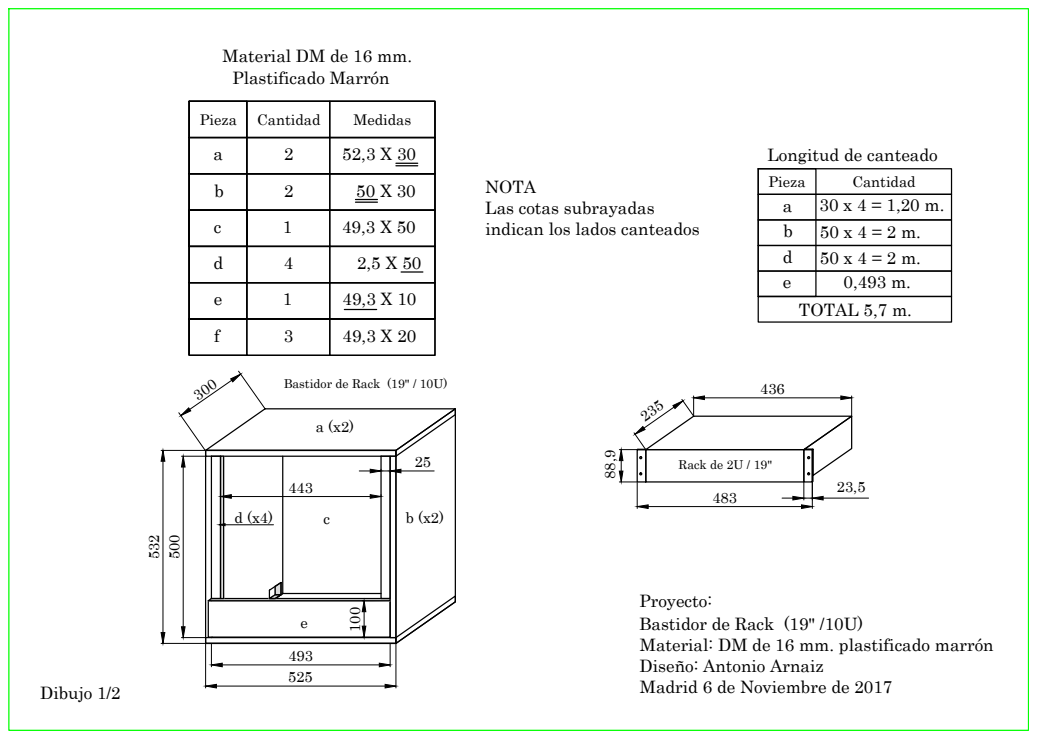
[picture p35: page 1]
Longitud de canteado Pieza abde; Cantidad 30 x 4 = 1,20 m. 50 x 4 = 2 m. 50 x 4 = 2 m. 0,493 m.; TOTAL 5,7 m.; 300 525 493 25 500 443 Rack de 2U / 19" 436 483

0DWHULDO'0GHPPSODVWLILFDGRPDUUyQ 'LVHxR$QWRQLR$UQDL] Madrid 6 de Noviembre de 2017 NOTA Las cotas subrayadas indican los lados canteados Material DM de 16 mm. 3ODVWLILFDGR0DUUyQ Dibujo 1/2

235 Pieza abcde Cantidad Medidas 22141 52,3 X 30 50 X 30 49,3 X 50 49,3 X 10 2,5 X 50 f 3 49,3 X 20

Bastidor de Rack (19" / 10U)

100Proyecto: Bastidor de Rack (19" /10U)

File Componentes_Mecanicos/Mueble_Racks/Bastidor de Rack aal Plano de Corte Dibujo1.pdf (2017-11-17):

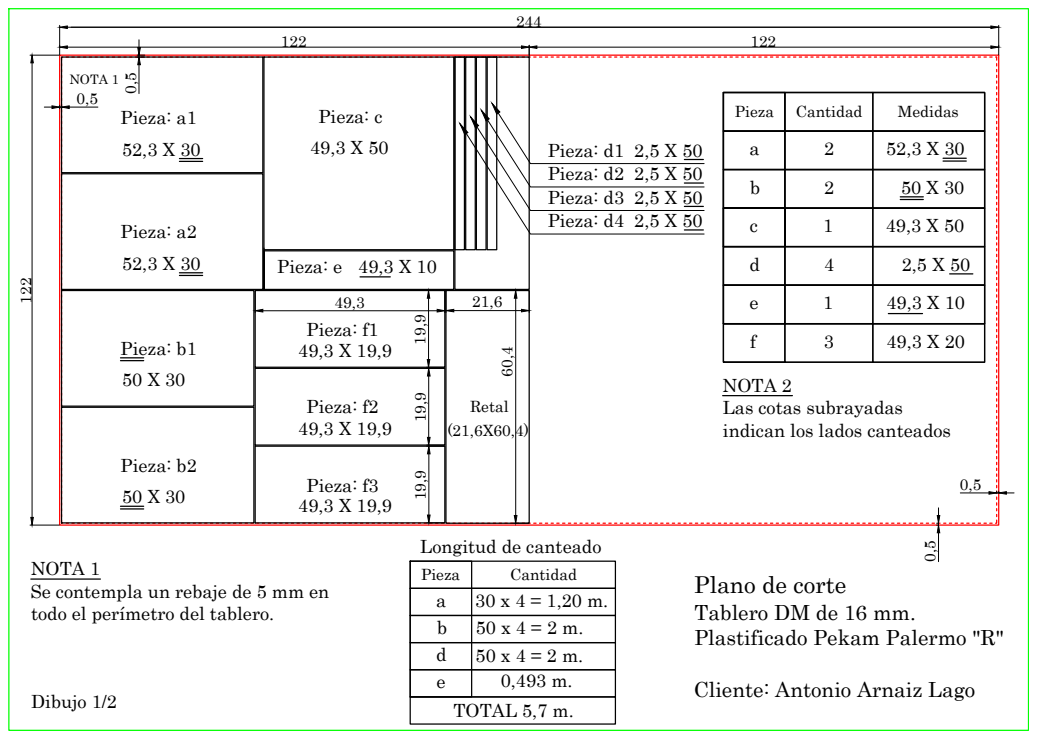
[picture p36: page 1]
49,3 X 10 Pieza: a1 Pieza: a2 50 X 30 Pieza: b1 Pieza: b2; Pieza: c Pieza: e; Retal 52,3 X 30 50 X 30; NOTA 2 Las cotas subrayadas indican los lados canteados Dibujo 1/2; Plano de corte Tablero DM de 16 mm. Plastificado Pekam Palermo "R" Cliente: Antonio Arnaiz Lago (21,6X60,4); Pieza: d1 2,5 X 50 Pieza: d2 2,5 X 50 Pieza: d3 2,5 X 50 Pieza: d4 2,5 X 50 Longitud de canteado Pieza abde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

122 NOTA 1 Se contempla un rebaje de 5 mm en

WRGRHOSHUtPHWURGHOWDEOHUR

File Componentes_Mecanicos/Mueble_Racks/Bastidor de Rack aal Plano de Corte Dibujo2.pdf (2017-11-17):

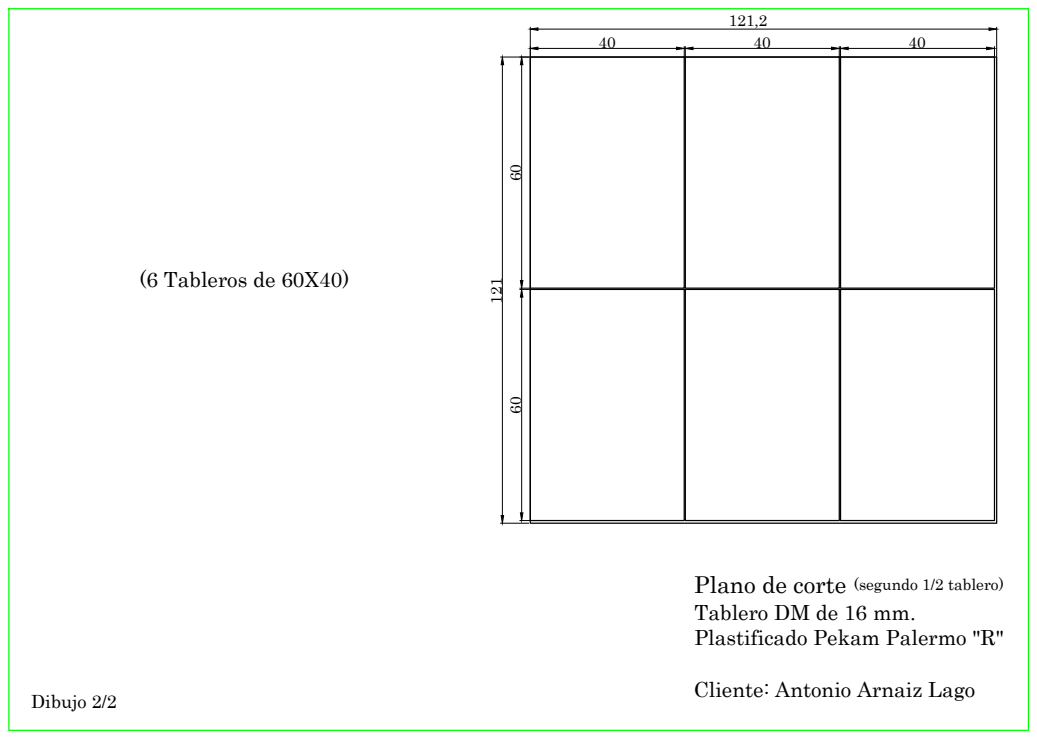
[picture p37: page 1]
60 60 (6 Tableros de 60X40); Dibujo 2/2

Plano de corte (segundo 1/2 tablero) Tablero DM de 16 mm. Plastificado Pekam Palermo "R" Cliente: Antonio Arnaiz Lago

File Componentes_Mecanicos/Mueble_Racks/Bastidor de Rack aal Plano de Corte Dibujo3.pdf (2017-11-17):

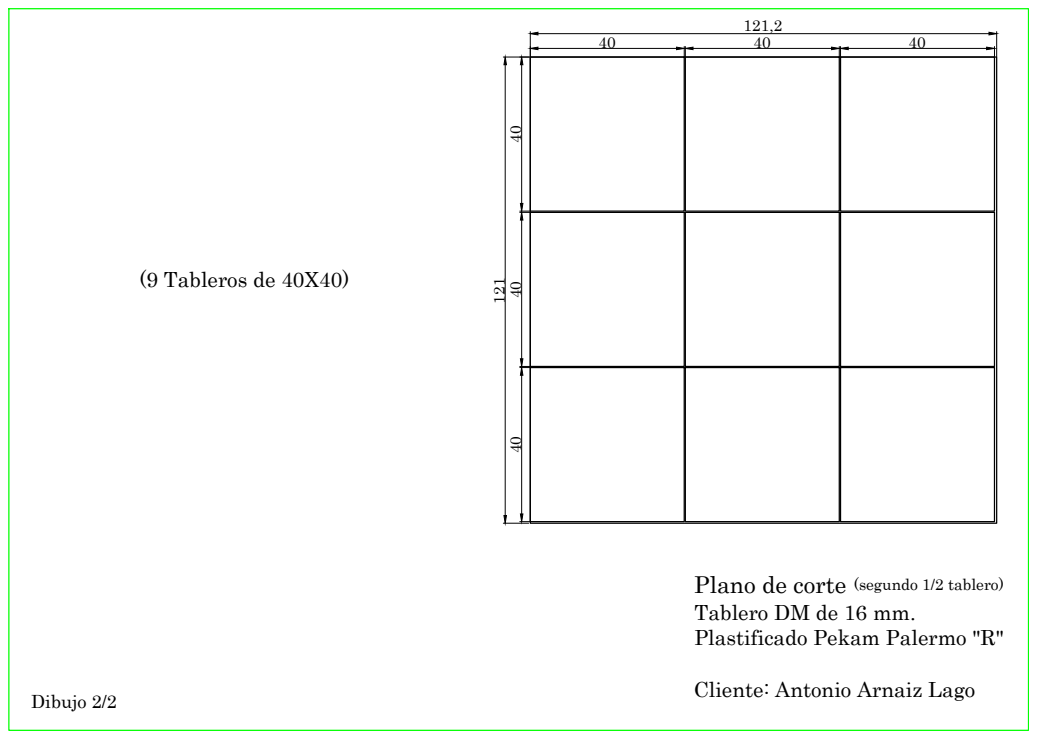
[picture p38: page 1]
40 40 40 (9 Tableros de 40X40); Dibujo 2/2

121 Plano de corte (segundo 1/2 tablero) Tablero DM de 16 mm. Plastificado Pekam Palermo "R" Cliente: Antonio Arnaiz Lago 40 40 40

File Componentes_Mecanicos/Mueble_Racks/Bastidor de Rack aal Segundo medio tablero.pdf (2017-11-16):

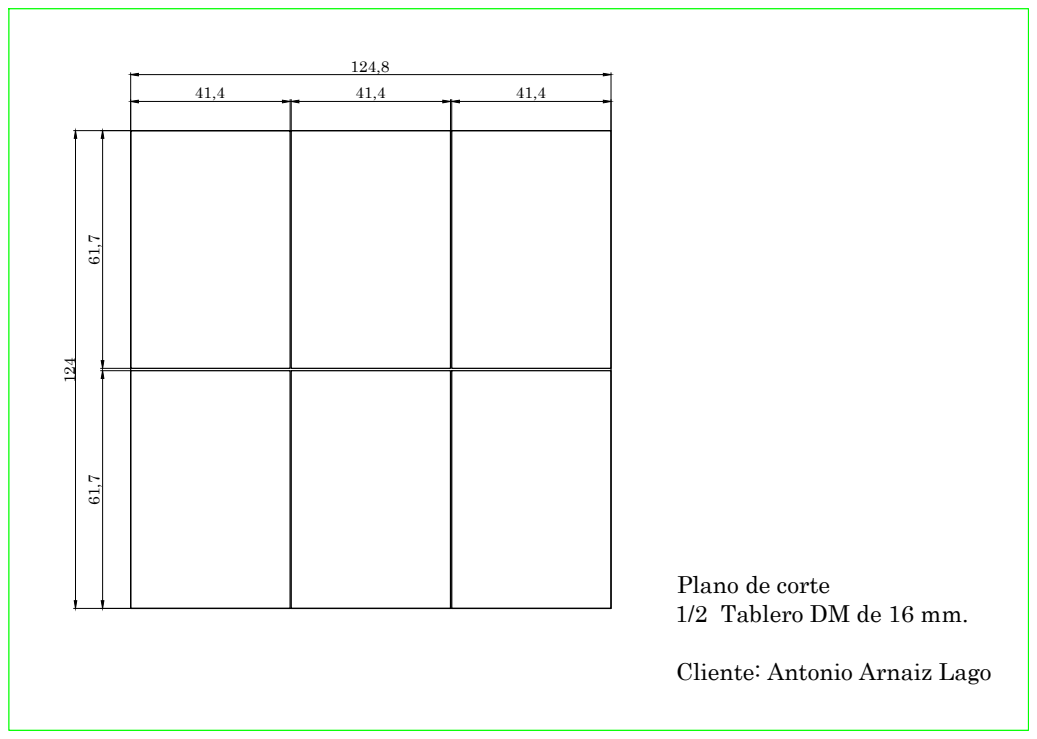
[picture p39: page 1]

61,7 61,7 Plano de corte 1/2 Tablero DM de 16 mm. Cliente: Antonio Arnaiz Lago

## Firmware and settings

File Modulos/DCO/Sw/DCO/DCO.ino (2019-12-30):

// ---------------------------------------------------------
//
// Proyecto:       Formant_V2
// Version:        1.0
// Fichero:        DCO.ino
// Autor:   
// Hardware:       Arduino Nano V3.0
// Fecha:          Diciembre 2019
//
// Funcionalidad:  
//                 
//
// Notas:          
//
// ---------------------------------------------------------

#include <Arduino.h>
#include <stdlib.h>
#include <SPI.h>
#include <MD_AD9833.h>



// ------------------------------------------------------------
//
//
//
//
// ------------------------------------------------------------


#define IDE_HW_PIN_LOAD_AUTO  3         // Pin para cargar datos en el buffer de memoria
#define IDE_HW_PIN_LOAD_CLK   2         // Generacion de reloj en modo load
#define IDE_HW_PIN_LOAD_RESET 4         // Reset contador de direcciones del buffer 6116 en modo load
#define IDE_HW_PIN_LOAD_WR    5         // Escritura en memoria en modo load
                                 
#define IDE_HW_PIN_SER        6         // Datos serie para cargar los HC595
#define IDE_HW_PIN_LATCH_GEN  8         // Señal para almacenar datos (latch) en los HC595 que cargan datos en la ram de generacion de onda (6116) 
#define IDE_HW_PIN_CLK        7         // Reloj para cargar los HC595 
#define IDE_HW_PIN_LATCH_LED  12        // Señal para almacenar datos (latch) en el HC595 que controla los leds de forma de onda

#define IDE_HW_POT_COARSE     A0        // Entrada del potenciometro de COARSE  
#define IDE_HW_POT_FINE       A1        // Entrada del potenciometro de FINE
#define IDE_HW_INPUT_KEYS     A2        // Lectura de pulsadores de seleccion de onda

#define IDE_HW_PIN_HC245      9         // Control del HC245
                                        // 0: A --> B
                                        // 1: B Alta Impedancia

#define IDE_HW_SPI_FSYNC      10        // SPI Load pin number (FSYNC in AD9833 usage)
#define IDE_HW_SPI_DATA       11        // SPI Data pin number
#define IDE_HW_SPI_CLK        13        // SPI Clock pin number


#define IDE_MODO_LOAD         0         // Modo Load, cargar datos en el buffer HW formado por los 6116
#define IDE_MODO_AUTO         1         // Modo de generacion de onda definida

#define IDE_DELAY_RESET_ADDR  1000      // Duracion en ms del pulso para resetear el contador de direcciones 4040
#define IDE_MAX_HW_BUFFER     2048      // Tamaño en Kbytes de la memoria utilizada para definir la onda ( Dos chips 6116 2Kx8 )
#define IDE_MAX_HW_DAC        1024      // Valor maximo de una muestra enviada al DAC ( DAC 10 Bits, 0 ... 1023)

#define IDE_FREQ_DEFECTO       901088L  // Frecuencia a cargar por defecto en el AD9833, genera la nota LA de 440Hz
#define IDE_FREQ_FINE           20480L  // Frecuencia a sumar a la nota generada, utilizando el potenciomentro de FINE (+10Hz), sobre la nota generada
#define IDE_FREQ_MAX_AD9833  12500000L  // Frecuencia maxima que puede generar el AD9833 ( 12.5MHz)


#define IDE_MAXV_POTENCIOMETROS 0x03FC  // Valor maximo leido desde los potenciomentros de COARSE y FINE
                                        // 1020, para eliminar los bits de menor peso y eliminar ruido

// ------------------------------------------------------------
//
// ------------------------------------------------------------

uint32_t tablaNotas[92] =  {      0L ,     0L ,     0L ,    0L   ,      0L , 44698L  , 47358L  , 50174L , 53164L , 56318L , 59676L ,  63219L,
                              66967L ,  70960L, 75179L , 79643L  ,  84375L , 89392L  , 94716L  ,100348L ,106309L ,112636L ,238664L , 252866L,
                             268000L , 283835L,300715L , 318572L , 337538L ,357608L  ,379000L  ,401392L ,425272L ,450544L ,477328L , 505732L,
                             536000L , 567670L,601430L , 637144L , 675076L ,715216L  ,758000L  ,802784L ,850544L ,901088L ,954656L ,1011464L,
                            1072000L ,1135340L,1202860L,1274288L ,1350152L ,1430432L ,1516000L ,1605568L,1701088L,1802176L,1909312L,2022928L,
                            2144000L ,2270680L,2405720L,2548576L ,2700304L ,2860864L ,3031000L ,3211136L,3402176L,3604352L,3818624L,4045856L,
                            4288000L ,4541360L,4811440L,5097152L ,5400608L ,5721728L ,6062000L ,6422272L,6804352L,7201000L,7637248L,8095000L,
                            8576000L ,9085000L,9626000L,10199000L,10806000L,11448000L,12129000L,1250000L
                           };
                         
uint32_t frq_Nota;     // Frecuencia cargada en el AD9833 para generar la nota recibida (algun valor de tablaNotas) 
uint32_t frq_Coarse;   // Frecuencia que se suma/resta a frq_Nota para crear el efecto de COARSE
uint32_t frq_Fine;     // Frecuencia que se suma/resta a frq_Nota para crear el efecto de FINE

int      vPotCoarse;        // Asociada a la lectura del potenciometro de COARSE
int      vPotFine;          // Asociada a la lectura del potenciometro de FINE
byte     vInterfaz;         // Valor cargado en el HC595 que controla los leds y permite leer los pulsadores  

// ------------------------------------------------------------
//
// ------------------------------------------------------------

MD_AD9833 AD_9833(IDE_HW_SPI_FSYNC); 



// ------------------------------------------------------------
//
// setup()
//
//
// ------------------------------------------------------------

void setup()
{
   pinMode(IDE_HW_PIN_LOAD_AUTO ,OUTPUT);
   pinMode(IDE_HW_PIN_LOAD_CLK  ,OUTPUT);
   pinMode(IDE_HW_PIN_LOAD_RESET,OUTPUT);
   pinMode(IDE_HW_PIN_LOAD_WR   ,OUTPUT);

   pinMode(IDE_HW_PIN_HC245     ,OUTPUT);

   pinMode(IDE_HW_PIN_SER       ,OUTPUT);
   pinMode(IDE_HW_PIN_LATCH_GEN ,OUTPUT);
   pinMode(IDE_HW_PIN_LATCH_LED ,OUTPUT);
   pinMode(IDE_HW_PIN_CLK       ,OUTPUT);

   pinMode(IDE_HW_SPI_FSYNC     ,OUTPUT);
   pinMode(IDE_HW_SPI_DATA      ,OUTPUT);
   pinMode(IDE_HW_SPI_CLK       ,OUTPUT);

   Serial.begin(9600);
   iniAD9833();

   vPotCoarse = 0;
   vPotFine   = 0;  
   vInterfaz  = 0B10000000;

   iniGenerador();
   setInterfaz();
   genOndaSinusoidal(); 
   setModoAutoLoad(IDE_MODO_AUTO); 
   
}



// ------------------------------------------------------------
//
// void loop()
//
// ------------------------------------------------------------
  
void loop()
{
  get_Coarse();            // Lee potenciometro COARSE
  get_Fine();              // Lee potenciomentro FINE
  get_Tecla_MIDI();        // Lee codigo de las teclas MIDI pulsadas, que envía el interfaz  de teclado 
//get_Pulsadores();        // Lee los pulsadores de seleccion de forma de onda 

}



// ------------------------------------------------------------
//
// void get_Coarse(void)
// 
// 
// ------------------------------------------------------------

void get_Coarse(void)
{
  int   vPot;
  float vAux;

  
  vPot = analogRead(IDE_HW_POT_COARSE) & IDE_MAXV_POTENCIOMETROS;

  if ( vPot!=vPotCoarse )
     {
       vAux       = IDE_FREQ_MAX_AD9833 - frq_Nota;
       vPotCoarse = vPot;  
       frq_Coarse = (uint32_t) map2(vPotCoarse,0,IDE_MAXV_POTENCIOMETROS,0,vAux);
       setFrqAD9833();
     }
}



// ------------------------------------------------------------
//
// void get_Fine(void)
// 
// 
// ------------------------------------------------------------

void get_Fine(void)
{
  int vPot;
  
    
  vPot = analogRead(IDE_HW_POT_FINE) & IDE_MAXV_POTENCIOMETROS;
  
  if ( vPot!=vPotFine )
     {
       vPotFine = vPot; 
       frq_Fine = (uint32_t)map2(vPotFine,0,IDE_MAXV_POTENCIOMETROS,0,IDE_FREQ_FINE);
       setFrqAD9833(); 
     }
}



// ------------------------------------------------------------
//
// void get_Tecla_MIDI(void)
// 
// 
// ------------------------------------------------------------

void get_Tecla_MIDI(void)
{

  if ( Serial.available() )
     {
       //   frq_Nota = Serial.parseFloat();
       //   AD_9833.setFrequency(MD_AD9833::CHAN_0, frq_Nota); 
       //   Serial.print(frq_Nota,DEC);
       //   Serial.println(" OK");
     }
}



// ------------------------------------------------------------
//
// void get_Pulsadores(void)
// 
// 
// ------------------------------------------------------------

void get_Pulsadores(void)
{
  int v;
  
  
  v = analogRead(IDE_HW_INPUT_KEYS);
  v = map(v,0,1023,0,1);
  Serial.println(v);
  
}



// ------------------------------------------------------------
// void setInterfaz(void)
// Carga el valor de vInterfaz en el HC595 que controla los led
// y  el  direccionamiento  del  4051  con  el  que se leen los
// pulsadores 
// ------------------------------------------------------------

void setInterfaz(void)
{
  shiftOut(IDE_HW_PIN_SER, IDE_HW_PIN_CLK, MSBFIRST,vInterfaz); // Carga el dato
  digitalWrite(IDE_HW_PIN_LATCH_LED,HIGH);                      // pulso de Latch
  digitalWrite(IDE_HW_PIN_LATCH_LED,LOW);  
}



// ------------------------------------------------------------
//
// void iniGenerador()
// Instrucciones en ese orden
// 
// ------------------------------------------------------------

void iniGenerador(void)
{
  
  setModoAutoLoad(IDE_MODO_LOAD);
  
  digitalWrite(IDE_HW_PIN_LOAD_CLK,HIGH);
  digitalWrite(IDE_HW_PIN_LOAD_WR ,HIGH);
  
  resetContadorADDR();  
  
}



// ------------------------------------------------------------
//
// setModoAutoLoad(byte modo)
// modo: IDE_MODO_LOAD Cargar datos en el buffer 6116
//       IDE_MODO_AUTO Generacion de onda 
// ------------------------------------------------------------

void setModoAutoLoad(byte modo)
{
  if ( modo==IDE_MODO_LOAD )
     { digitalWrite(IDE_HW_PIN_LOAD_AUTO ,HIGH);
       digitalWrite(IDE_HW_PIN_HC245     ,HIGH);
     }
  else
     { digitalWrite(IDE_HW_PIN_LOAD_AUTO ,LOW);
       digitalWrite(IDE_HW_PIN_HC245     ,LOW);
     }
}



// ------------------------------------------------------------
//
// resetContadorADDR(void)  
// Resetea el contador de direcciones (4040) que direcciona el
// buffer de memoria formado por los 6116
// PREVIAMENTE tiene que estar seleccionado el modo IDE_MODO_LOAD
// sino no se resetea el 4040
// ------------------------------------------------------------

void resetContadorADDR(void)
{
  digitalWrite(IDE_HW_PIN_LOAD_RESET ,HIGH);
  delayMicroseconds(IDE_DELAY_RESET_ADDR);
  digitalWrite(IDE_HW_PIN_LOAD_RESET ,LOW);
}



// ------------------------------------------------------------
//
// clkContadorADDR(void)
// Genera un pulso de reloj en el contador de direcciones 4040
// para que avance uno la direccion
// PREVIAMENTE tiene que estar seleccionado el modo IDE_MODO_LOAD
// sino no se resetea el 4040
// ------------------------------------------------------------

void clkContadorADDR(void)
{
  digitalWrite(IDE_HW_PIN_LOAD_CLK,LOW);
  digitalWrite(IDE_HW_PIN_LOAD_CLK,HIGH);
}



// ------------------------------------------------------------
//
// cargarDatoMemoria(void)
// Genera el pulso de escritura en las memorias 6116 que almacena 
// el valor que tenga en ese momento el registro formado por los
// HC595.
// Lo almacena el la direccion de memoria apuntada en las salidas
// del 4040
// ------------------------------------------------------------

void cargarDatoMemoria(void)
{
  digitalWrite(IDE_HW_PIN_LOAD_WR ,LOW);
  digitalWrite(IDE_HW_PIN_LOAD_WR ,HIGH);
}



// ------------------------------------------------------------
//
// void cargarDatoBuffer(unsigned int data)
// Carga el valor que recibe en el registro formado por los dos
// HC595
// ------------------------------------------------------------

void cargarDatoBuffer(unsigned int data)
{
  byte pH;
  byte pL;
  
  pH = (data >> 8 & 0x00FF) | 0B00000100;
  pL = data      & 0x00FF;
  shiftOut(IDE_HW_PIN_SER, IDE_HW_PIN_CLK, MSBFIRST,pH ); // Parte Alta
  shiftOut(IDE_HW_PIN_SER, IDE_HW_PIN_CLK, MSBFIRST,pL);  // Parte Baja
  digitalWrite(IDE_HW_PIN_LATCH_GEN,HIGH);                     // pulso de Latch
  digitalWrite(IDE_HW_PIN_LATCH_GEN,LOW);  
  
}



// ------------------------------------------------------------
//
// void iniAD9833(void)
// 
// ------------------------------------------------------------

void iniAD9833(void)
{
 
  frq_Nota   = IDE_FREQ_DEFECTO; 
  frq_Coarse = 0L;
  frq_Fine   = 0L;
  
  AD_9833.begin();
  AD_9833.setMode(MD_AD9833::MODE_SQUARE1);
  setFrqAD9833();
}



// ------------------------------------------------------------
//
// void setFrqAD9833(void)
// 
// ------------------------------------------------------------

void setFrqAD9833(void)
{
  uint32_t frecuencia;
  
  frecuencia = frq_Nota + frq_Coarse + frq_Fine;

  if ( frecuencia<=IDE_FREQ_MAX_AD9833 )
     { // ---------------------------------------------------
       // Frecuencia valida
       // ---------------------------------------------------
       AD_9833.setFrequency      (MD_AD9833::CHAN_0, frecuencia);
       AD_9833.setActiveFrequency(MD_AD9833::CHAN_0);
     }
}



// ------------------------------------------------------------
//
// float map2( float x       , 
//             float in_min  ,
//             float in_max  ,
//             float out_min ,
//             float out_max
//           )
// Version de la funcion map de Arduino pero con floats
// ------------------------------------------------------------

float map2(float x, float in_min, float in_max, float out_min, float out_max)
{
  float a;
  float b;
  
  a = (x - in_min) * (out_max - out_min);
  b = (in_max - in_min) + out_min;
  
  return (float)a/b;
}

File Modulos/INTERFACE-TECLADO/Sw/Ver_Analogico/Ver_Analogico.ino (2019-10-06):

// ---------------------------------------------------------
//
// Proyecto:       Formant_V2
// Version:        1.0
// Fichero:        Ver_Analogico.ino
//
//                 Version para Hardware de interfaz analogico
//                 de teclado ( array de resistencias original
//                 del formant)
// Autor:   
// Hardware:       Arduino Nano V3.0
// Fecha:          Junio 2017
//
// Funcionalidad:  Fichero principal ( main ) de la aplicación
//                 de control del interfaz MIDI de teclado.
//
// Notas:          REVISADO --        
//
// ---------------------------------------------------------

#include <Arduino.h>
#include <EEPROM.h>
#include <stdlib.h>
#include "Formant_V2_MIDI.h"
#include "Formant_Teclado.h"




// ------------------------------------------------------------
//
//
//
//
// ------------------------------------------------------------


ARDUINO_MIDI c_MIDI;                               // Variable para manejar los datos MIDI
byte         canalID;                              // Canal MIDI asignado al Formant V2
byte         modoF;                                // Modo de funcionamniento: TEST/Normal

                                                   // ------------------------------------------------------------
byte         tab_TeclasEstado[IDE_MAX_TECLA_ID+1]; // Tabla con el estado de cada  tecla , esta  tabla  se utiliza 
                                                   // para controlar el estado de cada tecla (pulsada o sin pulsar)
                                                   // Cada posicion en esta  tabla  almacena el estado de la tecla
                                                   // correspondiente, por ejemplo el estado de la  tecla MIDI con
                                                   // el codigo 27 se almacena en tab_TeclasEstado[27] etc
                                                   // Estados posibles:
                                                   // . IDE_TECLA_ESTADO_OFF, Tecla SIN pulsar
                                                   // . IDE_TECLA_ESTADO_ON,  Tecla pulsada
                                                   //
                                                   // Los codigos MIDI de las teclas reconocidas se  fijan con los 
                                                   // defines:
                                                   //  #define IDE_MIN_TECLA_ID codigo MIDI de la tecla mas baja
                                                   //  #define IDE_MAX_TECLA_ID codigo MIDI de la tecla mas alta
                                                   // Se dimensiona  1  mas  porque  el valor de tecla mas alto es  
                                                   // IDE_MAX_TECLA_ID incluido
                                                   // ------------------------------------------------------------

byte volumenManualGeneral;                         // valor del potenciometro que fija el volumen general del Formant, en modo manual



// ------------------------------------------------------------
//
// setup()
//
//
// ------------------------------------------------------------

void setup()
{
   pinMode(IDE_HW_PIN_CLOCK,OUTPUT);
   pinMode(IDE_HW_PIN_DATA ,OUTPUT);
   pinMode(IDE_HW_PIN_LATCH,OUTPUT);
   
   pinMode(IDE_HW_PIN_LED_TECLA_ON,OUTPUT);
   
   pinMode(IDE_HW_PIN_GATE,OUTPUT);
   
   pinMode(IDE_HW_CANAL_ID_0,INPUT);
   pinMode(IDE_HW_CANAL_ID_1,INPUT);
   pinMode(IDE_HW_CANAL_ID_2,INPUT);
   pinMode(IDE_HW_CANAL_ID_3,INPUT);
   
   pinMode(IDE_HW_PIN_TEST,INPUT);
          
   analogWrite(IDE_HW_PIN_VOLCOM_DATA ,0);
   analogWrite(IDE_HW_PIN_VOLCOM_RESET,0);
   analogWrite(IDE_HW_PIN_VOLCOM_CLOCK,0);

   volumenManualGeneral = 0;
     
   set_CodigoTecla(1);
   set_GATE(LOW);
   set_LedTeclaOn(LOW);
   get_CanalID();

   c_MIDI.begin(canalID);      // IMPORTANTE: Imprescindible llamar antes de usar la clase MIDI
                               //             . Programa el puerto serie con la velocidad MIDI
                               //             . Inicilaliza la clase
                               //             . La  clase  DEBE  recibir  el  canalID  asignado al 
                               //               interfaz por eso se llama DESPUES de get_canalID()        

      
   iniTabTeclasEstado();

   modoF = digitalRead(IDE_HW_PIN_TEST);
   if ( modoF==LOW )  
      { // ------------------------------------------------------------
        // Entrar en modo TEST
        // ------------------------------------------------------------
        modoTest(); 
      }
     
}



// ------------------------------------------------------------
//
// void loop()
//
// ------------------------------------------------------------
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

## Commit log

2017-06-26 Actualizacion HW Teclado
    [Formant_V2_Teclado.kicad_pcb, Formant_V2_Teclado.sch]
2017-07-01 Actualizacion SW Teclado
    [Formant_V2_Teclado.sch]
2017-08-07 Actualizacion HW
    [Formant_V2_Teclado.kicad_pcb, Formant_V2_Teclado.sch]
2017-08-10 Actualizacion SW completa
    [Formant_V2_Teclado.sch]
2017-08-16 Informacion COM
    [Formant_V2_COM.kicad_pcb, Formant_V2_COM.sch, Formant_V2_Teclado.sch]
2017-08-17 Actualizacion SW MIDI Volumen
    [Formant_V2_Teclado.sch]
2017-08-18 Actualizacion DOC
    [Formant_V2_Teclado.sch]
2017-08-21 Actualizacion Documentacion
    [Formant_V2_COM.sch, Formant_V2_Teclado.sch]
2017-09-04 Actualizacion DOC/HW
    [Formant_V2_Teclado.sch]
2017-09-07 Actualizacion HW VCO
    [Formant_V2_VCO.kicad_pcb, Formant_V2_VCO.sch]
2017-10-04 Creacion de Caratulas
2017-10-06 Reorganizacion General del GIT
    [Formant_V2_COM.kicad_pcb, Formant_V2_COM.sch, Formant_V2_Guia_6U.FCStd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]
2017-10-09 Actualizacion Mueble
    [Formant_V2_Mueble.FCStd]
2017-10-10 Info Caratulas
    [xx.stl]
2017-10-24 Actualizacion Doc Mueble
    [Formant_V2_Mueble.FCStd]
2017-11-12 Actualizacion HW ADSR
    [Formant_V2_ADSR.kicad_pcb, Formant_V2_ADSR.sch]
2017-11-14 Actualiazacion HW ADSR
    [Formant_V2_ADSR.sch]
2017-11-19 Actualizacion Piezas
    [Formant_V2_Guia_3U.FCStd]
2017-11-20 Reorganizacion de Documentacion
2017-12-10 Actualizacion Interfaz Teclado
    [Formant_V2_Teclado.sch]
2017-12-12 Actualizacion Teclado
    [Formant_V2_Teclado.sch]
2017-12-31 Actualizacion ADSR
    [Formant_V2_ADSR.sch]
2019-10-20 Actualizacion modulos VCO y ADSR
    [Formant_V2_ADSR.sch, Formant_V2_VCO_CEM3340.sch]
